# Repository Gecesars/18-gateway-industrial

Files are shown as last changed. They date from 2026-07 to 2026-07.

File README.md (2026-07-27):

# EDGE-18 — Gateway Industrial Modbus/CAN Universal

Plataforma-pai para aquisição industrial e telemetria dos demais projetos do
portfólio. O EDGE-18 lê Modbus RTU, quatro sinais 0–10 V/4–20 mA e quatro
entradas digitais/pulso, conserva dados offline e publica por MQTT/TLS.

> **Estado: revisão digital A congelada para documentação — não fabricar.**
> O esquemático passa no ERC, mas a PCB foi mantida no ponto solicitado pelo
> responsável: 43 ocorrências de DRC e 24 conexões abertas. Os arquivos servem
> para revisão de engenharia e continuidade do desenvolvimento; não constituem
> uma liberação fabril, protótipo validado ou produto certificado.

## Arquitetura P0

| Bloco | Seleção |
|---|---|
| MCU | STM32H563ZIT6, Cortex-M33/TrustZone |
| Ethernet | LAN8742Ai, RMII 10/100 |
| Wi-Fi | ESP32-C3-MINI-1 opcional |
| RS-485 | 2 × ISOW1412 isoladas |
| Analógicas | ADS8684, quatro canais de 16 bits |
| Digitais | 2 × ISO1212, quatro entradas de 24 V |
| CAN | ISO1042 reservado para fase 2 |
| Alimentação | 9–36 Vcc; LM76002 como referência |
| PCB | 180 × 120 mm, quatro camadas |

O MVP é somente de monitoramento. Não possui saídas de comando e não substitui
CLP ou relé de segurança.

## Entregue nesta revisão

- requisitos verificáveis e seis ADRs;
- esquemático KiCad A0 com sete blocos e ERC limpo;
- PCB KiCad de quatro camadas, 180 × 120 mm, com roteamento parcial congelado;
- trilhas de 0,25 a 1,20 mm, sem segmento abaixo de 0,25 mm;
- BOM de 181 posições, pinout de 144 pinos e cálculos elétricos;
- STEP atual da PCB e conjunto paramétrico FreeCAD;
- relatório DRC integral com as pendências conhecidas;
- arquitetura elétrica e de software;
- contratos de configuração e telemetria em JSON Schema;
- exemplos válidos;
- núcleo C17 testável com configuração, Modbus, scheduler, journal, telemetria,
  máquina de estados e manifesto de atualização;
- testes estritos no host e CI;
- quinze vistas técnicas e PDF consolidado.

## Evidência CAD — 15 vistas

Os recortes do esquemático foram exportados em alta resolução e ampliados por
bloco para preservar referências, valores e nomes de redes. As vistas da PCB
mostram deliberadamente o estado congelado, inclusive o roteamento ainda
incompleto.

| | | |
|---|---|---|
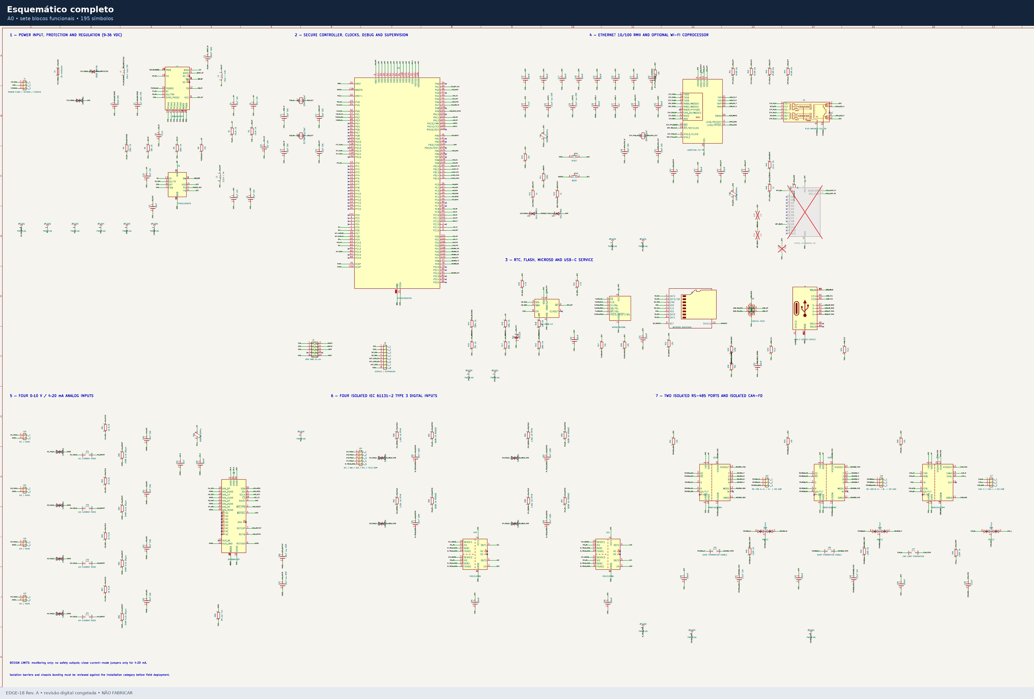
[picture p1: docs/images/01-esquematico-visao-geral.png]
Esquemático completo
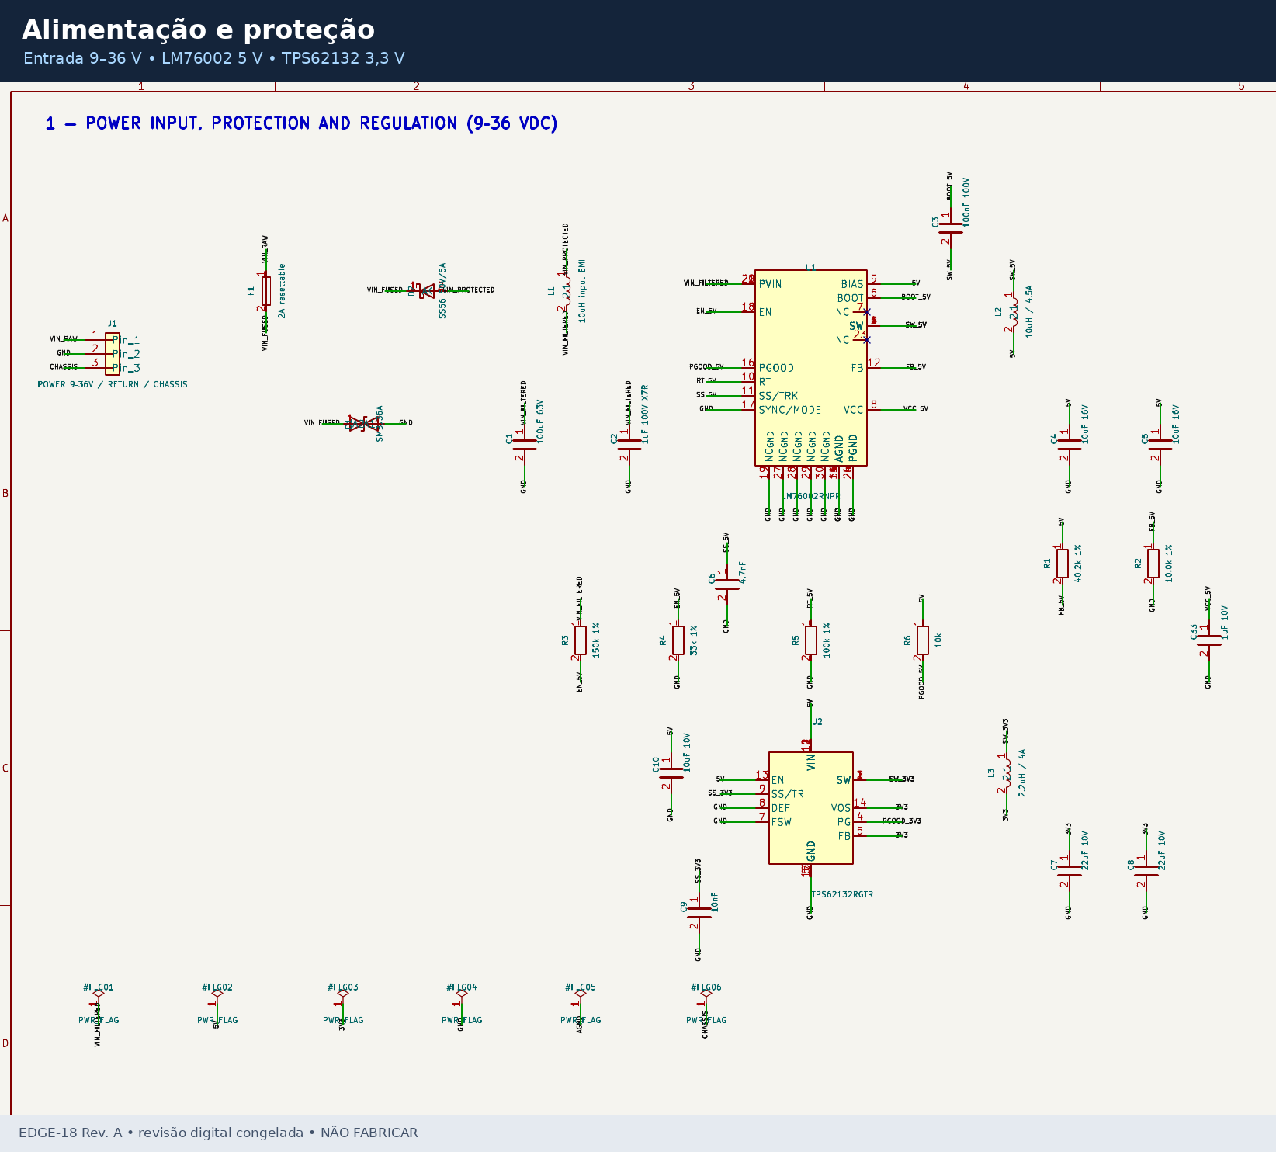
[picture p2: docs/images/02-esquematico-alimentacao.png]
Alimentação
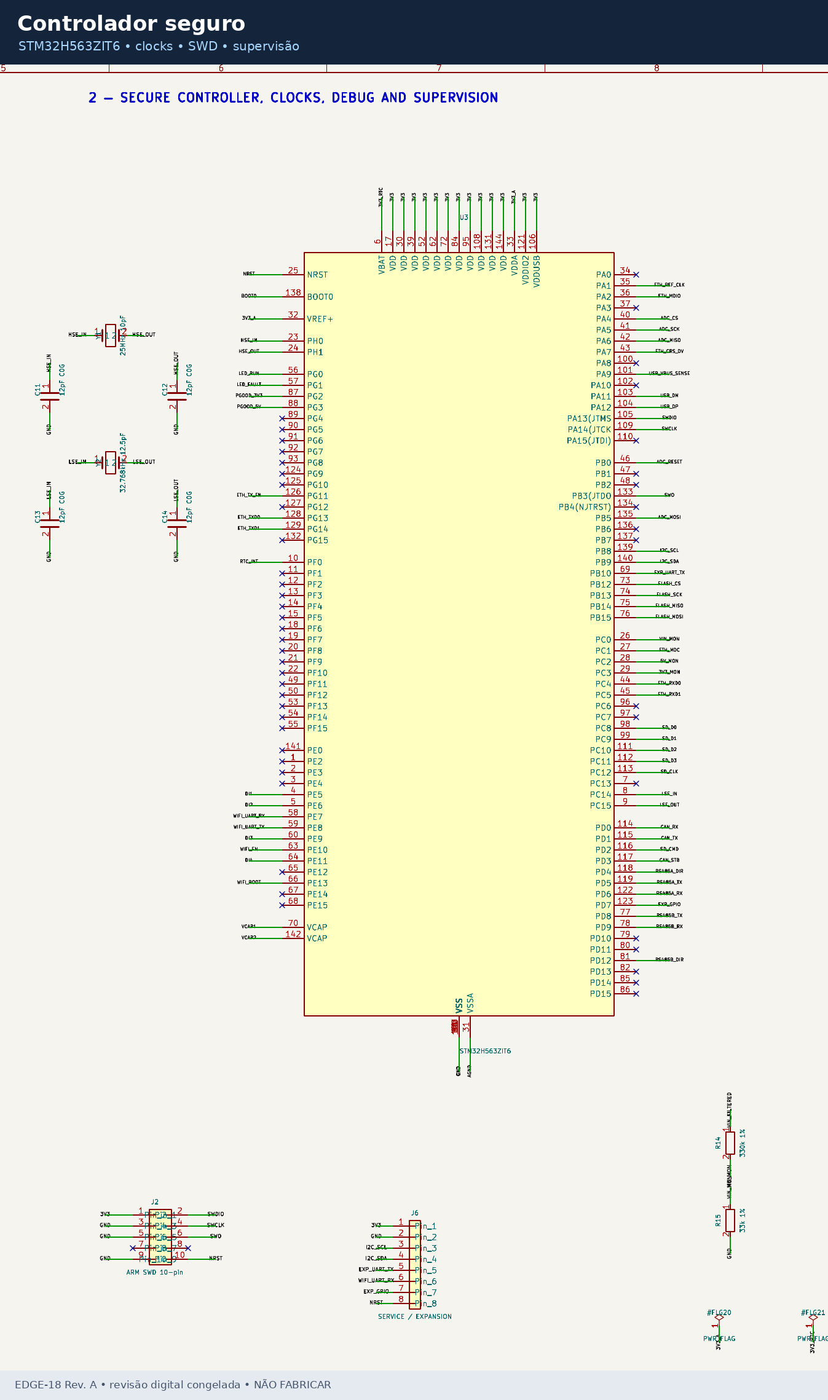
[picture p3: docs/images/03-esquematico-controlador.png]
Controlador
|  |  |  |
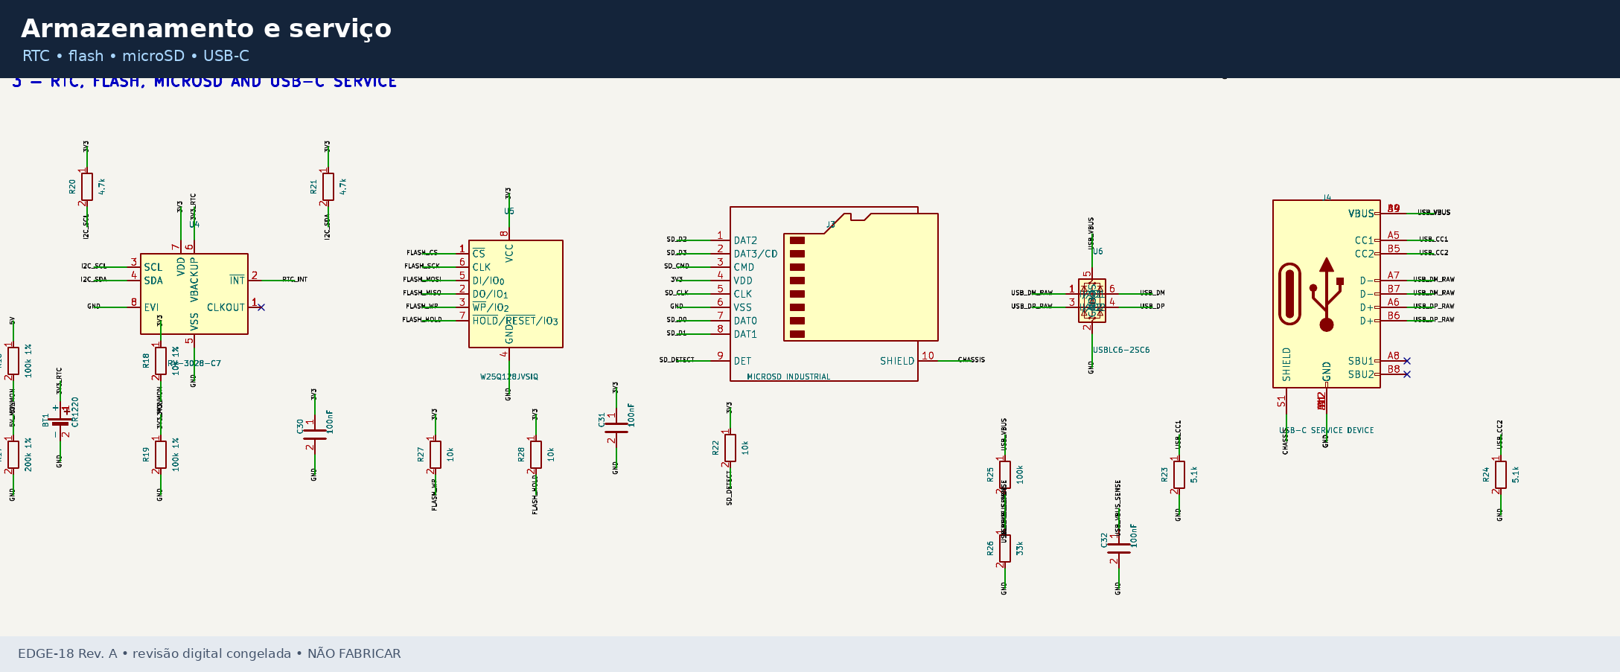
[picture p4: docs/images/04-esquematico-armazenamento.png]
Armazenamento
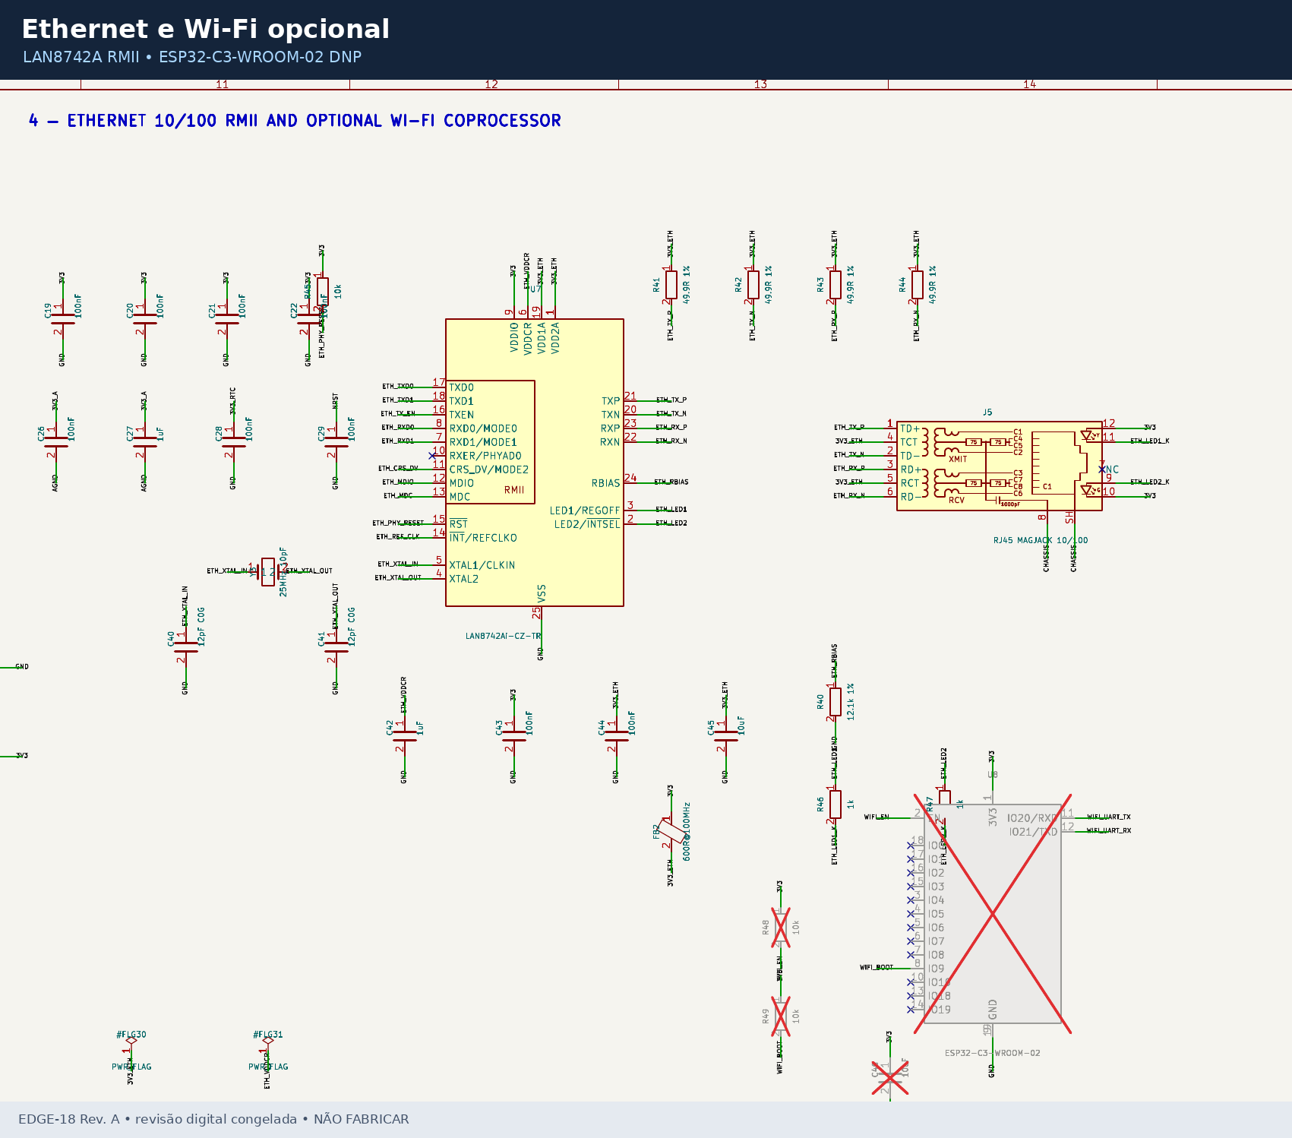
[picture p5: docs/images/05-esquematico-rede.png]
Rede
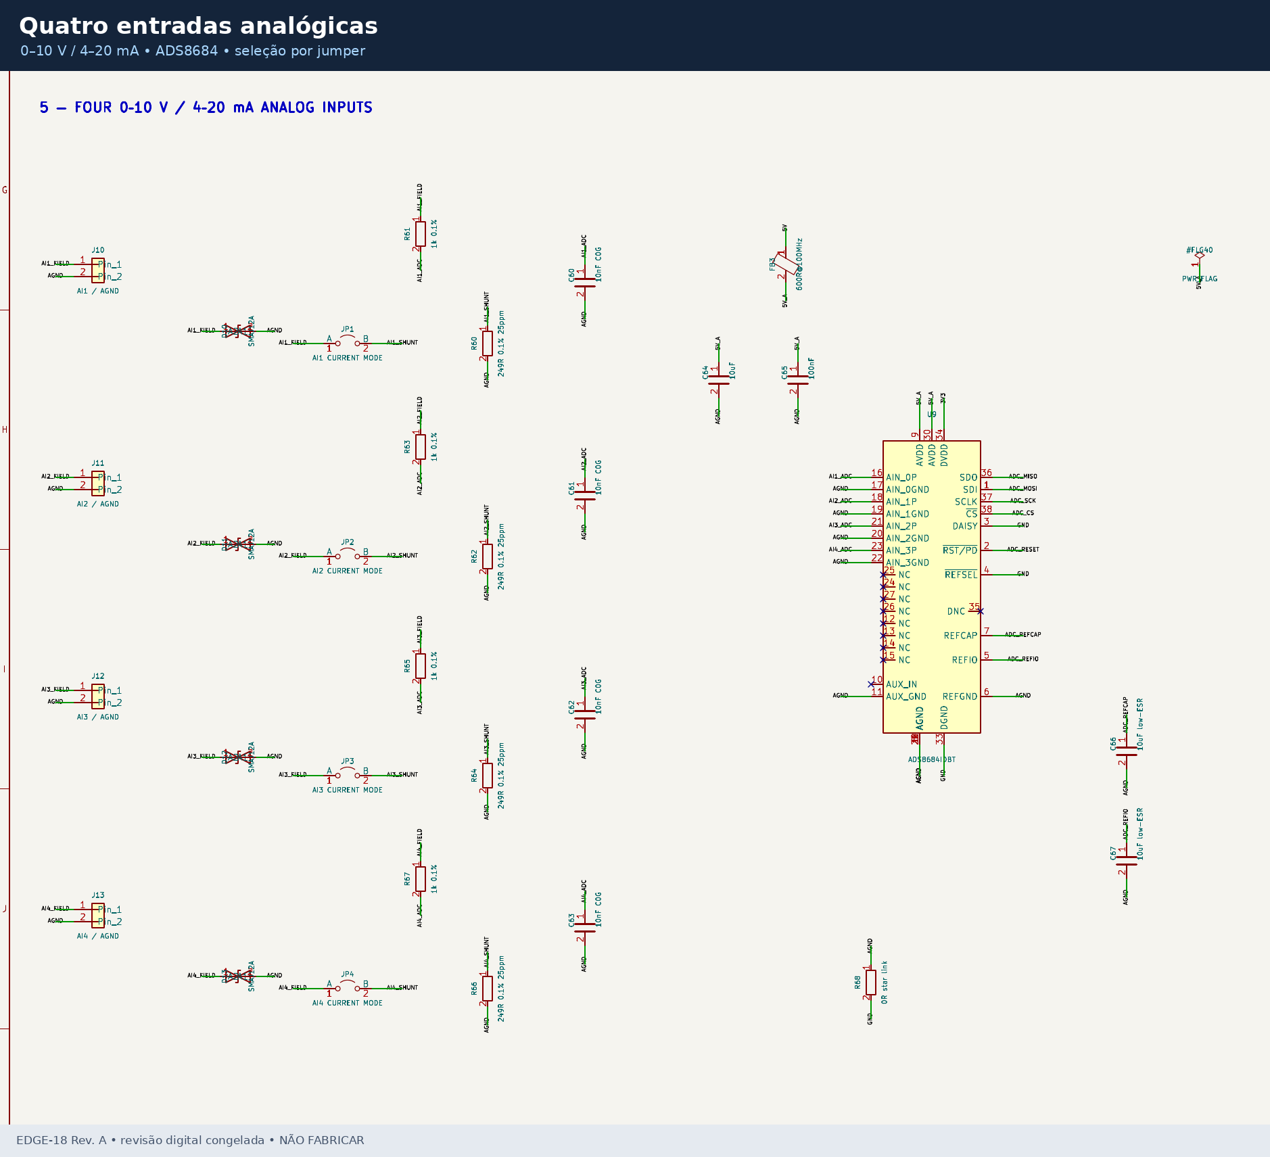
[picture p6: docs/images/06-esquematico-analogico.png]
Entradas analógicas
|  |  |  |
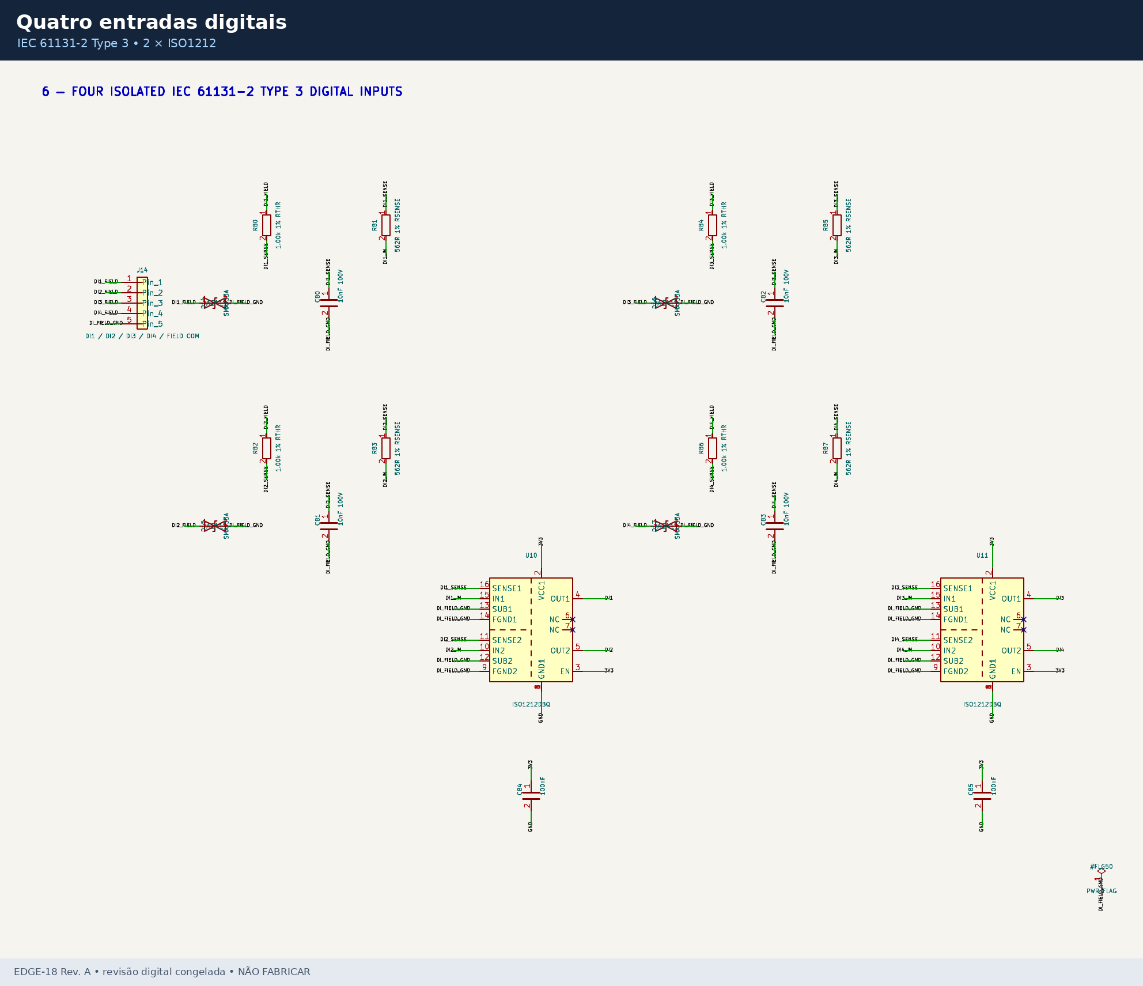
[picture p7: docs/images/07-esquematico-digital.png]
Entradas digitais
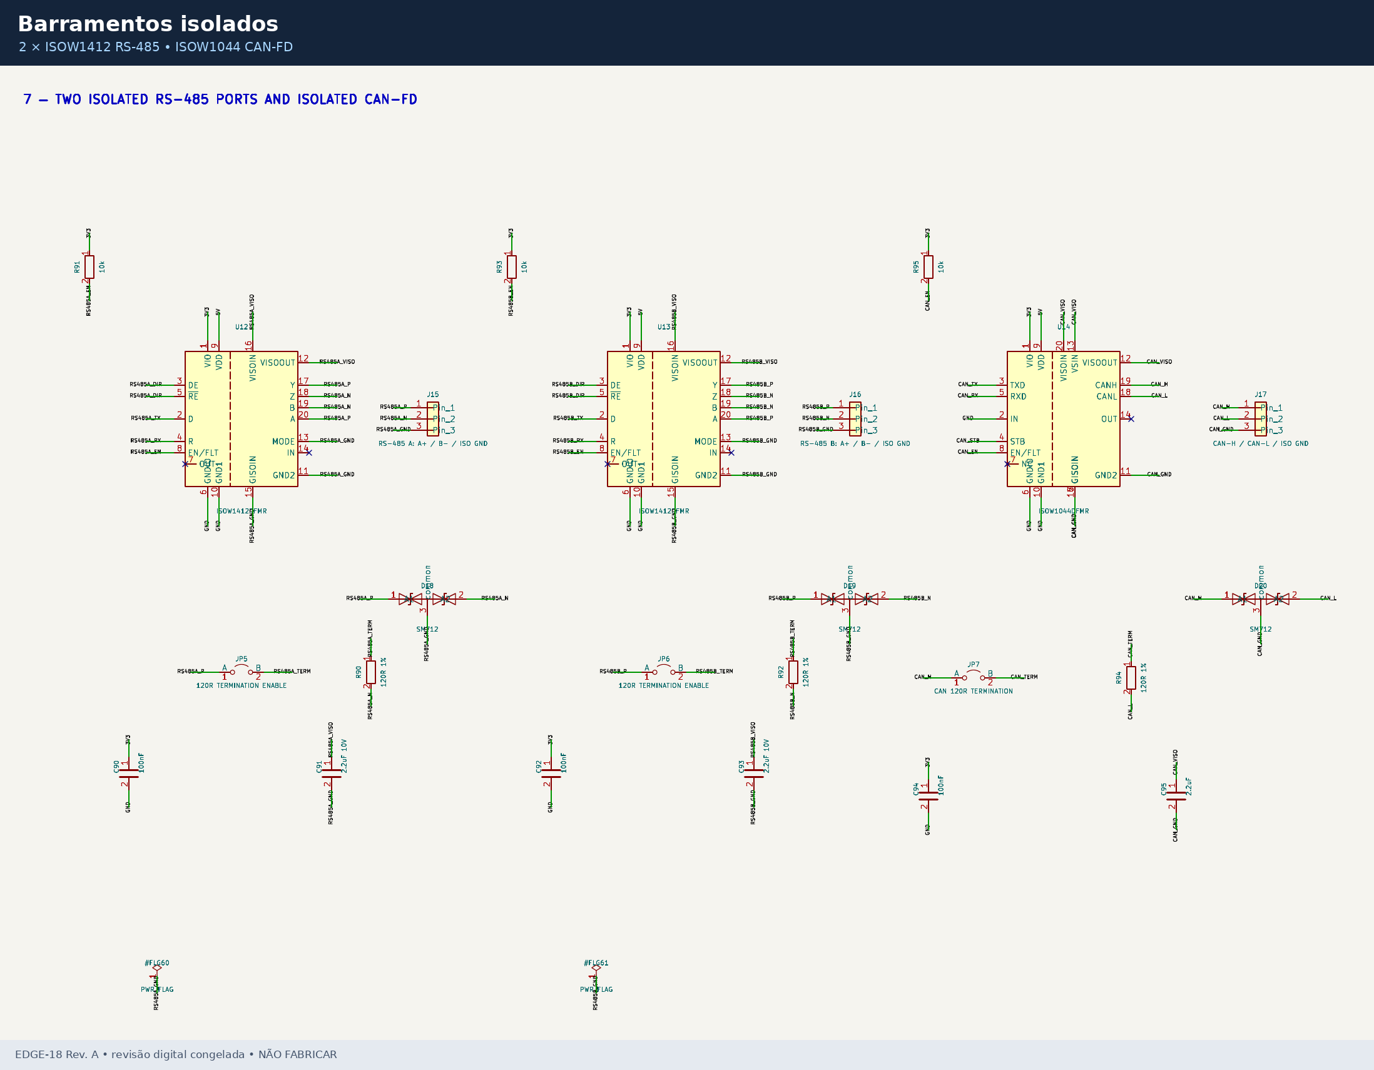
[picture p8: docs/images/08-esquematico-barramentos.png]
Barramentos isolados
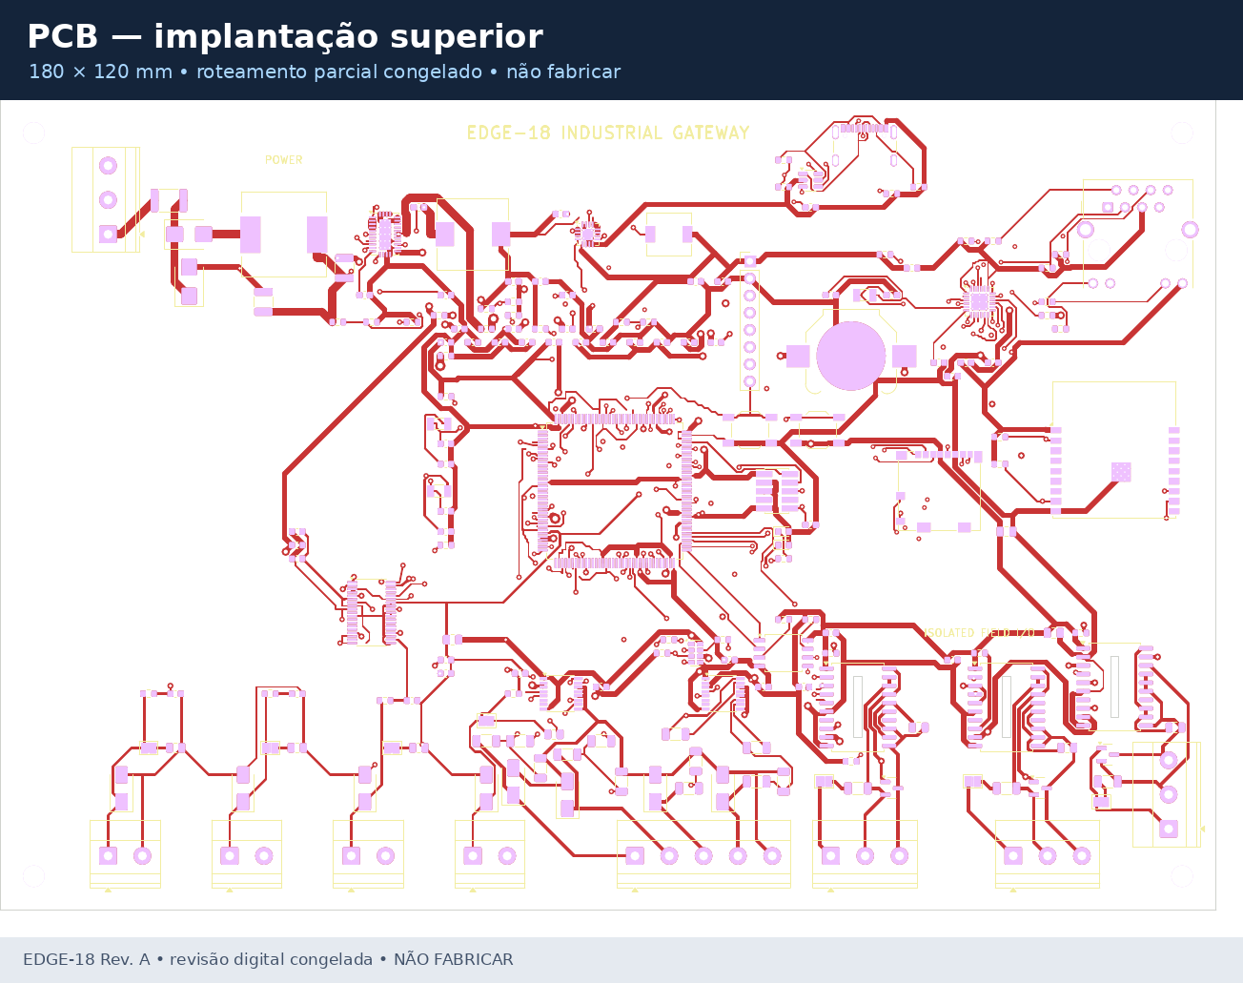
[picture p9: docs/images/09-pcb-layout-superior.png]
Implantação superior
|  |  |  |
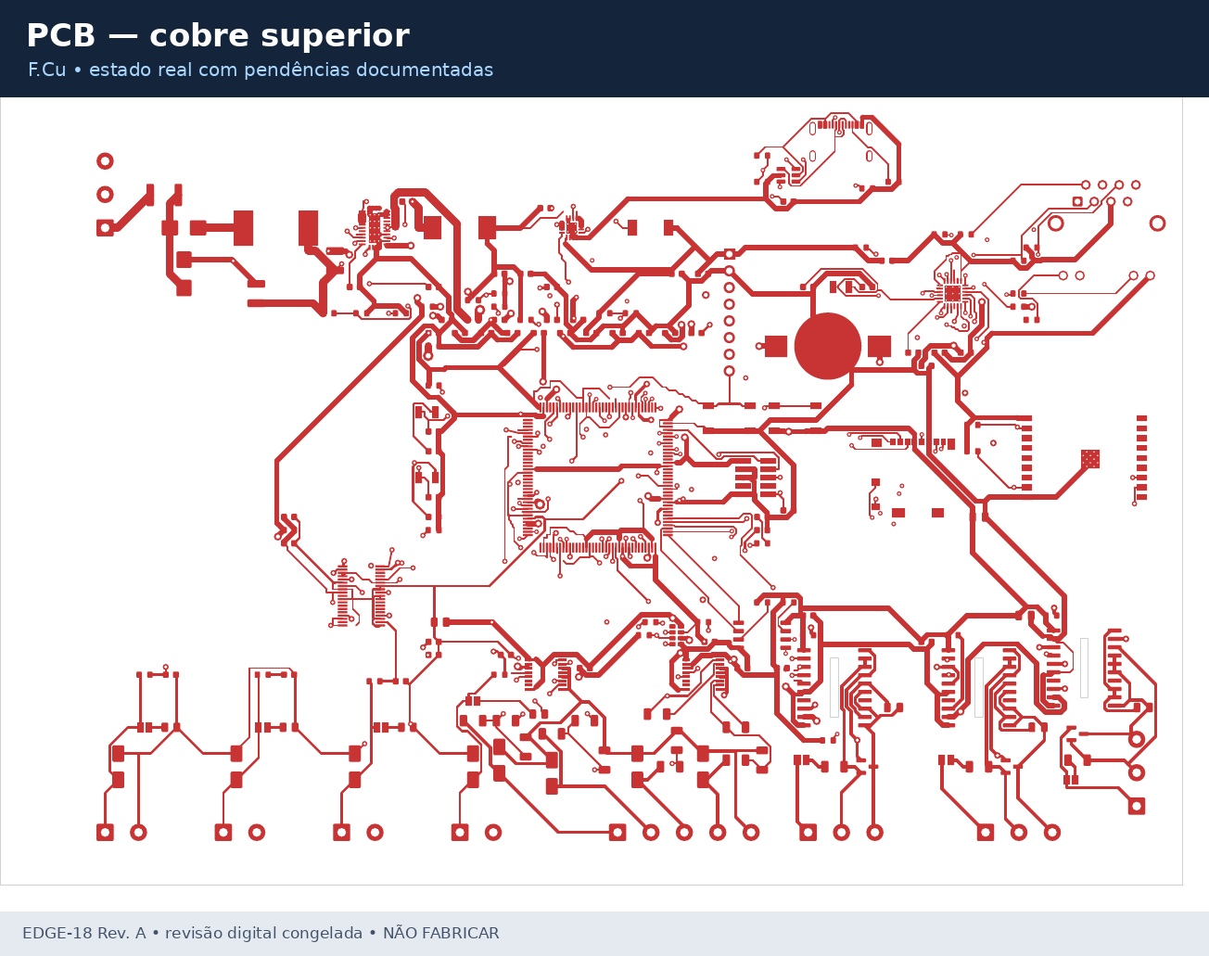
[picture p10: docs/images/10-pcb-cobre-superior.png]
Cobre superior
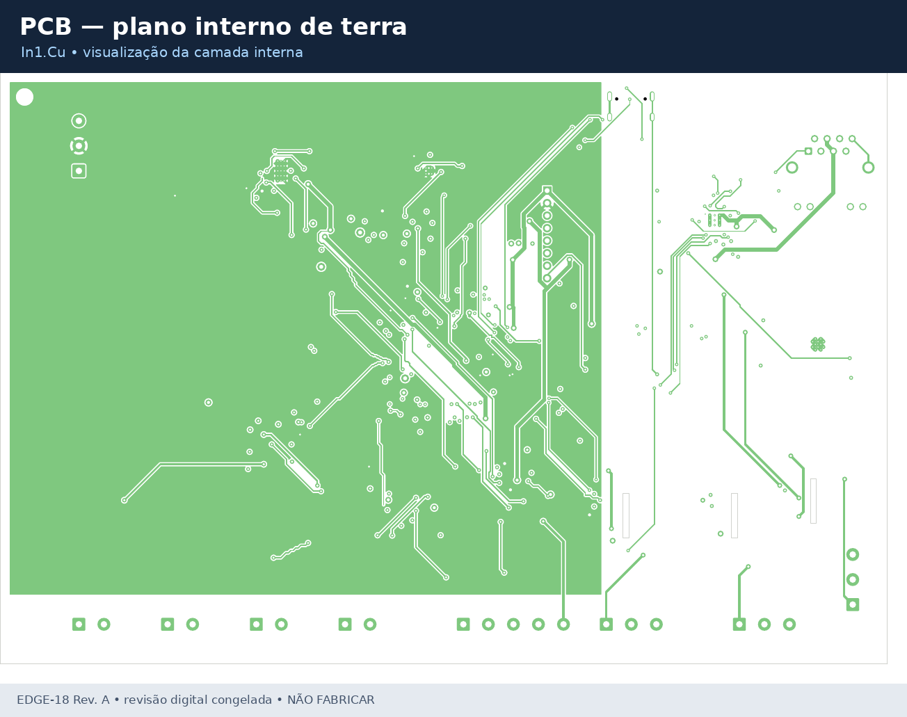
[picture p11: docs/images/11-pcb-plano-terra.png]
Plano interno de terra
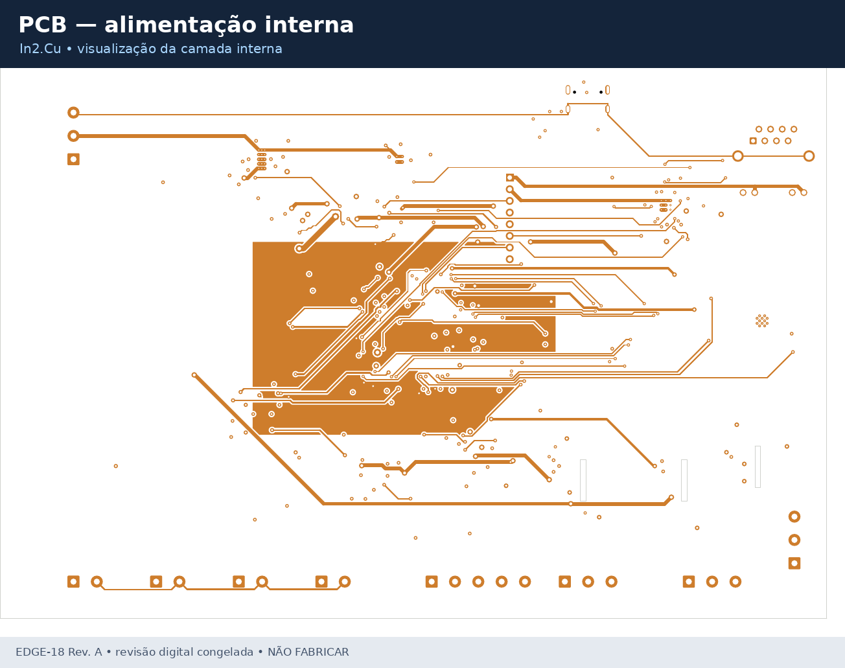
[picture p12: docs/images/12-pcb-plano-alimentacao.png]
Plano interno de alimentação
|  |  |  |
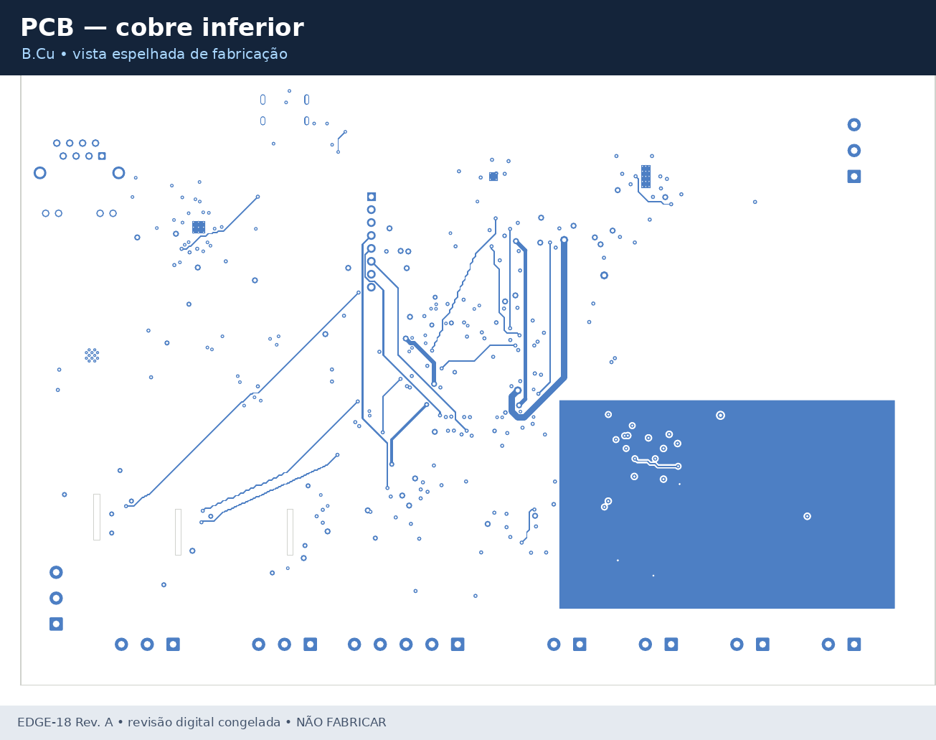
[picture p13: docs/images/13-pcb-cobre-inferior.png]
Cobre inferior
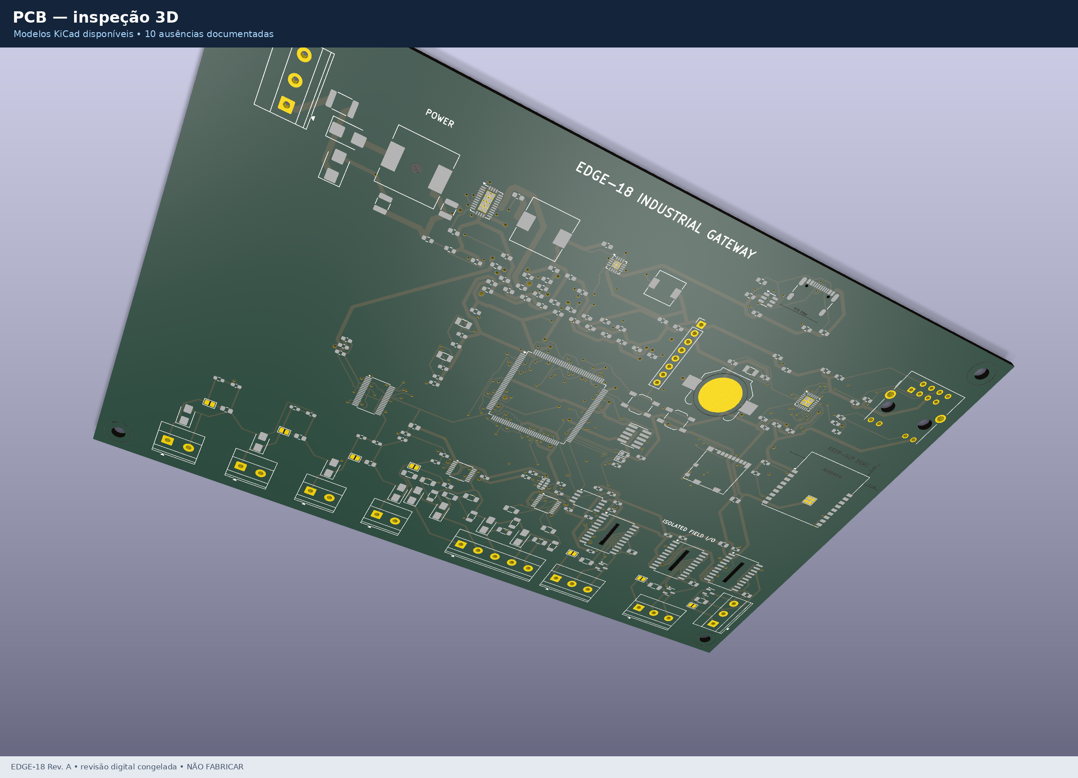
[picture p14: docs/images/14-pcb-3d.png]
PCB em 3D
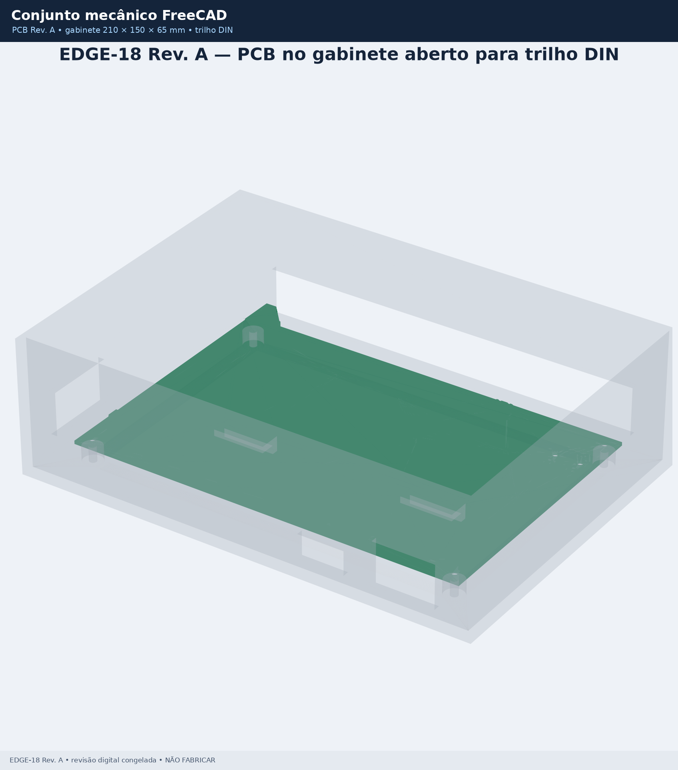
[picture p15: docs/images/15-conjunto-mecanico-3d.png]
Conjunto mecânico
|  |  |  |

Documento consolidado: [EDGE-18 — projeto completo Rev. A](docs/EDGE-18-projeto-completo-rev-a.pdf).

## Verificação local

```bash
./tools/run-checks.sh
```

## Navegação

- [índice técnico](docs/README.md);
- [requisitos](docs/01-requisitos.md);
- [arquitetura](docs/02-arquitetura.md);
- [hardware](docs/03-hardware.md);
- [software](docs/04-software.md);
- [estado congelado da PCB Rev. A](docs/17-estado-da-pcb-rev-a.md);
- [relatório ERC](docs/reports/edge18-main-rev-a-erc.rpt);
- [relatório DRC](docs/reports/edge18-main-rev-a-drc.rpt);
- [fontes primárias](docs/12-fontes-primarias.md);
- [status](project-management/STATUS.md);
- [roadmap](project-management/ROADMAP.md).

## Licença

A licença ainda não foi definida. Não redistribua artefatos como se uma licença
já tivesse sido concedida.

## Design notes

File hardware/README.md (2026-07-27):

# Hardware

## Finalidade

Fontes de eletrônica do projeto.

## Entregáveis Rev. A

- `edge18-main/edge18-main-rev-a.kicad_sch`: esquemático A0 com sete blocos;
- `edge18-main/edge18-main-rev-a.kicad_pcb`: PCB 180 × 120 mm, quatro camadas;
- `libraries/frozen/`: símbolos resolvidos e congelados para ERC reprodutível;
- `bom/edge18-main-rev-a-source.csv`: 181 posições e quatro DNP;
- `scripts/generate_kicad.py`: fonte determinística de esquemático, PCB inicial
  e BOM;
- `scripts/generate_pinout.py`: tabela dos 144 pinos extraída do CAD;
- `scripts/specctra_io.py`: intercâmbio DSN/SES;
- relatórios ERC/DRC em `docs/reports/`.

## Regras principais

- trilha mínima global: 0,25 mm;
- padrão: 0,30 mm; analógico: 0,35 mm; campo: 0,50 mm;
- alimentação: 0,80 mm; VIN: 1,20 mm;
- quatro camadas: F.Cu, In1.Cu, In2.Cu e B.Cu;
- três rasgos sob as barreiras isoladas;
- ESP32-C3-WROOM-02 marcado DNP;
- nenhuma saída de controle de processo.

## Estado congelado

A PCB Rev. A foi congelada em 27 de julho de 2026 com 43 ocorrências de DRC e
24 conexões abertas, por decisão do responsável. Não retome o roteamento nem
gere arquivos fabris a partir desta baseline sem nova autorização. O
esquemático tem ERC limpo e não há trilha abaixo de 0,25 mm.

Detalhes: [`../docs/17-estado-da-pcb-rev-a.md`](../docs/17-estado-da-pcb-rev-a.md).

## Regeneração e validação de desenvolvimento

```bash
./tools/generate-hardware.sh
./tools/kicad-cli.sh sch erc \
  --exit-code-violations hardware/edge18-main/edge18-main-rev-a.kicad_sch
./tools/kicad-cli.sh pcb drc \
  --exit-code-violations hardware/edge18-main/edge18-main-rev-a.kicad_pcb
```

`generate-hardware.sh` substitui o PCB pelo posicionamento inicial; execute o
roteamento depois dele somente em uma futura linha de desenvolvimento
autorizada. `--schematic-only` atualiza esquemático, BOM e bibliotecas sem tocar
na PCB congelada; `--bom-only` atualiza somente a BOM.

## Limite da liberação

O ERC está limpo, mas o DRC não está. A revisão atual não pode ser fabricada.
Protótipo, DFM, bring-up, térmica, surto, EMC e isolamento também continuam
pendentes.

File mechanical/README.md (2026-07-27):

# Mecânica EDGE-18

## Rev. A digital

- gabinete: 210 × 150 × 65 mm;
- PCB: 180 × 120 × 1,6 mm;
- quatro pontos de fixação M3;
- tampa removível;
- aberturas para Ethernet, USB, alimentação e terminais;
- dois adaptadores inferiores para trilho DIN;
- importação do STEP real da PCB quando o pacote de release está presente;
- volumes funcionais para fonte, analógicas, digitais, MCU, barramentos,
  Ethernet e keep-out da antena.

Fontes:

- `source/generate_edge18_enclosure.py`;
- `source/validate_edge18_enclosure.py`;
- `native/edge18-rev-a-assembly.FCStd`;
- `step/edge18-main-rev-a.step` (exportação da PCB KiCad congelada);
- `step/edge18-rev-a-*.step`.

Regeneração:

```bash
./tools/generate-mechanical.sh
```

O modelo confere envelope, fixações, recortes e conjunto PCB/gabinete. Parafusos,
torques, junta, grau IP, dissipação e desenho de oficina dependem do protótipo e
do processo de fabricação escolhido.

Dez referências de modelos 3D não estão disponíveis na biblioteca KiCad local
e são omitidas na exportação atual. A lista e o impacto estão documentados em
[`../docs/17-estado-da-pcb-rev-a.md`](../docs/17-estado-da-pcb-rev-a.md).

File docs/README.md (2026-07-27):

# Índice documental — Projeto 18

1. [Proposta de origem](00-proposta.md)
2. [Requisitos](01-requisitos.md)
3. [Arquitetura](02-arquitetura.md)
4. [Hardware](03-hardware.md)
5. [Software](04-software.md)
6. [Interfaces e dados](05-interfaces-e-dados.md)
7. [Segurança e conformidade](06-seguranca-e-conformidade.md)
8. [Verificação e validação](07-verificacao-e-validacao.md)
9. [Fabricação e implantação](08-fabricacao-e-implantacao.md)
10. [Operação e manutenção](09-operacao-e-manutencao.md)
11. [Controle documental](10-controle-documental.md)
12. [Reutilização pelos projetos filhos](11-reutilizacao.md)
13. [Fontes primárias e seleção](12-fontes-primarias.md)
14. [Pinout STM32H563 Rev. A](13-pinout-stm32h563-rev-a.md)
15. [Modelo de ameaças](14-modelo-de-ameacas.md)
16. [Cálculos elétricos](15-calculos-eletricos.md)
17. [BOM e montagem](16-bom-e-montagem.md)
18. [Estado congelado da PCB Rev. A](17-estado-da-pcb-rev-a.md)

Relatórios gerados:

- [ERC Rev. A](reports/edge18-main-rev-a-erc.rpt);
- [DRC Rev. A](reports/edge18-main-rev-a-drc.rpt).

O estado vivo do projeto fica em [`../project-management/`](../project-management/).

Decisões arquiteturais ficam em [`decisions/`](decisions/).

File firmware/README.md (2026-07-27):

# Firmware EDGE-18

## Estado

O núcleo C17 independente da HAL está implementado e testado no host:

- modelo fixo de ponto, máscara de qualidade e identificadores;
- fila limitada com políticas de overflow e métricas;
- validação semântica de tabelas de dispositivos e pontos;
- framing, CRC, validação e decodificação Modbus RTU;
- escalonador periódico com fase, backoff exponencial e saturação;
- journal binário com CRC, marcador de commit e recuperação de escrita
  interrompida;
- serialização limitada do envelope `edge.telemetry/1`;
- máquina de estados de boot, provisão, rede, degradação e atualização;
- validação de manifesto com alvo, tamanho, contador anti-rollback, digest e
  callback criptográfico.

A porta STM32H563 (HAL, FreeRTOS, LwIP, mbedTLS, FatFs e drivers de placa) é uma
camada separada e continua dependente de teste na PCB física. O código deste
diretório não simula que a integração eletroeletrônica já foi ensaiada.

## Build no computador

```bash
cmake -S .. -B ../build/host -DCMAKE_BUILD_TYPE=Debug
cmake --build ../build/host
ctest --test-dir ../build/host --output-on-failure
```

## Integração no STM32H563

As APIs de `include/edge` não dependem da HAL. A porta de alvo deve fornecer:

1. clock, MPU/TrustZone, RNG, RTC e IWDG;
2. FreeRTOS e supervisor que é o único alimentador do watchdog;
3. UART + DE das duas portas RS-485;
4. SPI do ADS8684, flash e microSD;
5. RMII/LwIP, mbedTLS e MQTT QoS 1;
6. armazenamento em bloco que grave o marcador de commit por último;
7. verificação real de assinatura no callback de `update_manifest`.

Não há alocação dinâmica no caminho de aquisição do núcleo.

O mapa de placa e a sequência de inicialização estão em
`platform/stm32h563/`.

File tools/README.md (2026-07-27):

# Ferramentas locais

Os scripts deste diretório mantêm todas as dependências pesadas na partição
`/mnt/eftx-data`. Os caminhos podem ser substituídos com `EDGE18_TOOL_ROOT`.

- `generate-hardware.sh`: recria esquemático, PCB inicial e BOM de fonte;
  `--schematic-only` preserva a PCB congelada e `--bom-only` preserva ambos os
  CAD nativos.
- `kicad-cli.sh`: executa o KiCad 9 no ambiente local isolado.
- `route-board.sh`: exporta DSN, roteia com Freerouting, reimporta SES e
  recalcula os planos; não executar na baseline congelada sem nova autorização.
- `fill-zones.sh`: recalcula zonas de cobre de forma headless.
- `generate-mechanical.sh`: recria os arquivos mecânicos no FreeCAD.
- `generate-images.sh`: exporta e valida exatamente 15 imagens documentais de
  esquemático, camadas do PCB e modelos 3D.
- `generate-project-pdf.sh`: consolida documentação, decisões, gestão e as 15
  imagens em um PDF A4 paginado.
- `export-release.sh`: exige ERC/DRC limpos e exporta Gerbers, furação, IPC-D-356,
  posição, BOM, PDFs, STEP, hashes e ZIP da Rev. A.
- `validate_review.py`: valida sem KiCad/FreeCAD os artefatos commitados e o
  estado congelado esperado de 43 DRC/24 conexões.
- `generate-review-manifest.sh`: gera hashes SHA-256 do CAD, firmware,
  documentação visual, relatórios e modelos mecânicos entregues.
- `validate_release.py`: valida um futuro pacote fabril somente quando existir
  e estiver com ERC/DRC limpos.
- `run-checks.sh`: schemas, links, build/testes C17, revisão congelada e modelo
  mecânico.

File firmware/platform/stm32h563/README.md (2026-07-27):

# Porta STM32H563 — EDGE-18 Rev. A

## Contrato

`board_pins.h` espelha as nets ligadas ao U3 no KiCad. O alvo deve ser criado
para `STM32H563ZIT6`, LQFP-144, com:

- HSE de 25 MHz e LSE de 32,768 kHz;
- SYSCLK/HCLK de até 250 MHz;
- clock USB de 48 MHz e RMII de 50 MHz conforme árvore validada;
- I-cache, MPU e TrustZone configurados antes da aplicação;
- IWDG alimentado somente pelo supervisor;
- RNG usado para boot ID, TLS e nonces;
- SWD preservado na fabricação.

## Ordem de inicialização

1. ler causa de reset e manter saídas de controle inexistentes;
2. clock, alimentação e cache;
3. MPU/TrustZone e proteção de chaves;
4. GPIO em estados seguros;
5. RTC, monotônico e watchdog;
6. SPI/SDMMC/UART/FDCAN/RMII/USB;
7. recuperar configuração e journal;
8. iniciar FreeRTOS;
9. self-test e promoção para `running` ou `degraded`.

## Regras de drivers

- UART RS-485 sempre tem timeout, controle DE e drenagem do último stop bit;
- DMA não aponta para memória liberada ou stack expirada;
- SDMMC grava payload/CRC antes do marcador de commit;
- falha do microSD mantém aquisição com qualidade `STORAGE_DEGRADED`;
- CAN permanece standby no MVP;
- Wi-Fi fica em reset quando os quatro itens DNP não estão montados;
- erro de clock, PGOOD ou self-test impede publicação de telemetria como boa.

## Geração do projeto

O projeto STM32CubeIDE/CMake de alvo deve ser gerado a partir do pinout
normativo e fixar a versão do STM32CubeH5. Arquivos gerados pelo Cube não são
forjados neste repositório sem a ferramenta e sem build ARM reproduzível.
O núcleo em `firmware/src` permanece independente da HAL e já é compilado e
testado no host.

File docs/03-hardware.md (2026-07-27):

# Hardware EDGE-18 Rev. A

## 1. Componentes arquiteturais

| Ref. funcional | Componente de referência | Função | Estado |
|---|---|---|---|
| MCU | STM32H563ZIT6, LQFP-144 | autoridade, Ethernet MAC, FDCAN, segurança | selecionado para P0 |
| PHY | LAN8742Ai | Ethernet 10/100 RMII | selecionado para P0 |
| Wi-Fi | ESP32-C3-WROOM-02 | enlace opcional/coprocessador | footprint oficial, DNP por padrão |
| ADC | ADS8684IDBT | 4 canais, 16 bits, faixas até ±10,24 V | selecionado para P0 |
| DI | 2 × ISO1212DBQ | quatro entradas industriais isoladas | selecionado para P0 |
| RS-485 | 2 × ISOW1412 | transceptor e potência isolada | selecionado para P0 |
| CAN | ISOW1044DFMR | CAN/CAN-FD com potência isolada | montado; firmware desabilitado no MVP |
| Buck principal | LM76002 | 9–36 V para 5 V, margem até 60 V no CI | selecionado para cálculo |
| 3,3 V | TPS62132RGTR, 3 A | lógica, PHY e Wi-Fi | selecionado |
| Armazenamento | microSD + W25Q128JVSIQ | fila e atualização | selecionado |
| Serviço | USB-C USB 2.0 FS + SWD 10 pinos | console, recuperação e produção | selecionado |

Nenhum componente está qualificado apenas por aparecer nesta tabela. Footprint,
estoque, lifecycle, térmica, EMC e substitutos precisam ser verificados antes
do gate de fabricação. A BOM de fonte possui 181 itens montáveis, campos de
fabricante/MPN preenchidos e quatro itens DNP.

## 2. Placa e mecânica

- dimensões-alvo: 180 × 120 mm;
- quatro camadas: sinal/componente, plano GND, alimentação/sinal, sinal;
- FR-4 de 1,6 mm; cobre inicial de 1 oz;
- conectores de campo plugáveis, passo mínimo 5,08 mm;
- terminais de campo em uma borda, Ethernet/USB na borda oposta;
- barreiras de isolação sem cobre em todas as camadas;
- quatro furos de montagem M3 sem cobre;
- gabinete-alvo: alumínio 210 × 150 × 65 mm, suporte para trilho DIN;
- antena do ESP32 na borda, com keep-out em cobre e afastamento do gabinete, ou
  variante externa futura se o gabinete metálico exigir.

O conjunto digital está em
`mechanical/native/edge18-rev-a-assembly.FCStd`, com exportações STEP da base,
tampa e conjunto. A revisão mecânica usa quatro fixações M3 e importa o
STEP real da PCB para conferência das aberturas.

## 3. Alimentação

### 3.1 Entrada

1. borne 9–36 Vcc;
2. fusível substituível ou PTC dimensionado;
3. proteção contra inversão por MOSFET/ideal diode;
4. TVS e filtro de modo comum/diferencial definidos por ensaio;
5. LM76002 para 5 V;
6. conversor 3,3 V;
7. supervisão de `VIN`, `5V`, `3V3` e sinal `POWER_GOOD`.

O limite de 60 V do LM76002 não autoriza aplicar 60 V à placa: TVS, MOSFET,
capacitores e demais componentes possuem limites próprios.

### 3.2 Orçamento preliminar

| Bloco | 5 V equivalente, pior caso de projeto |
|---|---:|
| STM32H563 + memórias | 0,30 A |
| Ethernet PHY/magnetics | 0,15 A |
| ESP32-C3 em transmissão | 0,50 A |
| ADC e front-end | 0,10 A |
| isoladores com potência integrada | 0,45 A |
| microSD em pico | 0,25 A |
| USB, LEDs e margem | 0,25 A |
| **Total de projeto** | **2,00 A** |

O LM76002 é nominalmente 2,5 A e o TPS62132, 3 A. Correntes reais ainda devem
ser medidas no primeiro protótipo.

## 4. Entradas analógicas

- o ADS8684 oferece faixas programáveis por canal;
- 0–10 V entra diretamente pelo caminho protegido;
- 4–20 mA usa shunt de 249 Ω, 0,1%, baixa deriva, selecionado fisicamente;
- 4 mA produz 0,996 V e 20 mA produz 4,98 V no shunt;
- cada canal terá proteção, filtro RC e ponto de teste;
- os canais compartilham `AGND_FIELD`;
- a calibração usa pelo menos zero, 25%, 50%, 75% e fundo de escala;
- o firmware armazena ganho, offset, temperatura e instrumento usado.

O shunt não será comutado por chave analógica no P0 para evitar resistência,
leakage e estados ambíguos. Jumper/codificação física deve ser visível ao
firmware por entrada de identificação ou configuração bloqueada.

## 5. Entradas digitais

Dois ISO1212 implementam quatro entradas de 24 V. O circuito de resistores será
calculado para a classe IEC 61131-2 pretendida a partir do datasheet e validado
no EVM/referência. Cada canal terá:

- borne `DIx` e retorno de campo;
- proteção contra inversão e surto;
- LED de campo sem comprometer o limiar;
- saída lógica para GPIO e timer do MCU;
- modo estado/debounce ou pulso rápido;
- ponto de teste somente no lado seguro.

## 6. RS-485

Cada porta possui barreira e alimentação isolada independentes. Em cada uma:

- A/B/GND de campo em borne próprio;
- TVS específica para barramento;
- choke opcional e footprint de ajuste EMC;
- terminação de 120 Ω selecionável;
- polarização selecionável, nunca duplicada por padrão;
- LEDs no lado lógico;
- controle de direção por hardware/periférico quando possível;
- clearances e keep-outs conforme isolamento escolhido.

## 7. Ethernet e Wi-Fi

O LAN8742Ai liga-se ao STM32 por RMII. O projeto inclui cristal/clock conforme
topologia escolhida, resistores de strap, magnetics, RJ45 blindado, ESD e ligação
controlada ao chassi.

O ESP32-C3-WROOM-02:

- é opcional;
- recebe 3,3 V com chaveamento/reset independente;
- comunica por UART de controle;
- não acessa diretamente RS-485, ADC, CAN ou chaves privadas;
- pode ser removido e substituído pela variante com antena externa.

## 8. CAN reservado

O ISOW1044 suporta CAN clássico e CAN-FD com potência isolada integrada. A
Rev. A possui transceptor, TVS, terminação
selecionável e conector, mas o firmware do MVP mantém o periférico desabilitado.
Transmissão futura exigirá requisito, ADR e testes próprios.

## 9. Regras de layout

- pares RMII curtos, impedância e retorno contínuo;
- nenhum sinal cru de campo atravessa a região do MCU;
- SPI do ADC afastado do buck e do módulo Wi-Fi;
- plano analógico controlado e união única documentada;
- keep-out completo sob barreiras;
- capacitores de desacoplamento no mesmo lado e junto ao pino;
- test points para todas as fontes, reset, clocks e barramentos internos;
- serigrafia identifica claramente domínio, tensão e posição de terminação;
- DRC não substitui revisão de creepage, clearance e caminho de retorno.

## 10. Estado digital

O esquemático nativo e o PCB de quatro camadas existem em
`hardware/edge18-main`; o ERC está limpo. O PCB passa por roteamento e DRC antes
do pacote de fabricação. A liberação é uma revisão digital: protótipo,
bring-up, temperatura, imunidade/surto, emissões e validação de isolamento
continuam obrigatórios antes de instalação em campo.

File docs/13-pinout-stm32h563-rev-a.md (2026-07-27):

# Pinout STM32H563ZIT6 — EDGE-18 Rev. A

Tabela gerada diretamente do símbolo congelado e do PCB nativo. `RESERVADO` significa pad sem net nesta revisão; não autoriza uso sem atualizar esquemático, PCB, firmware e análise de conflitos.

| Pino | Nome físico | Net Rev. A | Domínio |
|---:|---|---|---|
| 1 | `PE2` | `RESERVADO` | RESERVADO |
| 2 | `PE3` | `RESERVADO` | RESERVADO |
| 3 | `PE4` | `RESERVADO` | RESERVADO |
| 4 | `PE5` | `DI1` | DIGITAL |
| 5 | `PE6` | `DI2` | DIGITAL |
| 6 | `VBAT` | `3V3_RTC` | ALIMENTAÇÃO |
| 7 | `PC13` | `RESERVADO` | RESERVADO |
| 8 | `PC14` | `LSE_IN` | CLOCK |
| 9 | `PC15` | `LSE_OUT` | CLOCK |
| 10 | `PF0` | `RTC_INT` | RTC |
| 11 | `PF1` | `RESERVADO` | RESERVADO |
| 12 | `PF2` | `RESERVADO` | RESERVADO |
| 13 | `PF3` | `RESERVADO` | RESERVADO |
| 14 | `PF4` | `RESERVADO` | RESERVADO |
| 15 | `PF5` | `RESERVADO` | RESERVADO |
| 16 | `VSS` | `GND` | ALIMENTAÇÃO |
| 17 | `VDD` | `3V3` | ALIMENTAÇÃO |
| 18 | `PF6` | `RESERVADO` | RESERVADO |
| 19 | `PF7` | `RESERVADO` | RESERVADO |
| 20 | `PF8` | `RESERVADO` | RESERVADO |
| 21 | `PF9` | `RESERVADO` | RESERVADO |
| 22 | `PF10` | `RESERVADO` | RESERVADO |
| 23 | `PH0` | `HSE_IN` | CLOCK |
| 24 | `PH1` | `HSE_OUT` | CLOCK |
| 25 | `NRST` | `NRST` | DEBUG |
| 26 | `PC0` | `VIN_MON` | SUPERVISÃO |
| 27 | `PC1` | `ETH_MDC` | ETHERNET |
| 28 | `PC2` | `5V_MON` | SUPERVISÃO |
| 29 | `PC3` | `3V3_MON` | SUPERVISÃO |
| 30 | `VDD` | `3V3` | ALIMENTAÇÃO |
| 31 | `VSSA` | `AGND` | ALIMENTAÇÃO |
| 32 | `VREF+` | `3V3_A` | ALIMENTAÇÃO |
| 33 | `VDDA` | `3V3_A` | ALIMENTAÇÃO |
| 34 | `PA0` | `RESERVADO` | RESERVADO |
| 35 | `PA1` | `ETH_REF_CLK` | ETHERNET |
| 36 | `PA2` | `ETH_MDIO` | ETHERNET |
| 37 | `PA3` | `RESERVADO` | RESERVADO |
| 38 | `VSS` | `GND` | ALIMENTAÇÃO |
| 39 | `VDD` | `3V3` | ALIMENTAÇÃO |
| 40 | `PA4` | `ADC_CS` | ADC |
| 41 | `PA5` | `ADC_SCK` | ADC |
| 42 | `PA6` | `ADC_MISO` | ADC |
| 43 | `PA7` | `ETH_CRS_DV` | ETHERNET |
| 44 | `PC4` | `ETH_RXD0` | ETHERNET |
| 45 | `PC5` | `ETH_RXD1` | ETHERNET |
| 46 | `PB0` | `ADC_RESET` | ADC |
| 47 | `PB1` | `RESERVADO` | RESERVADO |
| 48 | `PB2` | `RESERVADO` | RESERVADO |
| 49 | `PF11` | `RESERVADO` | RESERVADO |
| 50 | `PF12` | `RESERVADO` | RESERVADO |
| 51 | `VSS` | `GND` | ALIMENTAÇÃO |
| 52 | `VDD` | `3V3` | ALIMENTAÇÃO |
| 53 | `PF13` | `RESERVADO` | RESERVADO |
| 54 | `PF14` | `RESERVADO` | RESERVADO |
| 55 | `PF15` | `RESERVADO` | RESERVADO |
| 56 | `PG0` | `LED_RUN` | STATUS |
| 57 | `PG1` | `LED_FAULT` | STATUS |
| 58 | `PE7` | `WIFI_UART_RX` | WI-FI |
| 59 | `PE8` | `WIFI_UART_TX` | WI-FI |
| 60 | `PE9` | `DI3` | DIGITAL |
| 61 | `VSS` | `GND` | ALIMENTAÇÃO |
| 62 | `VDD` | `3V3` | ALIMENTAÇÃO |
| 63 | `PE10` | `WIFI_EN` | WI-FI |
| 64 | `PE11` | `DI4` | DIGITAL |
| 65 | `PE12` | `RESERVADO` | RESERVADO |
| 66 | `PE13` | `WIFI_BOOT` | WI-FI |
| 67 | `PE14` | `RESERVADO` | RESERVADO |
| 68 | `PE15` | `RESERVADO` | RESERVADO |
| 69 | `PB10` | `EXP_UART_TX` | EXPANSÃO |
| 70 | `VCAP` | `VCAP1` | ALIMENTAÇÃO |
| 71 | `VSS` | `GND` | ALIMENTAÇÃO |
| 72 | `VDD` | `3V3` | ALIMENTAÇÃO |
| 73 | `PB12` | `FLASH_CS` | FLASH |
| 74 | `PB13` | `FLASH_SCK` | FLASH |
| 75 | `PB14` | `FLASH_MISO` | FLASH |
| 76 | `PB15` | `FLASH_MOSI` | FLASH |
| 77 | `PD8` | `RS485B_TX` | RS-485 B |
| 78 | `PD9` | `RS485B_RX` | RS-485 B |
| 79 | `PD10` | `RESERVADO` | RESERVADO |
| 80 | `PD11` | `RESERVADO` | RESERVADO |
| 81 | `PD12` | `RS485B_DIR` | RS-485 B |
| 82 | `PD13` | `RESERVADO` | RESERVADO |
| 83 | `VSS` | `GND` | ALIMENTAÇÃO |
| 84 | `VDD` | `3V3` | ALIMENTAÇÃO |
| 85 | `PD14` | `RESERVADO` | RESERVADO |
| 86 | `PD15` | `RESERVADO` | RESERVADO |
| 87 | `PG2` | `PGOOD_3V3` | SUPERVISÃO |
| 88 | `PG3` | `PGOOD_5V` | SUPERVISÃO |
| 89 | `PG4` | `RESERVADO` | RESERVADO |
| 90 | `PG5` | `RESERVADO` | RESERVADO |
| 91 | `PG6` | `RESERVADO` | RESERVADO |
| 92 | `PG7` | `RESERVADO` | RESERVADO |
| 93 | `PG8` | `RESERVADO` | RESERVADO |
| 94 | `VSS` | `GND` | ALIMENTAÇÃO |
| 95 | `VDD` | `3V3` | ALIMENTAÇÃO |
| 96 | `PC6` | `RESERVADO` | RESERVADO |
| 97 | `PC7` | `RESERVADO` | RESERVADO |
| 98 | `PC8` | `SD_D0` | MICROSD |
| 99 | `PC9` | `SD_D1` | MICROSD |
| 100 | `PA8` | `RESERVADO` | RESERVADO |
| 101 | `PA9` | `USB_VBUS_SENSE` | USB |
| 102 | `PA10` | `RESERVADO` | RESERVADO |
| 103 | `PA11` | `USB_DM` | USB |
| 104 | `PA12` | `USB_DP` | USB |
| 105 | `PA13(JTMS` | `SWDIO` | DEBUG |
| 106 | `VDDUSB` | `3V3` | ALIMENTAÇÃO |
| 107 | `VSS` | `GND` | ALIMENTAÇÃO |
| 108 | `VDD` | `3V3` | ALIMENTAÇÃO |
| 109 | `PA14(JTCK` | `SWCLK` | DEBUG |
| 110 | `PA15(JTDI)` | `RESERVADO` | RESERVADO |
| 111 | `PC10` | `SD_D2` | MICROSD |
| 112 | `PC11` | `SD_D3` | MICROSD |
| 113 | `PC12` | `SD_CLK` | MICROSD |
| 114 | `PD0` | `CAN_RX` | CAN |
| 115 | `PD1` | `CAN_TX` | CAN |
| 116 | `PD2` | `SD_CMD` | MICROSD |
| 117 | `PD3` | `CAN_STB` | CAN |
| 118 | `PD4` | `RS485A_DIR` | RS-485 A |
| 119 | `PD5` | `RS485A_TX` | RS-485 A |
| 120 | `VSS` | `GND` | ALIMENTAÇÃO |
| 121 | `VDDIO2` | `3V3` | ALIMENTAÇÃO |
| 122 | `PD6` | `RS485A_RX` | RS-485 A |
| 123 | `PD7` | `EXP_GPIO` | EXPANSÃO |
| 124 | `PG9` | `RESERVADO` | RESERVADO |
| 125 | `PG10` | `RESERVADO` | RESERVADO |
| 126 | `PG11` | `ETH_TX_EN` | ETHERNET |
| 127 | `PG12` | `RESERVADO` | RESERVADO |
| 128 | `PG13` | `ETH_TXD0` | ETHERNET |
| 129 | `PG14` | `ETH_TXD1` | ETHERNET |
| 130 | `VSS` | `GND` | ALIMENTAÇÃO |
| 131 | `VDD` | `3V3` | ALIMENTAÇÃO |
| 132 | `PG15` | `RESERVADO` | RESERVADO |
| 133 | `PB3(JTDO` | `SWO` | DEBUG |
| 134 | `PB4(NJTRST)` | `RESERVADO` | RESERVADO |
| 135 | `PB5` | `ADC_MOSI` | ADC |
| 136 | `PB6` | `RESERVADO` | RESERVADO |
| 137 | `PB7` | `RESERVADO` | RESERVADO |
| 138 | `BOOT0` | `BOOT0` | DEBUG |
| 139 | `PB8` | `I2C_SCL` | I²C |
| 140 | `PB9` | `I2C_SDA` | I²C |
| 141 | `PE0` | `RESERVADO` | RESERVADO |
| 142 | `VCAP` | `VCAP2` | ALIMENTAÇÃO |
| 143 | `VSS` | `GND` | ALIMENTAÇÃO |
| 144 | `VDD` | `3V3` | ALIMENTAÇÃO |

## Controle

- encapsulamento: LQFP-144, passo 0,50 mm;
- pads com net atribuída: 95;
- pads reservados: 49;
- RMII, SWD e alimentação têm prioridade sobre expansões;
- as funções alternativas devem ser reproduzidas no projeto STM32Cube/HAL e conferidas no build do alvo;
- a fonte normativa elétrica continua sendo o esquemático e o PCB da Rev. A.

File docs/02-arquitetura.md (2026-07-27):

# Arquitetura EDGE-18

## 1. Decisão principal

O STM32H563ZIT6 é a autoridade do equipamento: adquire, valida, registra e
decide o que pode sair da unidade. Ethernet é nativa ao MCU por RMII. O
ESP32-C3-WROOM-02 é um coprocessador opcional de Wi-Fi e nunca armazena a raiz de
identidade do produto. Ausência, reset ou comprometimento do módulo Wi-Fi não
interrompe a aquisição cabeada.

## 2. Diagrama de blocos

```text
  9–36 Vdc
      │
  proteção + LM76002 ── 5 V ── 3,3 V ─────────────────────────────┐
      │                                                           │
      │     ┌──────────────── STM32H563ZIT6 ────────────────┐      │
      │     │ TrustZone / FreeRTOS / watchdog / RTC         │      │
      │     │                                                │      │
      │     │ SPI1 ─ ADS8684 ─ AI1..AI4 0–10 V / 4–20 mA    │      │
      │     │ GPIO/TIM ─ 2× ISO1212 ─ DI1..DI4 / pulso      │      │
      │     │ UART ─ ISOW1412 ─ RS485-A                     │      │
      │     │ UART ─ ISOW1412 ─ RS485-B                     │      │
      │     │ FDCAN ─ ISOW1044 ─ CAN/CAN-FD (fase 2)       │      │
      │     │ RMII ─ LAN8742A ─ magnetics/RJ45              │      │
      │     │ UART ─ ESP32-C3-WROOM-02 (opcional/DNP)       │      │
      │     │ SDMMC ─ microSD; SPI ─ flash de staging       │      │
      │     │ USB FS ─ USB-C de serviço; SWD de produção    │      │
      │     └────────────────────────────────────────────────┘      │
      └─────────────────────────────────────────────────────────────┘
```

## 3. Domínios elétricos

| Domínio | Referência | Observação |
|---|---|---|
| lógica | `GND` | MCU, Ethernet, USB, armazenamento e Wi-Fi |
| analógico | `AGND` | quatro AI compartilham referência; união por `R68` 0 Ω |
| RS-485 A | `RS485A_GND` | barreira e potência isolada no ISOW1412 |
| RS-485 B | `RS485B_GND` | barreira e potência isolada no ISOW1412 |
| CAN | `CAN_GND` | barreira e potência isolada no ISOW1044 |
| entradas digitais | `DI_FIELD_GND` | lado de campo comum dos dois ISO1212 |
| chassi | `CHASSIS` | ligação controlada a blindagens e gabinete |

`AGND` e `GND` são unidos somente em `R68`, junto ao ADC. Essa união não deve
ser confundida com isolação de canal. Os três transceptores isolados possuem
rasgo mecânico sob a barreira e zona sem cobre própria.

## 4. Partições de firmware

```text
secure boot / identidade / verificação de imagem
                         │
HAL ─ drivers ─ aquisição ─ modelo de pontos ─ regras somente leitura
                         │                 │
                         ├─ fila RAM ─ armazenamento persistente
                         │                 │
                         └─ publicador ─ MQTT/TLS ─ broker
                                           │
configuração validada ─ staging ─ commit ──┘
```

### 4.1 Camada segura

- boot verificado;
- identidade e material criptográfico;
- política de debug;
- contador de rollback e versão mínima;
- verificação da configuração antes da promoção.

### 4.2 Núcleo determinístico

- relógio monotônico;
- planejador de leituras;
- drivers sem alocação dinâmica depois do boot;
- qualidade de ponto;
- watchdog e supervisão de tarefas;
- fila em RAM com pressão de retorno explícita.

### 4.3 Serviços

- armazenamento em microSD;
- Ethernet/LwIP;
- mbedTLS;
- MQTT;
- NTP/DNS/DHCP;
- configuração REST local;
- ponte para o coprocessador Wi-Fi.

## 5. Fluxo de configuração

1. receber documento em área de staging;
2. verificar autenticação, tamanho, hash e versão do schema;
3. validar sintaxe e semântica;
4. construir nova tabela de dispositivos/pontos fora da tabela ativa;
5. verificar recursos, conflitos e limites;
6. gravar cópia persistente com CRC/hash;
7. trocar ponteiro ativo em transação curta;
8. manter última versão válida para rollback;
9. registrar autor, origem, versão e resultado.

## 6. Fluxo de telemetria

1. driver entrega amostra bruta e diagnóstico;
2. conversor aplica tipo, endian, escala e calibração;
3. validador atribui qualidade;
4. ponto recebe timestamp monotônico e UTC quando confiável;
5. política de mudança/período decide registrar;
6. registro entra na fila persistente;
7. publicador atribui `message_id`;
8. confirmação QoS remove o item elegível;
9. métricas registram atraso, repetição e descarte.

## 7. Reutilização pelos projetos filhos

O EDGE-18 publicará três contratos versionados:

- `edge-hal`: relógio, armazenamento, rede, serial, ADC e GPIO;
- `edge-model`: ponto, qualidade, unidade, configuração e eventos;
- `edge-transport`: envelope MQTT, identidade, fila e diagnóstico.

Projetos filhos adicionam adaptadores e perfis. Eles não devem copiar drivers ou
alterar schemas silenciosamente. Dependências usam tags imutáveis e changelog.

## 8. Estados operacionais

| Estado | Aquisição | Buffer | Publicação | Configuração |
|---|---|---|---|---|
| `BOOT` | não | recuperação | não | não |
| `SAFE` | diagnóstico | sim | saúde | somente serviço local |
| `RUN_LOCAL` | sim | sim | não | local autenticada |
| `RUN_ONLINE` | sim | sim | sim | conforme política |
| `DEGRADED` | parcial | sim | saúde + válidos | bloqueada se recursos insuficientes |
| `UPDATE` | congelada/limitada | preservado | não | somente pacote assinado |
| `RECOVERY` | não | preservado | não | imagem/configuração anterior |

## 9. Restrições

- Wi-Fi não é caminho obrigatório.
- CAN não será ativado no MVP.
- Não existem saídas de controle no P0.
- O gateway não substitui CLP, relé de segurança ou proteção de processo.
- Isolação e EMC permanecem metas até ensaios do protótipo.

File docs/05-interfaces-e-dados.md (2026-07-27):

# Interfaces e dados EDGE-18

## 1. Conectores da Rev. A

| ID | Interface | Sinais | Domínio |
|---|---|---|---|
| J1 | alimentação | VIN+, VIN−, CHASSIS | 9–36 Vcc |
| J2 | SWD ARM 10 pinos | SWDIO, SWCLK, SWO, NRST, 3V3, GND | produção |
| J3 | microSD | SDMMC 4 bits, detect, 3V3, GND, shield | armazenamento |
| J4 | USB-C serviço | USB 2.0 FS device, CC1/CC2, VBUS, GND, shield | lógica/serviço |
| J5 | Ethernet | RJ45 blindado com magnetics e LEDs | magneticamente isolado |
| J6 | serviço/expansão | 3V3, GND, I2C, UART, GPIO, NRST | lógica |
| J10 | analógica 1 | AI1_FIELD, AGND | campo comum |
| J11 | analógica 2 | AI2_FIELD, AGND | campo comum |
| J12 | analógica 3 | AI3_FIELD, AGND | campo comum |
| J13 | analógica 4 | AI4_FIELD, AGND | campo comum |
| J14 | digitais 1–4 | DI1_FIELD…DI4_FIELD, DI_FIELD_GND | campo isolado |
| J15 | RS-485 A | A+, B−, RS485A_GND | isolado |
| J16 | RS-485 B | A+, B−, RS485B_GND | isolado |
| J17 | CAN-FD | CAN-H, CAN-L, CAN_GND | isolado, reservado |

Essa numeração corresponde ao esquemático Rev. A. Ela ainda não autoriza a
montagem de chicote: pinout, chaveamento e polaridade devem ser confirmados
contra a revisão que vier a ser liberada para fabricação.

## 2. Configuração

O arquivo de configuração possui:

- `schema_version`;
- identidade lógica e site;
- rede e tempo;
- dispositivos;
- pontos;
- política de armazenamento;
- broker e tópicos;
- diagnóstico.

A fonte normativa é `schemas/gateway-config.schema.json`. Campos desconhecidos
são rejeitados no MVP para impedir interpretações silenciosas.

## 3. Modelo de ponto

| Campo | Tipo | Regra |
|---|---|---|
| `point_id` | string | único, 1–48 caracteres seguros para tópico |
| `sequence` | uint64 | monotônico por dispositivo |
| `timestamp_ms` | int64 | UTC Unix em ms; zero se não confiável |
| `monotonic_ms` | uint64 | sempre presente desde o boot |
| `value_type` | enum | bool, i64, u64, f64 ou string curta |
| `value` | variante | não substitui qualidade |
| `unit` | string | UCUM quando aplicável |
| `quality` | uint32 | máscara documentada |
| `source` | string | dispositivo/canal |
| `config_revision` | uint32 | revisão que produziu o valor |

## 4. Tópicos MQTT v1

Prefixo:

```text
edge/v1/{tenant}/{site}/{device}/
```

| Sufixo | Retain | QoS | Conteúdo |
|---|---:|---:|---|
| `inventory` | sim | 1 | hardware, versões e capacidades |
| `state` | sim | 1 | online, boot ID, saúde resumida |
| `telemetry` | não | 1 | lote de pontos |
| `events` | não | 1 | mudança de estado, falha e auditoria |
| `diagnostics` | não | 0/1 | métricas sem segredos |

Comandos remotos não fazem parte do MQTT v1. Configuração remota futura terá
canal separado, assinatura e política explícita.

## 5. Envelope de telemetria

Exemplo informativo:

```json
{
  "schema": "edge.telemetry/1",
  "device_id": "edge18-000001",
  "boot_id": "9f462527",
  "message_id": "0000000000018a42",
  "sent_at_ms": 1785100000123,
  "points": [
    {
      "point_id": "tank.level",
      "sequence": 18720,
      "timestamp_ms": 1785099999980,
      "monotonic_ms": 623991,
      "value_type": "f64",
      "value": 73.2,
      "unit": "%",
      "quality": 0,
      "source": "ai1",
      "config_revision": 4
    }
  ]
}
```

## 6. Idempotência

`device_id + boot_id + message_id` identifica uma publicação. `point_id +
sequence` identifica uma amostra. O backend aceita repetição por QoS 1 e não
depende de entrega exatamente uma vez.

## 7. REST local

Recursos previstos:

- `GET /v1/health`;
- `GET /v1/inventory`;
- `GET /v1/config`;
- `PUT /v1/config/staging`;
- `POST /v1/config/validate`;
- `POST /v1/config/commit`;
- `POST /v1/config/rollback`;
- `GET /v1/diagnostics/export`.

REST exige autenticação, limite de tamanho, timeout e log de auditoria. A API não
expõe chave privada nem endpoint de comando físico.

## 8. Modbus

Um ponto Modbus define porta, escravo, função, endereço, quantidade, tipo,
endian, escala, unidade, período, timeout, tentativas e idade máxima. Endereços
internos são base zero. A UI pode exibir notação 4xxxx, mas deve converter de
forma explícita.

## 9. Compatibilidade

- breaking changes incrementam a versão do schema/tópico;
- consumidores devem ignorar qualidade desconhecida somente quando o bit for
  declarado extensível;
- firmware não promove configuração de versão superior;
- migração nunca altera calibração sem registro separado.

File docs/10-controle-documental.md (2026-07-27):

# Controle documental

## Identificação

- Projeto: 18 — Gateway Industrial Modbus/CAN Universal
- Baseline inicial: 2026-07-26
- Baseline Rev. A congelada: 2026-07-27
- Estado: projeto detalhado para revisão digital; não liberado para fabricação

## Documentos controlados

- requisitos e arquitetura;
- esquemáticos, PCB, BOM e mecânica;
- código, dependências, schemas e protocolos;
- planos, dados e relatórios de teste;
- manuais de fabricação, instalação, operação e manutenção;
- decisões, riscos, status, roadmap, backlog e changelog.

## Regra de revisão

Cada alteração material deve registrar autor, data, motivo, arquivos afetados,
impacto em requisitos/testes e necessidade de migração. Entregáveis derivados
devem informar a fonte e revisão usada.

## Estados permitidos

`ideia` → `concepção documentada` → `projeto detalhado` → `protótipo` →
`validado em bancada` → `piloto de campo` → `produto`.

Nenhuma promoção de estado ocorre apenas porque arquivos foram criados.

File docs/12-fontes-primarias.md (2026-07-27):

# Fontes primárias e seleção de componentes

**Consulta:** 2026-07-26. Use sempre a revisão mais nova antes de congelar BOM ou
footprint.

## Controlador

- [STM32H563ZI — página oficial ST](https://www.st.com/en/microcontrollers-microprocessors/stm32h563zi.html)
- [STM32H562/H563 — datasheet oficial](https://www.st.com/resource/en/datasheet/stm32h563zi.pdf)

Motivo: Cortex-M33 com TrustZone, 2 MB de flash, 640 KB de RAM, Ethernet MAC,
dois FDCAN, SDMMC, USB e periféricos suficientes no LQFP-144. A seleção não
dispensa pinout completo, errata e disponibilidade.

## Ethernet e Wi-Fi

- [LAN8742A — datasheet Microchip](https://ww1.microchip.com/downloads/en/DeviceDoc/8742a.pdf)
- [ESP32-C3-WROOM-02 — datasheet Espressif](https://www.espressif.com/sites/default/files/documentation/esp32-c3-wroom-02_datasheet_en.pdf)

O LAN8742A fornece o PHY RMII. O ESP32-C3 é coprocessador opcional; o STM32
continua autoridade e suporta funcionamento sem rádio.

## Aquisição analógica

- [ADS8684 — produto e documentação TI](https://www.ti.com/product/ADS8684)
- [ADS8684 — datasheet](https://www.ti.com/lit/ds/symlink/ads8684.pdf)

O ADS8684 reúne quatro canais, 16 bits, SPI, faixas programáveis unipolares e
bipolares, referência interna e proteção de entrada especificada pelo fabricante.
Proteção interna não substitui TVS, filtro, resistor e análise de surto da placa.

## Interfaces isoladas

- [ISO1212 — entradas digitais TI](https://www.ti.com/product/ISO1212)
- [ISOW1412 — RS-485 com potência isolada TI](https://www.ti.com/product/ISOW1412)
- [ISOW1412 — datasheet](https://www.ti.com/lit/ds/symlink/isow1412.pdf)
- [ISOW1044 — CAN-FD com potência isolada TI](https://www.ti.com/product/ISOW1044)

O ISO1212 atende entradas industriais de 24–60 V conforme a configuração de
resistores. ISOW1412 e ISOW1044 integram a potência das três interfaces de
barramento isoladas. Uma solução com transceptor e DC/DC separados permanece
alternativa se ruído, custo ou estoque exigirem.

## Alimentação

- [LM76002 — buck 3,5–60 V/2,5 A TI](https://www.ti.com/product/LM76002)

A faixa do CI oferece margem sobre 36 V nominal. O envelope final depende de
todos os componentes da entrada, do layout e dos ensaios.

## Documentos ainda obrigatórios

- errata do STM32H563;
- reference manual e hardware development guide do STM32H5;
- layout RMII e recomendações do PHY/magnetics;
- guias de layout dos isoladores e do ADC;
- relatórios de lifecycle/PCN e estoque no congelamento da BOM;
- normas aplicáveis na edição escolhida para comercialização.

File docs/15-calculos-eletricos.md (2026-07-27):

# Cálculos elétricos — EDGE-18 Rev. A

## 1. Premissas

| Parâmetro | Valor de projeto |
|---|---:|
| entrada nominal | 9–36 Vcc |
| saída principal | 5,0 V / 2,0 A contínuos |
| limite do LM76002 | 2,5 A |
| frequência usada no cálculo | 500 kHz |
| saída lógica | 3,3 V / até 3 A no TPS62132 |
| temperatura de cálculo | −20 a +70 °C ambiente |
| PCB | quatro camadas, 1 oz, 1,6 mm |

Valores de bancada substituem as premissas após o protótipo.

## 2. Buck de 5 V

O divisor `R1 = 40,2 kΩ` e `R2 = 10,0 kΩ`, com referência nominal de 1,0 V,
produz:

```text
VOUT = 1,0 × (1 + 40,2 / 10,0) = 5,02 V
```

Para `L2 = 10 µH`, 500 kHz e pior caso de ripple em 36 V:

```text
ΔIL = VOUT × (VIN − VOUT) / (VIN × L × f)
ΔIL = 5 × 31 / (36 × 10 µH × 500 kHz) = 0,861 A
```

Em 9 V, `ΔIL = 0,444 A`. Com 2,0 A de carga, o pico calculado em 36 V é
2,431 A, abaixo do limite nominal de 2,5 A, porém com margem pequena. A
indutância XAL1010-103 suporta a corrente, mas a temperatura do CI e do diodo
de entrada deve ser medida.

Com 20 µF nominais de saída (`C4 + C5`), antes de derating:

```text
ΔVcapacitivo ≈ ΔIL / (8 × f × C) = 10,8 mV
```

O ripple real soma ESR, perda de capacitância DC e layout.

## 3. Entrada e proteção

- `F1`: PTC 2 A;
- `D1`: SMBJ36A;
- `D2`: SS56 em série para inversão;
- `L1`: 10 µH;
- `C1`: 100 µF/63 V e `C2`: 1 µF/100 V.

O clamp máximo publicado da SMBJ36A fica próximo do limite absoluto de 60 V do
LM76002. Portanto a Rev. A exige ensaio de surto com a impedância real da fonte;
ela não recebe qualificação de transiente apenas por cálculo. Em 2 A, a perda
do SS56 pode se aproximar de 1 W e deve ser verificada termicamente.

## 4. Buck de 3,3 V

O TPS62132 é variante fixa de 3,3 V. `L3 = 2,2 µH`, `C7 + C8 = 44 µF`
nominais e desacoplamentos locais atendem a topologia de referência. O rail é
separado por ferrites para `3V3_A` e `3V3_ETH`. A corrente de 3 A é capacidade
do conversor, não orçamento autorizado a cada carga.

## 5. Entradas analógicas

Cada canal tem `1 kΩ + 10 nF`, logo:

```text
fc = 1 / (2πRC) = 15,9 kHz
```

Em modo 4–20 mA, o jumper fecha o shunt de `249 Ω`, 0,1%, 25 ppm/°C:

| Corrente | Tensão no ADC | Potência no shunt |
|---:|---:|---:|
| 4 mA | 0,996 V | 3,98 mW |
| 20 mA | 4,980 V | 99,6 mW |
| 24 mA diagnóstico | 5,976 V | 143,4 mW |

O resistor 0805 deve ter potência nominal compatível com a temperatura. O
SMAJ12A limita eventos de campo, mas capacitância e energia de surto precisam
ser medidas no protótipo.

## 6. Entradas digitais

Os dois ISO1212 seguem a configuração Type 3:

- `RSENSE = 562 Ω`, corrente nominal de entrada de aproximadamente 2,25 mA;
- `RTHR = 1,00 kΩ`, alvo de limiar em 11 V;
- `CIN = 10 nF` por canal;
- SMAJ33A no lado de campo.

A potência de campo é dominada pelo caminho interno do receptor; a validação
deve medir limiares crescente/decrescente em 9, 18, 24, 30 e 36 V, temperatura
e fuga do TVS.

## 7. Barramentos isolados

Cada RS-485 usa ISOW1412 com alimentação isolada integrada, TVS
SM712 e terminação de 120 Ω selecionável. O CAN usa ISOW1044, PESD2CAN e
terminação de 120 Ω selecionável. Os três transceptores possuem retorno de
campo independente e rasgo mecânico sob a barreira.

Uma terminação de 120 Ω em 5 V diferenciais dissipa até aproximadamente
208 mW; os resistores são 1206. As terminações permanecem abertas por padrão.

## 8. Classes de roteamento

| Classe | Trilhas | Clearance | Via / furo |
|---|---:|---:|---:|
| padrão | 0,30 mm | 0,18 mm | 0,80 / 0,40 mm |
| alimentação | 0,80 mm | 0,18 mm | 1,20 / 0,60 mm |
| VIN | 1,20 mm | 0,18 mm | 1,60 / 0,80 mm |
| analógico | 0,35 mm | 0,18 mm | 0,90 / 0,45 mm |
| campo | 0,50 mm | 0,18 mm | 1,00 / 0,50 mm |
| alta velocidade | 0,25 mm | 0,18 mm | 0,70 / 0,35 mm |

O mínimo global de trilha é 0,25 mm. O clearance reduzido junto a encapsulamentos
de passo fino não substitui os afastamentos de isolamento, que são obtidos pela
separação física dos domínios e rasgos.

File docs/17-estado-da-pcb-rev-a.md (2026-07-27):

# Estado congelado da PCB Rev. A

## 1. Decisão de controle

Em 27 de julho de 2026, o responsável pelo projeto determinou que a PCB fosse
mantida no estado corrente e que não fossem feitas novas tentativas de
roteamento. O arquivo
`hardware/edge18-main/edge18-main-rev-a.kicad_pcb` é, portanto, uma baseline de
revisão digital, não uma placa liberada para fabricação.

Nenhuma exceção de DRC foi aprovada. Nenhuma ocorrência abaixo deve ser
interpretada como aceita para produção.

## 2. Evidência automatizada

| Verificação | Resultado congelado |
|---|---:|
| ERC do esquemático | 0 erros, 0 avisos |
| violações DRC da PCB | 43 |
| conexões abertas | 24 |
| erros de footprint | 0 |
| curtos entre redes reportados | 0 |
| segmentos de trilha | 2.654 |
| vias | 289 |
| footprints | 185 |
| pads | 869 |
| zonas de cobre | 3 |

Os relatórios integrais são:

- [`reports/edge18-main-rev-a-erc.rpt`](reports/edge18-main-rev-a-erc.rpt);
- [`reports/edge18-main-rev-a-drc.rpt`](reports/edge18-main-rev-a-drc.rpt).

O manifesto
[`reports/edge18-rev-a.sha256`](reports/edge18-rev-a.sha256) permite verificar
a integridade dos CAD, código, imagens, PDF, relatórios e modelos mecânicos
entregues.

## 3. Distribuição das ocorrências de DRC

| Categoria | Quantidade | Interpretação |
|---|---:|---|
| `hole_to_hole` | 4 | furos/vias próximos demais |
| `copper_edge_clearance` | 7 | cobre próximo dos rasgos de isolamento |
| `clearance` | 1 | afastamento cobre–cobre abaixo de 0,18 mm |
| `track_dangling` | 17 | extremidades de trilhas sem continuidade |
| `via_dangling` | 14 | vias conectadas em somente uma camada |
| `unconnected_items` | 24 | ligações lógicas ainda abertas |

O total de 43 corresponde às cinco primeiras categorias. As 24 conexões abertas
são informadas separadamente pelo KiCad.

## 4. Larguras efetivamente presentes

| Largura | Segmentos | Uso |
|---:|---:|---|
| 0,25 mm | 1.084 | escapes e sinais de alta densidade |
| 0,30 mm | 429 | sinais gerais |
| 0,35 mm | 158 | sinais analógicos |
| 0,40 mm | 15 | transições herdadas do roteador |
| 0,50 mm | 275 | interfaces de campo |
| 0,601–0,740 mm | 16 | transições geométricas do roteador |
| 0,80 mm | 638 | alimentação |
| 1,20 mm | 39 | entrada VIN |

Não há segmento abaixo de 0,25 mm. Existe uma microvia de 0,30/0,10 mm no
escape do PHY Ethernet; as demais vias têm diâmetro mínimo de 0,70 mm.

## 5. Estado do 3D

O STEP da PCB congelada está em
`mechanical/step/edge18-main-rev-a.step`. A exportação inclui o corpo da placa,
furos e a maior parte dos componentes disponíveis na biblioteca KiCad local.
Dez referências de modelos 3D indicadas pelos footprints não existem nessa
versão da biblioteca e aparecem omitidas no STEP/render:

- `L1`, `L2`, `L3`;
- `F1`;
- `J3`, `J5`;
- `U1`, `U2`, `U4`, `U7`.

Essa ausência é uma pendência visual/mecânica e não altera a conectividade
elétrica. Antes de validar colisões e recortes do gabinete, os modelos corretos
dos fabricantes devem substituir as aproximações/ausências.

## 6. Condições para futura liberação fabril

Uma revisão posterior só pode receber o estado `liberada para fabricação`
depois de:

1. fechar as 24 conexões;
2. eliminar as 43 ocorrências de DRC sem criar exceções silenciosas;
3. executar inspeção cruzada de esquemático, layout, polaridade e pinout;
4. completar e alinhar os dez modelos 3D ausentes;
5. realizar DFM com o fabricante e revisar stack-up/impedâncias;
6. montar protótipos e concluir bring-up, elétrica, térmica, EMC e isolamento;
7. registrar a evidência e aprovar formalmente o gate G2.

Até lá, Gerbers e arquivos de montagem não devem ser usados para compra ou
produção.

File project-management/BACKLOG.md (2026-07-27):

# Backlog

## Concluído

- [x] B-18-001 — fechar objetivo e MVP somente leitura;
- [x] B-18-002 — transformar o MVP em requisitos;
- [x] B-18-003 — selecionar arquitetura e componentes críticos;
- [x] B-18-004 — criar contratos JSON;
- [x] B-18-005 — implementar núcleo C testável;
- [x] B-18-006 — configurar build, testes e CI.
- [x] B-18-010 — implementar tipos/conversões Modbus;
- [x] B-18-011 — implementar planejador de leituras;
- [x] B-18-012 — definir journal persistente e testes de interrupção;
- [x] B-18-013 — parser/validador C da configuração;
- [x] B-18-020 — fechar pinout STM32;
- [x] B-18-021 — calcular fonte/proteção;
- [x] B-18-022 — criar esquemático KiCad e obter ERC limpo;
- [x] B-18-024 — criar PCB de quatro camadas;
- [x] B-18-027 — gerar BOM Rev. A;
- [x] B-18-025 — criar FreeCAD P0 e verificar envelopes dimensionais;

## G0

- [ ] B-18-014 — revisar schemas com os Projetos 1 e 11;
- [ ] B-18-015 — escolher licença.

## G1/G2

- [ ] B-18-023 — concluir DFM de footprints e dez modelos 3D ausentes;
- [ ] B-18-026 — fechar 43 DRC/24 conexões e fazer revisão independente;
- [ ] B-18-028 — emitir pacote fabril somente após DRC limpo;
- [ ] B-18-029 — montar e ensaiar protótipos.

## Regras

- concluído referencia commit ou relatório;
- trabalho fora do MVP não interrompe os gates;
- defeitos e riscos permanecem visíveis;
- nenhuma data é inventada sem responsável e capacidade.

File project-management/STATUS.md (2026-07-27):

# Status do projeto

**Projeto:** 18 — EDGE-18 Gateway Industrial
**Data:** 2026-07-27
**Fase:** G1 digital concluído; G2 bloqueado no layout
**Saúde:** amarela — entrega digital ampla, PCB ainda não fabricável

## Concluído

- [x] ordem de desenvolvimento aprovada;
- [x] Projeto 18 definido como plataforma-pai;
- [x] requisitos P0 detalhados;
- [x] STM32H563 e componentes principais selecionados;
- [x] seis ADRs;
- [x] schemas de configuração/telemetria e exemplos;
- [x] núcleo C17 de pontos, qualidade, fila e CRC Modbus;
- [x] build, testes e CI;
- [x] modelo dimensional FreeCAD/STEP P0 validado;
- [x] matriz de reutilização para projetos filhos.
- [x] esquemático A0 Rev. A com ERC limpo;
- [x] BOM de 181 posições e pinout STM32 de 144 pinos;
- [x] PCB quatro camadas posicionada e parcialmente roteada;
- [x] código C17 dos serviços centrais e testes host;
- [x] quinze vistas técnicas e PDF consolidado;
- [x] STEP da PCB e conjunto FreeCAD Rev. A;
- [x] baseline da PCB congelada por decisão do responsável.

## Evidência atual

| Indicador | Resultado |
|---|---:|
| testes host | suíte C17, aprovada |
| esquemático | ERC: 0 erros, 0 avisos |
| PCB congelada | 43 DRC; 24 conexões abertas; 0 erro de footprint |
| trilha mínima presente | 0,25 mm |
| BOM | 181 posições; 4 DNP |
| pinout | 144 pinos |
| schemas/exemplos | aprovados |
| modelo FreeCAD/STEP | Rev. A, aprovado pelo validador dimensional |
| imagens técnicas | 15 |
| PDF consolidado | 1 |
| protótipos | 0 |
| ensaios físicos | 0 |

## Congelado por decisão

- [ ] 24 conexões abertas;
- [ ] 43 ocorrências de DRC;
- [ ] dez modelos 3D ausentes na biblioteca local.

## Próximo gate

G1 pode ser revisado documentalmente. G2 permanece bloqueado até uma futura
autorização para retomar o layout, fechar conectividade e obter DRC limpo.

## Bloqueios

- PCB não liberada para fabricação;
- cliente/equipamento Modbus piloto ainda não escolhido;
- licença do repositório ainda não definida;
- normas/ensaios comerciais ainda não congelados.

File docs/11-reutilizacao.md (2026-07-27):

# Reutilização do EDGE-18

## 1. Responsabilidade do projeto-pai

O Projeto 18 mantém os contratos genéricos de aquisição e telemetria. Um projeto
filho pode substituir a PCB ou adicionar sensores, mas não deve criar uma
segunda definição incompatível de ponto, qualidade, fila ou envelope MQTT.

## 2. Ativos compartilhados

| Ativo | Forma de distribuição | Compatibilidade |
|---|---|---|
| `edge-model` | biblioteca C versionada | SemVer; ABI não é promessa entre majors |
| schemas JSON | release e URL imutável | versão no próprio documento |
| envelope MQTT | especificação + testes de contrato | prefixo `edge/v1` |
| HAL | interfaces C; porta por MCU | API versionada |
| ferramentas de configuração | pacote/CLI | compatível com schemas declarados |
| perfil de fabricação/teste | documentação e fixtures | por revisão de hardware |

## 3. Matriz de consumidores

| Projeto | Reutiliza | Especialização |
|---|---|---|
| 1 — Telemetria Broadcast | modelo, MQTT, buffer, Modbus, Ethernet | SNMP, transmissores e backend de estação |
| 2 — Gerador/combustível | HAL, I/O, eventos, buffer | máquina ATS e intertravamentos externos |
| 3 — Sensor RF IoT | modelo, MQTT, identidade, armazenamento | aquisição e calibração RF |
| 11 — NOC SaaS | tópicos, inventário e diagnóstico | multi-tenancy e operação comercial |
| 12 — Tower Companies | RTU, perfis e segurança | inventário corporativo e SLA |
| 13 — Qualidade de energia | transporte e armazenamento | ADC simultâneo, DSP e metrologia |
| 15 — Banco de baterias | RS-485, pontos e tendências | nós de impedância |
| 16 — Kit solar | analógicas, Modbus e buffer | SOC e prioridade de cargas |
| 17 — Frota | envelope e operação offline | OBD/GNSS/4G e privacidade |
| 19 — Torres | telemetria e tempo | IMU, espectro e baseline estrutural |

## 4. Regras contra bifurcação

1. Alteração comum nasce neste repositório.
2. O projeto filho abre requisito ou issue com caso de uso.
3. Mudança recebe teste de contrato.
4. Uma release imutável é publicada.
5. O filho atualiza a dependência e registra a versão.
6. Fork permanente só ocorre por ADR explícito.

## 5. Limites do reaproveitamento

- proteções automotivas não são herdadas de uma entrada industrial;
- isolação de RS-485 não qualifica interface de alta tensão;
- calibração RF/metrológica permanece no projeto consumidor;
- um schema comum não torna dois equipamentos intercambiáveis;
- certificação e ensaio pertencem a cada produto físico.

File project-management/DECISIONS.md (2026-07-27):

# Registro de decisões

| ADR | Decisão | Estado |
|---|---|---|
| [0001](../docs/decisions/0001-mcu-stm32h563.md) | STM32H563ZIT6 como controlador | aceito P0 |
| [0002](../docs/decisions/0002-monitoramento-sem-saidas.md) | MVP somente de monitoramento | aceito |
| [0003](../docs/decisions/0003-isolacao-de-campo.md) | isolamento das interfaces de campo | aceito P0 |
| [0004](../docs/decisions/0004-wifi-coprocessador.md) | Wi-Fi como coprocessador opcional | aceito P0 |
| [0005](../docs/decisions/0005-contratos-versionados.md) | contratos mantidos no projeto-pai | aceito |
| [0006](../docs/decisions/0006-dimensoes-p0.md) | placa sem miniaturização agressiva | aceito P0 |

Novas decisões estruturais exigem ADR com alternativas e consequências.

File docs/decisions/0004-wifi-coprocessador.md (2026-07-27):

# ADR 0004 — Wi-Fi como coprocessador opcional

- Estado: aceito para P0
- Data: 2026-07-26

## Decisão

Ethernet no STM32 é a rede principal. ESP32-C3-WROOM-02 fornece Wi-Fi opcional e
pode ser removido/desenergizado. Ele não controla I/O nem conserva a identidade
raiz.

## Consequências

É necessário protocolo interno e atualização coordenada de dois firmwares, mas
falha do rádio não derruba aquisição ou Ethernet.

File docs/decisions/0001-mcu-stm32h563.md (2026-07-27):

# ADR 0001 — STM32H563ZIT6 como controlador principal

- Estado: aceito para P0
- Data: 2026-07-26

## Contexto

A plataforma-pai precisa de Ethernet, memória para TLS/configuração, CAN futuro,
armazenamento, temporização e recursos modernos de segurança sem BGA.

## Decisão

Usar STM32H563ZIT6 em LQFP-144. O firmware de domínio permanecerá desacoplado da
HAL para permitir testes no host e portas futuras.

## Alternativas

- ESP32 como MCU único: menor custo e Wi-Fi integrado, porém mistura rádio e
  autoridade de campo.
- STM32H743: mais processamento, mas Cortex-M7 sem a mesma arquitetura de
  segurança do H5.
- STM32G4 + coprocessador: bom tempo real, mas memória/rede exigiriam divisão
  mais complexa.

## Consequências

Há mais complexidade de boot seguro e um MCU de maior custo. Em troca, Ethernet,
FDCAN, memória e TrustZone ficam na autoridade principal.

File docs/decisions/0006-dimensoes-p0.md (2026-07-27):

# ADR 0006 — placa P0 sem miniaturização agressiva

- Estado: aceito para P0
- Data: 2026-07-26

## Decisão

Usar PCB de 180 × 120 mm, quatro camadas, conectores plugáveis de 5,08 mm e
gabinete aproximado de 210 × 150 × 65 mm com suporte DIN.

## Consequências

O produto é maior, porém facilita isolação, EMC, pontos de teste, retrabalho e
revisão. Redução só será considerada depois da validação.

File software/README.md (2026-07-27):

# Software

## Finalidade

Aplicações, backend, frontend e ferramentas de engenharia.

## Entregáveis esperados

- código-fonte
- schemas/APIs
- testes
- implantação e recuperação

## Estado

Pasta reservada; não há artefato implementado na baseline de 2026-07-26. Quando
arquivos forem adicionados, este documento deverá indicar ferramenta, versão,
como regenerar/validar e qual requisito é atendido.

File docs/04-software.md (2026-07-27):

# Software e firmware EDGE-18

## 1. Plataforma

- linguagem do núcleo: C17;
- RTOS-alvo: FreeRTOS;
- rede: LwIP;
- TLS: mbedTLS;
- MQTT: cliente com QoS 1 e sessão controlada;
- armazenamento: camada própria sobre FatFs/driver de bloco;
- build: CMake para núcleo host; toolchain Arm para alvo;
- schemas: JSON Schema Draft 2020-12;
- testes: executáveis no host sem placa e testes HIL no protótipo.

O código de domínio não incluirá headers da HAL STM32. A porta alvo implementa
interfaces pequenas de tempo, armazenamento, serial, rede e entropia.

## 2. Módulos

| Módulo | Responsabilidade |
|---|---|
| `edge_point` | valor, tipo, unidade, timestamp e qualidade |
| `edge_queue` | fila limitada em RAM, política de pressão e métricas |
| `edge_config` | validação semântica de dispositivos, referências e pontos |
| `edge_scheduler` | agenda leituras com fase e backoff sem bloquear portas |
| `modbus_master` | framing, CRC, respostas, exceções e endian |
| `analog_input` | aquisição, filtros, calibração e diagnóstico |
| `digital_input` | debounce, bordas, frequência e totalizadores |
| `persistent_log` | journal com CRC/commit, recuperação e compactação |
| `mqtt_transport` | envelope limitado, QoS, reconexão e idempotência |
| `health` | watchdog, reset cause, recursos e self-test |
| `secure_update` | alvo, hash, assinatura, contador e rollback |

O núcleo host implementado corresponde a `edge_point`, `edge_queue`,
`edge_config`, `edge_scheduler`, framing/decodificação de `modbus_master`,
formato de `persistent_log`, envelope de telemetria, máquina de estados e
validação de manifesto. Drivers STM32, RTOS, rede e sistema de arquivos ficam
na porta de hardware e só podem ser considerados concluídos após integração
HIL.

## 3. Tarefas previstas

| Tarefa | Prioridade | Período/evento | Watchdog |
|---|---:|---|---|
| supervisor | máxima | 100 ms | alimenta IWDG após consenso |
| entradas digitais | alta | interrupção + 1 ms | contador de progresso |
| aquisição analógica | alta | 10–1.000 ms | deadline |
| Modbus A/B | alta | por agenda | deadline por transação |
| persistência | média | fila/evento | backlog máximo |
| publicador MQTT | média | fila/rede | heartbeat |
| rede/tempo | média | eventos | estado |
| REST/configuração | baixa | conexão local | timeout |
| diagnóstico | baixa | 1 s | não crítico |

Somente o supervisor alimenta o watchdog, e apenas quando as tarefas críticas
avançaram dentro da janela.

## 4. Memória

- nenhuma alocação dinâmica no caminho de aquisição após o boot;
- tabelas de até 32 dispositivos e 128 pontos alocadas na promoção de
  configuração;
- buffers de protocolo têm limites compilados;
- mensagens grandes são serializadas por partes;
- certificados e chaves possuem área dedicada;
- métricas incluem high-water mark de pilha, heap e filas.

## 5. Qualidade do ponto

A qualidade é uma máscara de bits. `GOOD` é zero; falhas podem coexistir.

| Bit | Nome | Significado |
|---:|---|---|
| 0 | `COMM_TIMEOUT` | dispositivo não respondeu |
| 1 | `COMM_CRC` | quadro corrompido |
| 2 | `PROTOCOL_EXCEPTION` | exceção do protocolo |
| 3 | `OUT_OF_RANGE` | fora da faixa configurada |
| 4 | `SENSOR_FAULT` | diagnóstico do canal |
| 5 | `STALE` | idade maior que o limite |
| 6 | `TIME_UNSYNCED` | UTC não confiável |
| 7 | `CONVERSION_ERROR` | tipo/escala inválidos |
| 8 | `CONFIG_ERROR` | entidade desabilitada pela configuração |
| 9 | `STORAGE_DEGRADED` | persistência não garantida |

Um valor pode ser transportado para diagnóstico com qualidade ruim, mas
consumidores não devem tratá-lo como medida válida.

## 6. Fila

O núcleo implementa fila limitada em RAM e um codec de journal testável no
host. A porta de persistência no microSD deve preservar:

- cabeçalho, versão, comprimento, sequência e CRC;
- marcador de commit de 32 bits gravado por último;
- recuperação até o último registro completo;
- segmentos fechados imutáveis;
- confirmação MQTT por faixa de sequência;
- descarte do segmento mais antigo somente com métrica e evento.

## 7. Atualização

1. baixar por canal autenticado;
2. validar manifesto, hardware, tamanho e hash;
3. verificar assinatura na zona segura;
4. gravar slot inativo/staging;
5. reiniciar em modo de tentativa;
6. executar self-test e marcar boot saudável;
7. reverter automaticamente se o prazo expirar.

O validador implementado rejeita alvo incompatível, imagem vazia ou grande
demais, contador de segurança não crescente, digest SHA-256 nulo e assinatura
inválida. A criptografia é injetada por callback para que a implementação de
alvo use a zona segura, sem uma falsa verificação no código portátil.

## 8. Critérios de código

- warnings tratados como erro;
- API documentada e tipos de largura explícita;
- nenhuma função bloqueante sem timeout;
- erros não convertidos em booleano genérico;
- logs estruturados, sem segredos;
- testes de limite, wrap-around, fila cheia e entradas inválidas;
- fuzzing futuro para parser de configuração e Modbus;
- CI executa build, testes, schemas e verificações de documentação.

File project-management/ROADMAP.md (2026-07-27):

# Roadmap e gates

| Gate | Conteúdo | Estado | Saída |
|---|---|---|---|
| G0 | requisitos, ADRs, schemas e núcleo host | concluído digitalmente | contratos v0.1 e testes |
| G1 | esquema, cálculos e ERC | concluído digitalmente | KiCad Rev. A, ERC limpo |
| G2 | PCB, mecânica, DRC e fabricação | bloqueado no layout congelado | exige 0 DRC e 0 conexões |
| G3 | alimentação, clock, debug e storage | pendente | relatório de bring-up |
| G4 | RS-485, Modbus, AI e DI | pendente | matriz de I/O |
| G5 | Ethernet, TLS, MQTT e fila persistente | pendente | ensaio integrado |
| G6 | confiabilidade e pré-compliance | pendente | 30 dias + relatório |
| G7 | piloto somente leitura | bloqueado por G0–G6 | aceite de campo |
| G8 | CAN/OPC-UA/expansões | fora do MVP | nova baseline |

## Regra

Um gate só conclui com evidência. Fontes geradas não equivalem a placa montada;
simulação não equivale a ensaio; piloto não equivale a produto certificado.

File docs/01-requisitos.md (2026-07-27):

# Requisitos do Gateway Industrial — P0

**Baseline:** 2026-07-26
**Estado:** aprovado para projeto detalhado; desempenho ainda não ensaiado
**Produto:** `EDGE-18`

## 1. Objetivo

O EDGE-18 é uma plataforma de aquisição industrial somente de monitoramento. Ele
converte Modbus RTU, sinais analógicos e entradas digitais em pontos com unidade,
timestamp e qualidade; conserva dados durante a perda de rede e os publica por
MQTT/TLS. Ethernet é o enlace principal. Wi-Fi é opcional. CAN-FD estará no
hardware P0 para reutilização futura, mas não faz parte do aceite do MVP.

## 2. Envelope do MVP

| Item | Requisito P0 |
|---|---|
| Alimentação | 9–36 Vcc nominal, 15 W máximos previstos |
| Placa | 180 × 120 mm, quatro camadas, sem miniaturização agressiva |
| Temperatura de uso do protótipo | 0–50 °C, ambiente interno, sem condensação |
| MCU | STM32H563ZIT6, Cortex-M33/TrustZone |
| Rede | Ethernet 10/100; Wi-Fi 2,4 GHz opcional |
| Campo serial | 2 × RS-485 isoladas, Modbus RTU mestre |
| Analógicas | 4 × 0–10 V ou 4–20 mA, referência de campo comum |
| Digitais | 4 × 24 V isoladas, contato/pulso |
| CAN | 1 × CAN-FD isolado, hardware reservado, firmware pós-MVP |
| Configuração | JSON Schema v1, interface local autenticada |
| Telemetria | MQTT 3.1.1 ou 5.0 sobre TLS, QoS 1 |
| Armazenamento | microSD industrial; fila limitada e auditável |
| Controle físico | nenhum no MVP |

## 3. Requisitos funcionais

### 3.1 Inicialização, identidade e tempo

| ID | Requisito | Aceite |
|---|---|---|
| SYS-001 | Inicializar em estado somente leitura, sem acionar carga externa | inspeção e teste de boot/reset |
| SYS-002 | Possuir identificador imutável de hardware e identificador lógico configurável | leitura por USB/REST e persistência |
| SYS-003 | Registrar versão de hardware, bootloader, firmware, schema e configuração | mensagem de inventário |
| SYS-004 | Inicializar em até 10 s quando não houver recuperação de armazenamento | medição em 30 ciclos |
| TIME-001 | Sincronizar por NTP quando houver rede | erro ≤ 1 s após sincronismo |
| TIME-002 | Manter RTC durante falta de alimentação por bateria de backup | ensaio de 72 h |
| TIME-003 | Marcar dado sem tempo confiável com qualidade específica | teste unitário e integração |

### 3.2 Modbus RTU

| ID | Requisito | Aceite |
|---|---|---|
| MB-001 | Operar como mestre em duas portas RS-485 independentes | dois escravos simultâneos |
| MB-002 | Suportar 1.200–115.200 bit/s, 8N1, 8E1 e 8O1 | matriz de configuração |
| MB-003 | Suportar funções 01, 02, 03, 04, 05, 06, 15 e 16 | simulador Modbus |
| MB-004 | Agrupar leituras contíguas sem atravessar dispositivo, função ou limite configurado | teste do planejador |
| MB-005 | Limitar o MVP a 32 escravos e 128 pontos no total | validação do schema |
| MB-006 | Possuir timeout, número de tentativas e intervalo configuráveis por dispositivo | injeção de timeout |
| MB-007 | Distinguir timeout, CRC, exceção Modbus, conversão e dado obsoleto | qualidade publicada |
| MB-008 | Terminação de 120 Ω e polarização devem ser selecionáveis por porta | inspeção e medição |

### 3.3 Entradas analógicas

| ID | Requisito | Aceite |
|---|---|---|
| AI-001 | Oferecer quatro canais single-ended com referência de campo comum | inspeção elétrica |
| AI-002 | Selecionar 0–10 V por software no ADC e 4–20 mA por shunt físico de 249 Ω, 0,1% | teste por canal |
| AI-003 | Usar aquisição de 16 bits; não prometer 16 bits efetivos | ruído/ENOB medidos |
| AI-004 | Alcançar erro total alvo ≤ ±0,2% do fundo de escala após calibração, 23 ±5 °C | calibrador de bancada |
| AI-005 | Permitir média, mediana, corte de espúrio e taxa de 1–100 amostras/s | testes do pipeline |
| AI-006 | Detectar corrente abaixo de 3,6 mA e acima de 21 mA como estados configuráveis | fonte de corrente |
| AI-007 | Impedir que um canal fora de faixa invalide os demais | injeção por canal |
| AI-008 | Registrar coeficientes de ganho/offset por canal e revisão de calibração | leitura/exportação |

### 3.4 Entradas digitais e pulsos

| ID | Requisito | Aceite |
|---|---|---|
| DI-001 | Oferecer quatro entradas de 24 V compatíveis com contato seco por fonte externa | bancada 0/24 V |
| DI-002 | Isolar galvanicamente as entradas da lógica | revisão e ensaio de isolação do protótipo |
| DI-003 | Permitir debounce configurável de 0–1.000 ms | teste temporal |
| DI-004 | Contar pulsos até 10 kHz com largura mínima de 50 µs no modo rápido | gerador de pulsos |
| DI-005 | Preservar totalizador em armazenamento não volátil sem escrever a cada pulso | teste de corte |
| DI-006 | Publicar estado, borda, contador e qualidade separadamente | contrato de telemetria |

### 3.5 Ethernet, Wi-Fi e serviços

| ID | Requisito | Aceite |
|---|---|---|
| NET-001 | Usar Ethernet 10/100 como enlace primário | DHCP e IP estático |
| NET-002 | Usar Wi-Fi somente como enlace opcional, sem impedir operação cabeada | módulo ausente/desabilitado |
| NET-003 | Não aceitar conexão de entrada oriunda de rede não confiável por padrão | varredura de portas |
| NET-004 | Expor REST/configuração somente na interface local autorizada | teste de ACL |
| NET-005 | Implementar DNS, DHCP, NTP e resolução de falhas separada por serviço | injeção de falha |
| NET-006 | Manter aquisição e buffer durante ausência total de rede | ensaio offline |

### 3.6 MQTT e dados

| ID | Requisito | Aceite |
|---|---|---|
| MQ-001 | Publicar por MQTT sobre TLS 1.2 ou superior | broker de homologação |
| MQ-002 | Usar autenticação mútua por certificado no modo de produção | teste de certificado válido/revogado |
| MQ-003 | Publicar telemetria com QoS 1 e identificador idempotente | reconexão e duplicata |
| MQ-004 | Separar tópicos de inventário, estado, telemetria, evento e diagnóstico | inspeção do broker |
| MQ-005 | Nunca registrar chave privada, senha ou token nos logs | teste automatizado |
| DATA-001 | Cada ponto deve carregar ID, valor, unidade, qualidade e tempo de aquisição | validação de schema |
| DATA-002 | Valor inválido não pode ser convertido silenciosamente em zero | teste unitário |
| DATA-003 | Escala deve usar expressão linear explícita ou enumeração versionada | validação de configuração |

### 3.7 Buffer e recuperação

| ID | Requisito | Aceite |
|---|---|---|
| BUF-001 | Armazenar pelo menos 1.000.000 de registros no perfil padrão | teste de capacidade |
| BUF-002 | Usar fila persistente limitada, com descarte do mais antigo somente após registrar contador | ensaio de saturação |
| BUF-003 | Recuperar arquivo/fila após corte em qualquer ponto de escrita | 100 ciclos de corte |
| BUF-004 | Reenviar em ordem de aquisição sem impedir dados atuais | teste de reconexão |
| BUF-005 | Aceitar duplicação de transporte e garantir ID idempotente | teste de QoS/reboot |
| BUF-006 | Sinalizar cartão ausente, somente leitura, cheio ou corrompido | matriz de falhas |

### 3.8 Configuração e atualização

| ID | Requisito | Aceite |
|---|---|---|
| CFG-001 | Validar toda configuração contra `gateway-config.schema.json` | suíte de configurações |
| CFG-002 | Aplicar configuração nova de forma transacional | corte durante aplicação |
| CFG-003 | Manter última configuração válida e cópia de fábrica | recuperação |
| CFG-004 | Rejeitar somente a entidade inválida quando isso não comprometer o conjunto | teste parcial |
| UPD-001 | Verificar assinatura e compatibilidade antes de atualizar | imagem alterada/incompatível |
| UPD-002 | Retornar à imagem anterior após falha de boot confirmada | teste de rollback |
| UPD-003 | Preservar identidade, calibração, totalizadores e configuração | regressão |

## 4. Requisitos não funcionais

| ID | Requisito | Meta do protótipo |
|---|---|---|
| PERF-001 | Latência aquisição→publicação com rede disponível | ≤ 2 s no perfil padrão |
| PERF-002 | Ocupação sustentada de CPU | < 70% |
| PERF-003 | Memória dinâmica | proibida após inicialização no núcleo de aquisição |
| REL-001 | Operação contínua | 30 dias sem travamento |
| REL-002 | Watchdog | hardware independente e causa de reset registrada |
| REL-003 | Brownout | nenhuma configuração parcial; reinício seguro |
| SEC-001 | Raiz de confiança | recursos de segurança/TrustZone do STM32H563 |
| SEC-002 | Debug de produção | política documentada de bloqueio e recuperação |
| DOC-001 | Reprodutibilidade | build, teste e artefatos vinculados a commit |
| MAINT-001 | Diagnóstico | exportável sem segredos e sem depender da nuvem |

## 5. Fora do MVP

- OPC-UA;
- aquisição CAN e transmissão CAN ativa;
- saídas digitais ou analógicas;
- lógica de controle capaz de comandar processo;
- modem 4G integrado;
- alimentação por rede elétrica;
- classificação SIL/PL, certificação EMC ou conformidade comercial;
- funcionamento externo, atmosfera explosiva ou temperatura industrial completa.

## 6. Gates

1. **G0 — contratos:** requisitos, ADRs, schemas e núcleo testável no host.
2. **G1 — elétrica:** esquema, cálculos, ERC e revisão independente.
3. **G2 — mecânica/PCB:** layout, DRC, isolação, envelopes e pacote P0.
4. **G3 — bring-up:** fontes, clocks, debug, armazenamento e fail-safe.
5. **G4 — I/O:** RS-485, analógicas e digitais em bancada.
6. **G5 — rede:** Ethernet, TLS, MQTT, buffer e recuperação.
7. **G6 — piloto:** 30 dias somente de monitoramento.

Nenhum gate posterior transforma metas anteriores em resultados medidos sem
evidência anexada.

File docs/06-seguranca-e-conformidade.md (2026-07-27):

# Segurança, conformidade e limites

## 1. Classificação atual

O EDGE-18 P0 é protótipo de bancada e monitoramento. Não é CLP de segurança, não
é fonte isoladora, não possui classificação SIL/PL, não está certificado e não
deve comandar processo.

## 2. Perigos

| Perigo | Controle de projeto | Gate |
|---|---|---|
| inversão/sobretensão de alimentação | fusível, proteção reversa, TVS e buck com margem | esquema + bancada limitada |
| diferença de potencial em RS-485/CAN | isoladores e potência isolada | layout + ensaio |
| surto/ESD nos terminais | proteção por interface e caminho ao chassi | pré-compliance |
| ligação errada 4–20 mA/0–10 V | seleção física, serigrafia e configuração coerente | inspeção + teste |
| curto em borne | limitação/proteção por canal | injeção de falha |
| aquecimento de DC/DC/TVS/shunt | cálculo, termografia e derating | térmica |
| perda de dados | fila limitada, journal e diagnóstico | cortes repetidos |
| configuração maliciosa | autenticação, schema, limites e transação | segurança |
| firmware adulterado | assinatura, boot seguro e rollback | atualização |
| acesso indevido ao campo | nenhum comando no MVP; rede segmentada | revisão de portas |

## 3. Regras obrigatórias de bancada

1. inspeção visual e continuidade sem energia;
2. energizar por fonte isolada com limite de corrente;
3. testar cada rail antes de montar MCU/módulos caros quando possível;
4. usar simuladores e cargas de baixa energia;
5. conectar um único domínio de campo por vez no bring-up;
6. registrar instrumento, serial, revisão e configuração;
7. interromper diante de aquecimento, odor, oscilação, reset ou valor incoerente.

## 4. Rede

- Ethernet de operação fica em segmento controlado;
- configuração local não é exposta à internet;
- Wi-Fi nasce desabilitado;
- MQTT inicia apenas após validação de certificado e relógio;
- chaves privadas não saem pela API nem entram em backup comum;
- serviços e portas abertas são inventariados em cada release.

## 5. Normas a avaliar

As edições aplicáveis serão congeladas antes da comercialização. A lista de
trabalho inclui segurança de equipamentos de controle/medição, EMC industrial,
interfaces digitais IEC 61131-2, Ethernet/rádio, materiais e descarte. Esta lista
não afirma conformidade nem substitui laboratório acreditado.

## 6. Creepage e clearance

Os valores não serão copiados de uma regra genérica. Devem considerar tensão de
trabalho, transientes, categoria de sobretensão, pollution degree, material,
altitude, tipo de isolamento e encapsulamento. O PCB terá keep-outs explícitos e
uma revisão manual além do DRC.

## 7. Limites de uso

- 0–50 °C interno e sem condensação no P0;
- somente SELV/PELV e sinais dentro do envelope documentado;
- analógicas compartilham referência;
- nenhuma ligação direta à rede elétrica;
- nenhum ambiente explosivo;
- nenhum comando de atuador;
- nenhum piloto sem relatório dos gates G1–G5.

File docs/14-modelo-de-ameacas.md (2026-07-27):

# Modelo de ameaças P0

## 1. Ativos

- identidade do dispositivo;
- chave privada e certificados;
- firmware e política mínima de versão;
- configuração e calibração;
- dados operacionais;
- disponibilidade da aquisição;
- acesso aos barramentos de campo.

## 2. Fronteiras

| Fronteira | Confiança inicial |
|---|---|
| Ethernet/Wi-Fi | não confiável |
| broker MQTT | autenticado, mas dados ainda validados |
| USB de serviço | físico privilegiado e auditado |
| cartão microSD | não confiável; dados precisam de integridade |
| RS-485/CAN | campo hostil e ruidoso |
| REST local | autenticado e limitado |
| boot/update | somente conteúdo assinado |

## 3. Ameaças e controles

| Ameaça | Controle P0 |
|---|---|
| firmware modificado | assinatura, versão mínima e rollback controlado |
| dispositivo clonado | identidade individual protegida |
| configuração malformada | schema, limite, staging e commit transacional |
| replay/duplicata MQTT | TLS, sequência e identificador idempotente |
| exaustão por rede | limites de conexão, tamanho, fila e timeout |
| cartão removido/corrompido | journal, CRC, estado degradado e recuperação |
| segredo em log | API de logging sem buffers de chave/token |
| Wi-Fi comprometido | coprocessador sem autoridade nem acesso direto ao campo |
| acesso SWD | política por estágio, registro e bloqueio de produção |
| Modbus hostil | comprimento, função, endereço e taxa limitados |

## 4. Modos de fabricação

- **desenvolvimento:** SWD aberto, chaves de teste, sem credencial de produção;
- **produção:** provisionamento individual, teste, política de debug aplicada;
- **RMA:** procedimento autenticado e destruição/rotação de credenciais;
- **descarte:** limpeza de identidade, configuração e dados.

## 5. Itens pendentes

- definir algoritmo/formato de assinatura;
- definir armazenamento de chave e configuração TrustZone;
- modelar processo de provisionamento offline;
- definir autoridade certificadora e rotação;
- executar análise estática, fuzzing e teste de penetração antes do piloto.

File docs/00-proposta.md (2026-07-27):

### Projeto 18 — Gateway Industrial Modbus/CAN Universal

**Descrição:** "Caixa" que traduz sensores e equipamentos legados (Modbus RTU/TCP, CAN, 4–20 mA, pulso) para dashboard web/MQTT sem exigir programação — SCADA acessível para pequenas indústrias.

**Funcionamento detalhado:** o usuário escolhe uma interface, endereço e
registrador, aplica tipo, escala, unidade e política de publicação e testa a
leitura antes de ativá-la. O runtime agenda aquisições sem bloquear os demais
barramentos, marca qualidade e timestamp, armazena durante indisponibilidade e
executa regras locais a partir de uma configuração versionada.

**MVP verificável:** Modbus RTU mestre, quatro entradas analógicas, quatro
digitais, Ethernet e MQTT, com configuração e diagnóstico web. CAN, Modbus TCP,
OPC-UA e editor visual de regras serão adicionados como módulos independentes.

**Critérios de aceite principais:**
- configuração inválida não pode derrubar aquisições já ativas;
- isolamento, polarização e terminação do RS-485 documentados e ensaiados;
- qualidade diferencia timeout, exceção Modbus, valor fora de faixa e dado
  desatualizado;
- fila offline possui limite e política de descarte explícitos;
- atualização assinada permite rollback sem perder a configuração.

**Dependências e riscos:** pretensão de universalidade, conflitos elétricos de
terra, equipamentos com mapas incorretos, exposição de protocolos industriais à
internet e necessidade de suporte a perfis.

**Especificação técnica:**
- Interfaces: 2× RS-485, 1× CAN, 4× analógicas, 4× digitais/pulso, Ethernet + Wi-Fi
- Configuração 100% via web local: mapear registrador → nome da variável → dashboard, sem código
- Northbound: MQTT, HTTP REST, OPC-UA (fase 2)
- Regras locais (if/then) executando mesmo sem internet; buffer de dados em queda de link

**Etapas de desenvolvimento:**
1. Definir modelo de configuração declarativa (JSON) e editor web amigável
2. Firmware com drivers Modbus mestre, CAN e analógicas sobre RTOS
3. Biblioteca de perfis prontos de equipamentos comuns (inversores, medidores, CLPs)
4. Motor de regras local com editor visual simples
5. Ensaios de EMC industrial e temperatura; caixa DIN
6. Programa de integradores (revenda com margem)

**Documentação a produzir:** manual de configuração com receitas passo a passo, biblioteca de perfis documentada, guia de integração MQTT/REST, catálogo para integradores.

**Mercado:** integradores e pequenas indústrias que não pagam SCADA tradicional; o Projeto 11/12 usa a mesma base.

---

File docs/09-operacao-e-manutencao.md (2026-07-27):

# Operação e manutenção

## Operação prevista

Usuários principais:

- integradores
- pequenas indústrias
- manutenção e automação

O manual operacional deverá cobrir inicialização, indicação de saúde, operação
normal, alarmes, limites, parada segura, atualização e recuperação.

## Manutenção

- inventário de hardware, firmware, configuração e calibração;
- inspeção periódica definida pelo ambiente;
- exportação de diagnóstico sem credenciais;
- troca de módulo com restauração controlada;
- registro de reparo e motivo da substituição;
- política de fim de vida e componentes equivalentes;
- backup e teste de restauração.

## Suporte

Todo chamado deve registrar unidade/site, versão, horário, sintomas, logs,
alterações recentes e ação tomada. Problemas recorrentes tornam-se itens de
backlog ou riscos; correções publicadas entram no changelog.

## Estado atual

Procedimentos operacionais finais dependem do protótipo e dos testes de campo.

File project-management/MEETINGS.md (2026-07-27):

# Atas e diário de engenharia

## Modelo de entrada

### AAAA-MM-DD — título

- Participantes:
- Objetivo:
- Evidências analisadas:
- Decisões:
- Ações, responsáveis e prazo:
- Riscos alterados:
- Links para commits/relatórios:

## 2026-07-26 — criação da baseline

- Participantes: documentação inicial automatizada;
- Objetivo: criar estrutura persistente do Projeto 18;
- Decisões: ver `DECISIONS.md`;
- Ações: revisar escopo, nomear responsáveis e iniciar o primeiro gate;
- Evidências: documentos presentes nesta pasta.

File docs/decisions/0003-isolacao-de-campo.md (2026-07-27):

# ADR 0003 — isolamento das interfaces de campo

- Estado: aceito para P0
- Data: 2026-07-26

## Decisão

As duas RS-485 usam ISOW1412 e o CAN usa ISOW1044, todos com potência isolada
integrada e domínio próprio. As quatro entradas digitais
serão isoladas da lógica. As analógicas compartilharão referência de campo e não
serão isoladas individualmente no P0.

## Consequências

O manual deve declarar a referência comum das analógicas. Aplicações que exigem
isolação canal a canal precisarão de módulo específico.

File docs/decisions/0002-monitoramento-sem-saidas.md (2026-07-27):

# ADR 0002 — MVP somente de monitoramento

- Estado: aceito
- Data: 2026-07-26

## Decisão

O P0 não terá saídas de controle de processo. Funções Modbus 05/06/15/16 existem
na biblioteca para testes/perfis futuros, mas são desabilitadas por política no
MVP e não podem ser disparadas pela nuvem.

## Consequências

Reduz-se o risco do primeiro piloto. Projetos que comandam cargas devem adicionar
hardware, intertravamentos, autorização e testes próprios.

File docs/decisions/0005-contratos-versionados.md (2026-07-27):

# ADR 0005 — contratos versionados no projeto-pai

- Estado: aceito
- Data: 2026-07-26

## Decisão

Modelo de ponto, qualidade, configuração e envelope MQTT são mantidos pelo
Projeto 18 e publicados em releases imutáveis. Projetos filhos consomem versões
declaradas.

## Consequências

Mudanças comuns exigem compatibilidade e testes de contrato. Evita-se copiar e
divergir código entre os vinte repositórios.

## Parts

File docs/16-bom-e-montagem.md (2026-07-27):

# BOM e montagem — EDGE-18 Rev. A

## 1. Fontes normativas

- BOM por posição: `hardware/bom/edge18-main-rev-a-source.csv`;
- BOM agrupada: `release/edge18-rev-a/assembly/edge18-main-rev-a-bom-grouped.csv`;
- posição: `release/edge18-rev-a/assembly/edge18-main-rev-a-position.csv`;
- desenho: `release/edge18-rev-a/documents/edge18-main-rev-a-assembly.pdf`;
- netlist de teste: `release/edge18-rev-a/assembly/edge18-main-rev-a.ipc`.

A BOM possui 181 posições e 113 linhas agrupadas. Nenhuma posição tem
fabricante ou MPN vazio. Substituição exige comparar encapsulamento, tensão,
potência, tolerância, temperatura, lifecycle e parâmetros elétricos.

## 2. DNP padrão

| Referências | Motivo |
|---|---|
| `U8` | ESP32-C3-WROOM-02 opcional |
| `C46` | bulk local do módulo Wi-Fi |
| `R48`, `R49` | pull-ups EN/BOOT do módulo Wi-Fi |

Para montar Wi-Fi, popular os quatro itens juntos, revisar o keep-out da antena
no gabinete e carregar firmware compatível. Não montar apenas parte do conjunto.

## 3. Opções configuráveis

| Referência | Padrão | Fechado quando |
|---|---|---|
| `JP1` | aberto | AI1 em 4–20 mA |
| `JP2` | aberto | AI2 em 4–20 mA |
| `JP3` | aberto | AI3 em 4–20 mA |
| `JP4` | aberto | AI4 em 4–20 mA |
| `JP5` | aberto | RS-485 A é extremidade do barramento |
| `JP6` | aberto | RS-485 B é extremidade do barramento |
| `JP7` | aberto | CAN é extremidade do barramento |

O modo da configuração deve coincidir com o jumper físico. Nunca fechar duas
terminações adicionais em uma rede já terminada.

## 4. Pontos críticos de montagem

1. inspecionar polaridade de `D1`, `D2`, TVS e LEDs;
2. verificar voiding e pasta nos exposed pads de `U1`, `U2`, `U7` e `U8`;
3. confirmar que os rasgos sob `U12`, `U13` e `U14` foram usinados;
4. não preencher os rasgos com cola, coating condutivo ou fixador;
5. manter `R68` como única união intencional `AGND`–`GND`;
6. lavar resíduos entre os domínios isolados;
7. conferir os bornes de 5,08 mm e sua orientação antes do reflow/onda;
8. montar a bateria CR1220 somente após limpeza e inspeção;
9. aplicar etiqueta Rev. A e número de série antes do teste funcional.

## 5. Sequência de inspeção

- AOI de polaridade, ponte e ausência;
- raio X dos exposed pads quando disponível;
- continuidade/curto dos rails com fonte desligada;
- teste elétrico pelo IPC-D-356;
- alimentação inicial em 9 V com limite de 100 mA e módulos isolados sem carga;
- validação de 5 V, 3,3 V, reset, clocks e consumo;
- só então conectar SWD, interfaces de campo e Ethernet.

O primeiro artigo não deve ser conectado simultaneamente a alimentação de campo,
USB aterrada e instrumentos não isolados sem revisar laços de terra.

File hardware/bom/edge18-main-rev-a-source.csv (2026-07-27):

Reference | Value | Footprint | Manufacturer | MPN | Block | DNP | Description
BT1 | CR1220 | Battery:BatteryHolder_Keystone_3000_1x12mm | Keystone | 3000 | STORAGE_SERVICE | no
C1 | 100uF 63V | Capacitor_SMD:C_1210_3225Metric | TDK | X7R industrial equivalent | POWER | no
C10 | 10uF 10V | Capacitor_SMD:C_0603_1608Metric | TDK | C1608 X7R series | POWER | no
C11 | 12pF C0G | Capacitor_SMD:C_0603_1608Metric | TDK | C1608 series | CONTROLLER | no
C12 | 12pF C0G | Capacitor_SMD:C_0603_1608Metric | TDK | C1608 series | CONTROLLER | no
C13 | 12pF C0G | Capacitor_SMD:C_0603_1608Metric | TDK | C1608 series | CONTROLLER | no
C14 | 12pF C0G | Capacitor_SMD:C_0603_1608Metric | TDK | C1608 series | CONTROLLER | no
C15 | 100nF | Capacitor_SMD:C_0603_1608Metric | TDK | C1608 series | CONTROLLER | no
C16 | 100nF | Capacitor_SMD:C_0603_1608Metric | TDK | C1608 series | CONTROLLER | no
C17 | 100nF | Capacitor_SMD:C_0603_1608Metric | TDK | C1608 series | CONTROLLER | no
C18 | 100nF | Capacitor_SMD:C_0603_1608Metric | TDK | C1608 series | CONTROLLER | no
C19 | 100nF | Capacitor_SMD:C_0603_1608Metric | TDK | C1608 series | CONTROLLER | no
C2 | 1uF 100V X7R | Capacitor_SMD:C_1210_3225Metric | TDK | X7R industrial equivalent | POWER | no
C20 | 100nF | Capacitor_SMD:C_0603_1608Metric | TDK | C1608 series | CONTROLLER | no
C21 | 100nF | Capacitor_SMD:C_0603_1608Metric | TDK | C1608 series | CONTROLLER | no
C22 | 100nF | Capacitor_SMD:C_0603_1608Metric | TDK | C1608 series | CONTROLLER | no
C23 | 4.7uF | Capacitor_SMD:C_0603_1608Metric | TDK | C1608 series | CONTROLLER | no
C24 | 2.2uF low-ESR | Capacitor_SMD:C_0603_1608Metric | TDK | C1608 series | CONTROLLER | no
C25 | 2.2uF low-ESR | Capacitor_SMD:C_0603_1608Metric | TDK | C1608 series | CONTROLLER | no
C26 | 100nF | Capacitor_SMD:C_0603_1608Metric | TDK | C1608 series | CONTROLLER | no
C27 | 1uF | Capacitor_SMD:C_0603_1608Metric | TDK | C1608 series | CONTROLLER | no
C28 | 100nF | Capacitor_SMD:C_0603_1608Metric | TDK | C1608 series | CONTROLLER | no
C29 | 100nF | Capacitor_SMD:C_0603_1608Metric | TDK | C1608 series | CONTROLLER | no
C3 | 100nF 100V | Capacitor_SMD:C_0603_1608Metric | TDK | C1608 X7R series | POWER | no
C30 | 100nF | Capacitor_SMD:C_0603_1608Metric | TDK | C1608X7R1H104K080AA | STORAGE_SERVICE | no | MLCC; verify voltage derating
C31 | 100nF | Capacitor_SMD:C_0603_1608Metric | TDK | C1608X7R1H104K080AA | STORAGE_SERVICE | no | MLCC; verify voltage derating
C32 | 100nF | Capacitor_SMD:C_0603_1608Metric | TDK | C1608X7R1H104K080AA | STORAGE_SERVICE | no | MLCC; verify voltage derating
C33 | 1uF 10V | Capacitor_SMD:C_0603_1608Metric | TDK | C1608 X7R series | POWER | no
C4 | 10uF 16V | Capacitor_SMD:C_0603_1608Metric | TDK | C1608 X7R series | POWER | no
C40 | 12pF C0G | Capacitor_SMD:C_0603_1608Metric | TDK | C1608C0G1H120J080AA | NETWORK | no | MLCC; verify voltage derating
C41 | 12pF C0G | Capacitor_SMD:C_0603_1608Metric | TDK | C1608C0G1H120J080AA | NETWORK | no | MLCC; verify voltage derating
C42 | 1uF | Capacitor_SMD:C_0603_1608Metric | TDK | C1608X7R1E105K080AC | NETWORK | no | MLCC; verify voltage derating
C43 | 100nF | Capacitor_SMD:C_0603_1608Metric | TDK | C1608X7R1H104K080AA | NETWORK | no | MLCC; verify voltage derating
C44 | 100nF | Capacitor_SMD:C_0603_1608Metric | TDK | C1608X7R1H104K080AA | NETWORK | no | MLCC; verify voltage derating
C45 | 10uF | Capacitor_SMD:C_0603_1608Metric | TDK | C1608X5R1A106M080AC | NETWORK | no | MLCC; verify voltage derating
C46 | 10uF | Capacitor_SMD:C_0805_2012Metric | TDK | C1608X5R1A106M080AC | NETWORK | yes | MLCC; verify voltage derating
C5 | 10uF 16V | Capacitor_SMD:C_0603_1608Metric | TDK | C1608 X7R series | POWER | no
C6 | 4.7nF | Capacitor_SMD:C_0603_1608Metric | TDK | C1608 X7R series | POWER | no
C60 | 10nF C0G | Capacitor_SMD:C_0603_1608Metric | TDK | C1608C0G1H103J080AA | ANALOG | no
C61 | 10nF C0G | Capacitor_SMD:C_0603_1608Metric | TDK | C1608C0G1H103J080AA | ANALOG | no
C62 | 10nF C0G | Capacitor_SMD:C_0603_1608Metric | TDK | C1608C0G1H103J080AA | ANALOG | no
C63 | 10nF C0G | Capacitor_SMD:C_0603_1608Metric | TDK | C1608C0G1H103J080AA | ANALOG | no
C64 | 10uF | Capacitor_SMD:C_0603_1608Metric | TDK | C1608X5R1A106M080AC | ANALOG | no | MLCC; verify voltage derating
C65 | 100nF | Capacitor_SMD:C_0603_1608Metric | TDK | C1608X7R1H104K080AA | ANALOG | no | MLCC; verify voltage derating
C66 | 10uF low-ESR | Capacitor_SMD:C_0603_1608Metric | TDK | C1608X5R1A106M080AC | ANALOG | no | MLCC; verify voltage derating
C67 | 10uF low-ESR | Capacitor_SMD:C_0603_1608Metric | TDK | C1608X5R1A106M080AC | ANALOG | no | MLCC; verify voltage derating
C7 | 22uF 10V | Capacitor_SMD:C_0603_1608Metric | TDK | C1608 X7R series | POWER | no
C8 | 22uF 10V | Capacitor_SMD:C_0603_1608Metric | TDK | C1608 X7R series | POWER | no
C80 | 10nF 100V | Capacitor_SMD:C_1206_3216Metric | TDK | C3216X7R2A103K160AA | DIGITAL_INPUT | no
C81 | 10nF 100V | Capacitor_SMD:C_1206_3216Metric | TDK | C3216X7R2A103K160AA | DIGITAL_INPUT | no
C82 | 10nF 100V | Capacitor_SMD:C_1206_3216Metric | TDK | C3216X7R2A103K160AA | DIGITAL_INPUT | no
C83 | 10nF 100V | Capacitor_SMD:C_1206_3216Metric | TDK | C3216X7R2A103K160AA | DIGITAL_INPUT | no
C84 | 100nF | Capacitor_SMD:C_0603_1608Metric | TDK | C1608X7R1H104K080AA | DIGITAL_INPUT | no | MLCC; verify voltage derating
C85 | 100nF | Capacitor_SMD:C_0603_1608Metric | TDK | C1608X7R1H104K080AA | DIGITAL_INPUT | no | MLCC; verify voltage derating
C9 | 10nF | Capacitor_SMD:C_0603_1608Metric | TDK | C1608 X7R series | POWER | no
C90 | 100nF | Capacitor_SMD:C_0603_1608Metric | TDK | C1608X7R1H104K080AA | ISOLATED_BUSES | no | MLCC; verify voltage derating
C91 | 2.2uF 10V | Capacitor_SMD:C_0805_2012Metric | TDK | C2012X7R1A225K125AC | ISOLATED_BUSES | no | MLCC; verify voltage derating
C92 | 100nF | Capacitor_SMD:C_0603_1608Metric | TDK | C1608X7R1H104K080AA | ISOLATED_BUSES | no | MLCC; verify voltage derating
C93 | 2.2uF 10V | Capacitor_SMD:C_0805_2012Metric | TDK | C2012X7R1A225K125AC | ISOLATED_BUSES | no | MLCC; verify voltage derating
C94 | 100nF | Capacitor_SMD:C_0805_2012Metric | TDK | C1608X7R1H104K080AA | ISOLATED_BUSES | no | MLCC; verify voltage derating
C95 | 2.2uF | Capacitor_SMD:C_0805_2012Metric | TDK | C2012X7R1A225K125AC | ISOLATED_BUSES | no | MLCC; verify voltage derating
D1 | SMBJ36A | Diode_SMD:D_SMB | Littelfuse | SMBJ36A | POWER | no
D10 | SMAJ12A | Diode_SMD:D_SMA | Littelfuse | SMAJ12A | ANALOG | no
D11 | SMAJ12A | Diode_SMD:D_SMA | Littelfuse | SMAJ12A | ANALOG | no
D12 | SMAJ12A | Diode_SMD:D_SMA | Littelfuse | SMAJ12A | ANALOG | no
D13 | SMAJ12A | Diode_SMD:D_SMA | Littelfuse | SMAJ12A | ANALOG | no
D14 | SMAJ33A | Diode_SMD:D_SMA | Littelfuse | SMAJ33A | DIGITAL_INPUT | no
D15 | SMAJ33A | Diode_SMD:D_SMA | Littelfuse | SMAJ33A | DIGITAL_INPUT | no
D16 | SMAJ33A | Diode_SMD:D_SMA | Littelfuse | SMAJ33A | DIGITAL_INPUT | no
D17 | SMAJ33A | Diode_SMD:D_SMA | Littelfuse | SMAJ33A | DIGITAL_INPUT | no
D18 | SM712 | Package_TO_SOT_SMD:SOT-23 | Littelfuse | SM712-02HTG | ISOLATED_BUSES | no
D19 | SM712 | Package_TO_SOT_SMD:SOT-23 | Littelfuse | SM712-02HTG | ISOLATED_BUSES | no
D2 | SS56 60V/5A | Diode_SMD:D_SMB | Diodes Inc. | SS56-13-F | POWER | no | Series reverse-polarity protection
D20 | SM712 | Package_TO_SOT_SMD:SOT-23 | Littelfuse | SM712-02HTG | ISOLATED_BUSES | no
D3 | RUN GREEN | LED_SMD:LED_0603_1608Metric | Wurth | 0603 green LED | CONTROLLER | no
D4 | FAULT RED | LED_SMD:LED_0603_1608Metric | Wurth | 0603 red LED | CONTROLLER | no
F1 | 2A resettable | Fuse:Fuse_1812_4532Metric | Littelfuse | 1812L200/33 | POWER | no
FB1 | 600R@100MHz | Inductor_SMD:L_0603_1608Metric | Murata | BLM18AG601SN1D | CONTROLLER | no
FB2 | 600R@100MHz | Inductor_SMD:L_0603_1608Metric | Murata | BLM18AG601SN1D | NETWORK | no
FB3 | 600R@100MHz | Inductor_SMD:L_0603_1608Metric | Murata | BLM18AG601SN1D | ANALOG | no
J1 | POWER 9–36V / RETURN / CHASSIS | TerminalBlock_Phoenix:TerminalBlock_Phoenix_MKDS-1,5-3-5.08_1x03_P5.08mm_Horizontal | Phoenix Contact | 1715035 equivalent | POWER | no | Field power terminal, 5.08 mm pitch
J10 | AI1 / AGND | TerminalBlock_Phoenix:TerminalBlock_Phoenix_MKDS-1,5-2-5.08_1x02_P5.08mm_Horizontal | Phoenix Contact | MKDS 1,5/2-5,08 | ANALOG | no
J11 | AI2 / AGND | TerminalBlock_Phoenix:TerminalBlock_Phoenix_MKDS-1,5-2-5.08_1x02_P5.08mm_Horizontal | Phoenix Contact | MKDS 1,5/2-5,08 | ANALOG | no
J12 | AI3 / AGND | TerminalBlock_Phoenix:TerminalBlock_Phoenix_MKDS-1,5-2-5.08_1x02_P5.08mm_Horizontal | Phoenix Contact | MKDS 1,5/2-5,08 | ANALOG | no
J13 | AI4 / AGND | TerminalBlock_Phoenix:TerminalBlock_Phoenix_MKDS-1,5-2-5.08_1x02_P5.08mm_Horizontal | Phoenix Contact | MKDS 1,5/2-5,08 | ANALOG | no
J14 | DI1 / DI2 / DI3 / DI4 / FIELD COM | TerminalBlock_Phoenix:TerminalBlock_Phoenix_MKDS-1,5-5-5.08_1x05_P5.08mm_Horizontal | Phoenix Contact | MKDS 1,5/5-5,08 | DIGITAL_INPUT | no
J15 | RS-485 A: A+ / B- / ISO GND | TerminalBlock_Phoenix:TerminalBlock_Phoenix_MKDS-1,5-3-5.08_1x03_P5.08mm_Horizontal | Phoenix Contact | MKDS 1,5/3-5,08 | ISOLATED_BUSES | no
J16 | RS-485 B: A+ / B- / ISO GND | TerminalBlock_Phoenix:TerminalBlock_Phoenix_MKDS-1,5-3-5.08_1x03_P5.08mm_Horizontal | Phoenix Contact | MKDS 1,5/3-5,08 | ISOLATED_BUSES | no
J17 | CAN-H / CAN-L / ISO GND | TerminalBlock_Phoenix:TerminalBlock_Phoenix_MKDS-1,5-3-5.08_1x03_P5.08mm_Horizontal | Phoenix Contact | MKDS 1,5/3-5,08 | ISOLATED_BUSES | no
J2 | ARM SWD 10-pin | Connector_PinHeader_1.27mm:PinHeader_2x05_P1.27mm_Vertical_SMD | Samtec | FTSH-105-01-L-DV-K | CONTROLLER | no
J3 | MICROSD INDUSTRIAL | Connector_Card:microSD_HC_Molex_104031-0811 | Molex | 104031-0811 | STORAGE_SERVICE | no
J4 | USB-C SERVICE DEVICE | Connector_USB:USB_C_Receptacle_GCT_USB4105-xx-A_16P_TopMnt_Horizontal | GCT | USB4105-GF-A | STORAGE_SERVICE | no
J5 | RJ45 MAGJACK 10/100 | Connector_RJ:RJ45_Hanrun_HR911105A_Horizontal | HanRun | HR911105A | NETWORK | no
J6 | SERVICE / EXPANSION | Connector_PinHeader_2.54mm:PinHeader_1x08_P2.54mm_Vertical | Würth Elektronik | 61300811121 | CONTROLLER | no | 1x8 vertical 2.54 mm service header
JP1 | AI1 CURRENT MODE | Jumper:SolderJumper-2_P1.3mm_Open_Pad1.0x1.5mm | PCB feature | N/A | ANALOG | no | Close only for 4–20 mA mode
JP2 | AI2 CURRENT MODE | Jumper:SolderJumper-2_P1.3mm_Open_Pad1.0x1.5mm | PCB feature | N/A | ANALOG | no | Close only for 4–20 mA mode
JP3 | AI3 CURRENT MODE | Jumper:SolderJumper-2_P1.3mm_Open_Pad1.0x1.5mm | PCB feature | N/A | ANALOG | no | Close only for 4–20 mA mode
JP4 | AI4 CURRENT MODE | Jumper:SolderJumper-2_P1.3mm_Open_Pad1.0x1.5mm | PCB feature | N/A | ANALOG | no | Close only for 4–20 mA mode
JP5 | 120R TERMINATION ENABLE | Jumper:SolderJumper-2_P1.3mm_Open_Pad1.0x1.5mm | PCB feature | N/A | ISOLATED_BUSES | no | Solder-selectable jumper
JP6 | 120R TERMINATION ENABLE | Jumper:SolderJumper-2_P1.3mm_Open_Pad1.0x1.5mm | PCB feature | N/A | ISOLATED_BUSES | no | Solder-selectable jumper
JP7 | CAN 120R TERMINATION | Jumper:SolderJumper-2_P1.3mm_Open_Pad1.0x1.5mm | PCB feature | N/A | ISOLATED_BUSES | no | Solder-selectable jumper
L1 | 10uH input EMI | Inductor_SMD:L_12x12mm_H6mm | Bourns | SRP1265A-100M | POWER | no
L2 | 10uH / 4.5A | Inductor_SMD:L_10.4x10.4_H4.8 | Coilcraft | XAL1010-103 | POWER | no
L3 | 2.2uH / 4A | Inductor_SMD:L_6.3x6.3_H3 | Coilcraft | XFL6030-222 | POWER | no
R1 | 40.2k 1% | Resistor_SMD:R_0603_1608Metric | Yageo | RC0603FR series | POWER | no
R10 | 10k | Resistor_SMD:R_0603_1608Metric | Yageo | RC0603FR-0710KL | CONTROLLER | no
R11 | 100k | Resistor_SMD:R_0603_1608Metric | Yageo | RC0603FR-07100KL | CONTROLLER | no
R12 | 1k | Resistor_SMD:R_0603_1608Metric | Yageo | RC0603FR-071KL | CONTROLLER | no | Thick-film resistor
R13 | 1k | Resistor_SMD:R_0603_1608Metric | Yageo | RC0603FR-071KL | CONTROLLER | no | Thick-film resistor
R14 | 330k 1% | Resistor_SMD:R_0603_1608Metric | Yageo | RC0603FR series | CONTROLLER | no
R15 | 33k 1% | Resistor_SMD:R_0603_1608Metric | Yageo | RC0603FR series | CONTROLLER | no
R16 | 100k 1% | Resistor_SMD:R_0603_1608Metric | Yageo | RC0603FR series | CONTROLLER | no
R17 | 200k 1% | Resistor_SMD:R_0603_1608Metric | Yageo | RC0603FR series | CONTROLLER | no
R18 | 10k 1% | Resistor_SMD:R_0603_1608Metric | Yageo | RC0603FR series | CONTROLLER | no
R19 | 100k 1% | Resistor_SMD:R_0603_1608Metric | Yageo | RC0603FR series | CONTROLLER | no
R2 | 10.0k 1% | Resistor_SMD:R_0603_1608Metric | Yageo | RC0603FR series | POWER | no
R20 | 4.7k | Resistor_SMD:R_0603_1608Metric | Yageo | RC0603FR series | STORAGE_SERVICE | no
R21 | 4.7k | Resistor_SMD:R_0603_1608Metric | Yageo | RC0603FR series | STORAGE_SERVICE | no
R22 | 10k | Resistor_SMD:R_0603_1608Metric | Yageo | RC0603FR-0710KL | STORAGE_SERVICE | no | Thick-film resistor
R23 | 5.1k | Resistor_SMD:R_0603_1608Metric | Yageo | RC0603FR-075K1L | STORAGE_SERVICE | no | Thick-film resistor
R24 | 5.1k | Resistor_SMD:R_0603_1608Metric | Yageo | RC0603FR-075K1L | STORAGE_SERVICE | no | Thick-film resistor
R25 | 100k | Resistor_SMD:R_0603_1608Metric | Yageo | RC0603FR-07100KL | STORAGE_SERVICE | no | Thick-film resistor
R26 | 33k | Resistor_SMD:R_0603_1608Metric | Yageo | RC0603FR-0733KL | STORAGE_SERVICE | no | Thick-film resistor
R27 | 10k | Resistor_SMD:R_0603_1608Metric | Yageo | RC0603FR-0710KL | STORAGE_SERVICE | no | Thick-film resistor
R28 | 10k | Resistor_SMD:R_0603_1608Metric | Yageo | RC0603FR-0710KL | STORAGE_SERVICE | no | Thick-film resistor
R3 | 150k 1% | Resistor_SMD:R_0603_1608Metric | Yageo | RC0603FR series | POWER | no
R4 | 33k 1% | Resistor_SMD:R_0603_1608Metric | Yageo | RC0603FR series | POWER | no
R40 | 12.1k 1% | Resistor_SMD:R_0603_1608Metric | Yageo | RC0603FR-0712K1L | NETWORK | no | Thick-film resistor
R41 | 49.9R 1% | Resistor_SMD:R_0603_1608Metric | Yageo | RC0603FR-0749R9L | NETWORK | no | Thick-film resistor
R42 | 49.9R 1% | Resistor_SMD:R_0603_1608Metric | Yageo | RC0603FR-0749R9L | NETWORK | no | Thick-film resistor
R43 | 49.9R 1% | Resistor_SMD:R_0603_1608Metric | Yageo | RC0603FR-0749R9L | NETWORK | no | Thick-film resistor
R44 | 49.9R 1% | Resistor_SMD:R_0603_1608Metric | Yageo | RC0603FR-0749R9L | NETWORK | no | Thick-film resistor
R45 | 10k | Resistor_SMD:R_0603_1608Metric | Yageo | RC0603FR-0710KL | NETWORK | no | Thick-film resistor
R46 | 1k | Resistor_SMD:R_0603_1608Metric | Yageo | RC0603FR-071KL | NETWORK | no | Thick-film resistor
R47 | 1k | Resistor_SMD:R_0603_1608Metric | Yageo | RC0603FR-071KL | NETWORK | no | Thick-film resistor
R48 | 10k | Resistor_SMD:R_0603_1608Metric | Yageo | RC0603FR-0710KL | NETWORK | yes | Thick-film resistor
R49 | 10k | Resistor_SMD:R_0603_1608Metric | Yageo | RC0603FR-0710KL | NETWORK | yes | Thick-film resistor
R5 | 100k 1% | Resistor_SMD:R_0603_1608Metric | Yageo | RC0603FR series | POWER | no
R6 | 10k | Resistor_SMD:R_0603_1608Metric | Yageo | RC0603FR series | POWER | no
R60 | 249R 0.1% 25ppm | Resistor_SMD:R_0805_2012Metric | Vishay | TNPW0805249RBEEN | ANALOG | no
R61 | 1k 0.1% | Resistor_SMD:R_0603_1608Metric | Vishay | TNPW06031K00BEEA | ANALOG | no
R62 | 249R 0.1% 25ppm | Resistor_SMD:R_0805_2012Metric | Vishay | TNPW0805249RBEEN | ANALOG | no
R63 | 1k 0.1% | Resistor_SMD:R_0603_1608Metric | Vishay | TNPW06031K00BEEA | ANALOG | no
R64 | 249R 0.1% 25ppm | Resistor_SMD:R_0805_2012Metric | Vishay | TNPW0805249RBEEN | ANALOG | no
R65 | 1k 0.1% | Resistor_SMD:R_0603_1608Metric | Vishay | TNPW06031K00BEEA | ANALOG | no
R66 | 249R 0.1% 25ppm | Resistor_SMD:R_0805_2012Metric | Vishay | TNPW0805249RBEEN | ANALOG | no
R67 | 1k 0.1% | Resistor_SMD:R_0603_1608Metric | Vishay | TNPW06031K00BEEA | ANALOG | no
R68 | 0R star link | Resistor_SMD:R_0805_2012Metric | Yageo | RC0805JR-070RL | ANALOG | no | Single controlled analog/digital ground link
R80 | 1.00k 1% RTHR | Resistor_SMD:R_1206_3216Metric | Yageo | RC1206FR-071KL | DIGITAL_INPUT | no
R81 | 562R 1% RSENSE | Resistor_SMD:R_1206_3216Metric | Yageo | RC1206FR-07562RL | DIGITAL_INPUT | no
R82 | 1.00k 1% RTHR | Resistor_SMD:R_1206_3216Metric | Yageo | RC1206FR-071KL | DIGITAL_INPUT | no
R83 | 562R 1% RSENSE | Resistor_SMD:R_1206_3216Metric | Yageo | RC1206FR-07562RL | DIGITAL_INPUT | no
R84 | 1.00k 1% RTHR | Resistor_SMD:R_1206_3216Metric | Yageo | RC1206FR-071KL | DIGITAL_INPUT | no
R85 | 562R 1% RSENSE | Resistor_SMD:R_1206_3216Metric | Yageo | RC1206FR-07562RL | DIGITAL_INPUT | no
R86 | 1.00k 1% RTHR | Resistor_SMD:R_1206_3216Metric | Yageo | RC1206FR-071KL | DIGITAL_INPUT | no
R87 | 562R 1% RSENSE | Resistor_SMD:R_1206_3216Metric | Yageo | RC1206FR-07562RL | DIGITAL_INPUT | no
R90 | 120R 1% | Resistor_SMD:R_1206_3216Metric | Yageo | RC1206FR-07120RL | ISOLATED_BUSES | no | Thick-film resistor
R91 | 10k | Resistor_SMD:R_0603_1608Metric | Yageo | RC0603FR-0710KL | ISOLATED_BUSES | no | Thick-film resistor
R92 | 120R 1% | Resistor_SMD:R_1206_3216Metric | Yageo | RC1206FR-07120RL | ISOLATED_BUSES | no | Thick-film resistor
R93 | 10k | Resistor_SMD:R_0603_1608Metric | Yageo | RC0603FR-0710KL | ISOLATED_BUSES | no | Thick-film resistor
R94 | 120R 1% | Resistor_SMD:R_1206_3216Metric | Yageo | RC1206FR-07120RL | ISOLATED_BUSES | no | Thick-film resistor
R95 | 10k | Resistor_SMD:R_0603_1608Metric | Yageo | RC0603FR-0710KL | ISOLATED_BUSES | no | Thick-film resistor
SW1 | RESET | Button_Switch_SMD:SW_SPST_TL3342 | E-Switch | TL3342F160QG | CONTROLLER | no
SW2 | BOOT | Button_Switch_SMD:SW_SPST_TL3342 | E-Switch | TL3342F160QG | CONTROLLER | no
U1 | LM76002RNPR | Package_DFN_QFN:Texas_RNP0030B_WQFN-30-1EP_4x6mm_P0.5mm_EP1.8x4.5mm_ThermalVias | Texas Instruments | LM76002RNPR | POWER | no | 60 V, 2.5 A synchronous buck regulator
U10 | ISO1212DBQ | Package_SO:SSOP-16_3.9x4.9mm_P0.635mm | Texas Instruments | ISO1212DBQ | DIGITAL_INPUT | no
U11 | ISO1212DBQ | Package_SO:SSOP-16_3.9x4.9mm_P0.635mm | Texas Instruments | ISO1212DBQ | DIGITAL_INPUT | no
U12 | ISOW1412DFMR | Package_SO:SOIC-20W_7.5x12.8mm_P1.27mm | Texas Instruments | ISOW1412DFMR | ISOLATED_BUSES | no
U13 | ISOW1412DFMR | Package_SO:SOIC-20W_7.5x12.8mm_P1.27mm | Texas Instruments | ISOW1412DFMR | ISOLATED_BUSES | no
U14 | ISOW1044DFMR | Package_SO:SOIC-20W_7.5x12.8mm_P1.27mm | Texas Instruments | ISOW1044DFMR | ISOLATED_BUSES | no | Isolated CAN-FD transceiver with integrated power
U2 | TPS62132RGTR | Package_DFN_QFN:VQFN-16-1EP_3x3mm_P0.5mm_EP1.68x1.68mm_ThermalVias | Texas Instruments | TPS62132RGTR | POWER | no | 3 A fixed 3.3 V synchronous buck regulator
U3 | STM32H563ZIT6 | Package_QFP:LQFP-144_20x20mm_P0.5mm | STMicroelectronics | STM32H563ZIT6 | CONTROLLER | no | Cortex-M33 MCU, 2 MB flash, 640 KB RAM, LQFP-144
U4 | RV-3028-C7 | Package_SON:MicroCrystal_C7_SON-8_1.5x3.2mm_P0.9mm | Micro Crystal | RV-3028-C7 | STORAGE_SERVICE | no
U5 | W25Q128JVSIQ | Package_SO:SOIC-8_5.3x5.3mm_P1.27mm | Winbond | W25Q128JVSIQ | STORAGE_SERVICE | no
U6 | USBLC6-2SC6 | Package_TO_SOT_SMD:SOT-23-6 | STMicroelectronics | USBLC6-2SC6 | STORAGE_SERVICE | no
U7 | LAN8742Ai-CZ-TR | Package_DFN_QFN:VQFN-24-1EP_4x4mm_P0.5mm_EP2.5x2.5mm_ThermalVias | Microchip | LAN8742Ai-CZ-TR | NETWORK | no
U8 | ESP32-C3-WROOM-02 | RF_Module:ESP32-C3-WROOM-02 | Espressif | ESP32-C3-WROOM-02-N4 | NETWORK | yes | Optional Wi-Fi coprocessor; STM32 remains authority
U9 | ADS8684IDBT | Package_SO:TSSOP-38_4.4x9.7mm_P0.5mm | Texas Instruments | ADS8684IDBT | ANALOG | no | 4-channel 16-bit 500 kSPS bipolar-input SAR ADC
Y1 | 25MHz 10pF | Crystal:Crystal_SMD_3215-2Pin_3.2x1.5mm | Abracon | industrial crystal equivalent | CONTROLLER | no
Y2 | 32.768kHz 12.5pF | Crystal:Crystal_SMD_3215-2Pin_3.2x1.5mm | Abracon | industrial crystal equivalent | CONTROLLER | no
Y3 | 25MHz 10pF | Crystal:Crystal_SMD_3215-2Pin_3.2x1.5mm | Abracon | ABM8-25.000MHZ series | NETWORK | no

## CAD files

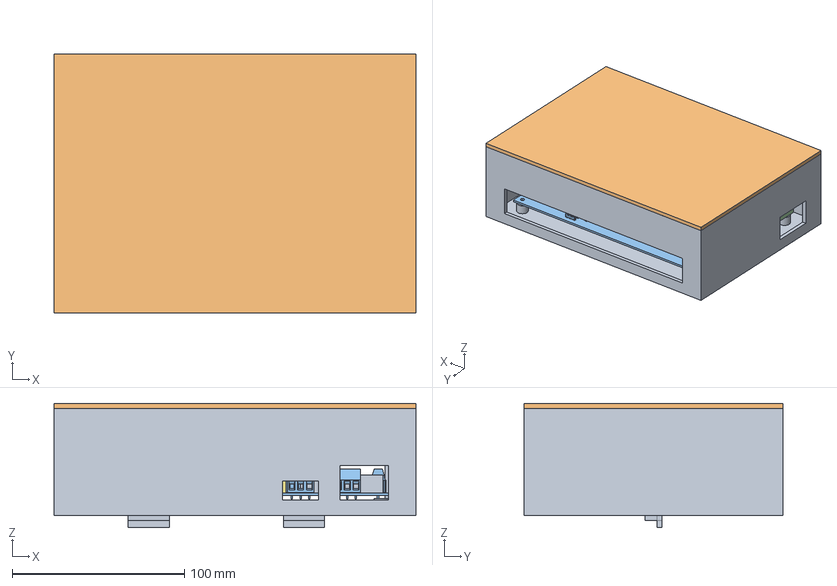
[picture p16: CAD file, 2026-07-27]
mechanical/native/edge18-rev-a-assembly.FCStd
210.0 x 150.0 x 72.0 mm
EDGE-18 Rev. A aluminum base
EDGE-18 Rev. A removable lid
EDGE-18 Rev. A PCB assembly
Power/protection envelope
Analog input envelope
Digital input envelope
STM32 and storage envelope
RS-485 and CAN isolation envelope
Ethernet PHY and magnetics envelope
Wi-Fi antenna keep-out envelope

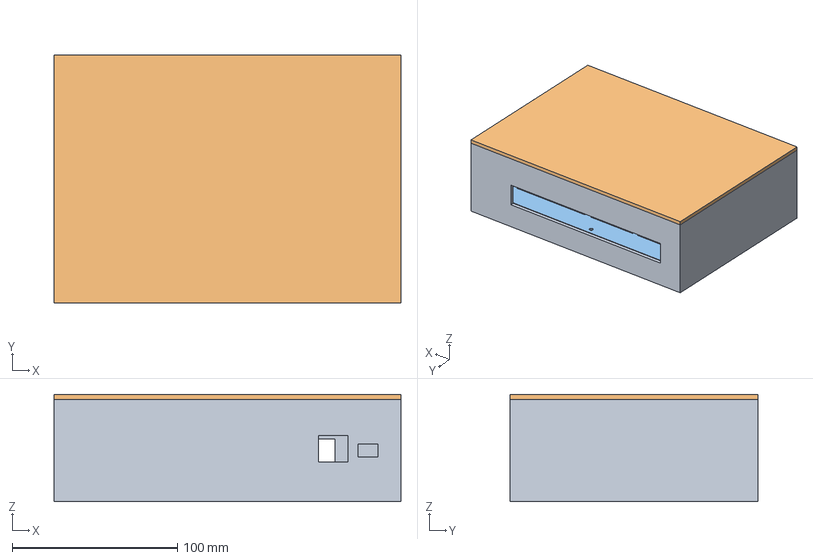
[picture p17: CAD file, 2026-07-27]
mechanical/native/edge18-p0-assembly.FCStd
210.0 x 150.0 x 65.0 mm
EDGE-18 P0 aluminum base
EDGE-18 P0 removable lid
EDGE-18 P0 PCB 180 x 120 mm
Power/protection envelope
Analog input envelope
Digital input envelope
STM32 and storage envelope
RS-485 and CAN isolation envelope
Ethernet PHY and magnetics envelope
Wi-Fi antenna keep-out envelope

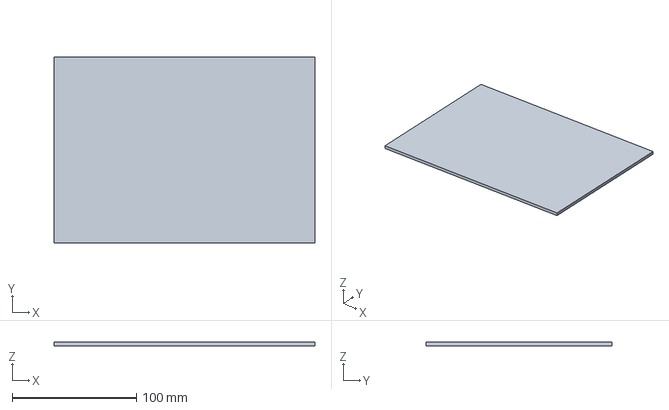
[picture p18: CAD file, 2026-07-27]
mechanical/step/edge18-rev-a-enclosure-lid.step
210.0 x 150.0 x 3.00 mm

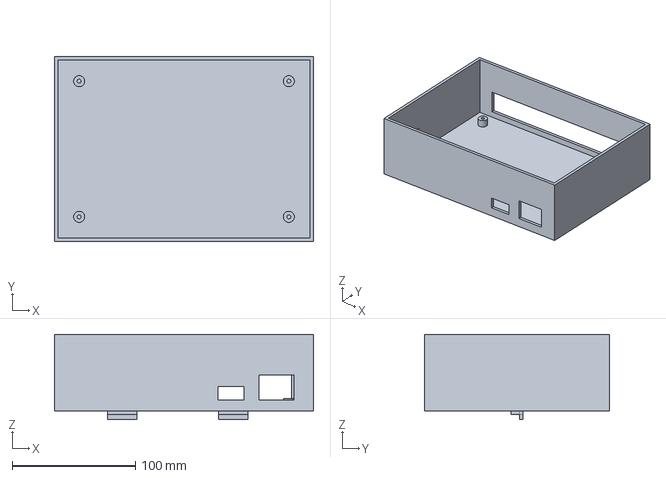
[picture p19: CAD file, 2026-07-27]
mechanical/step/edge18-rev-a-enclosure-base.step
210.0 x 150.0 x 69.0 mm

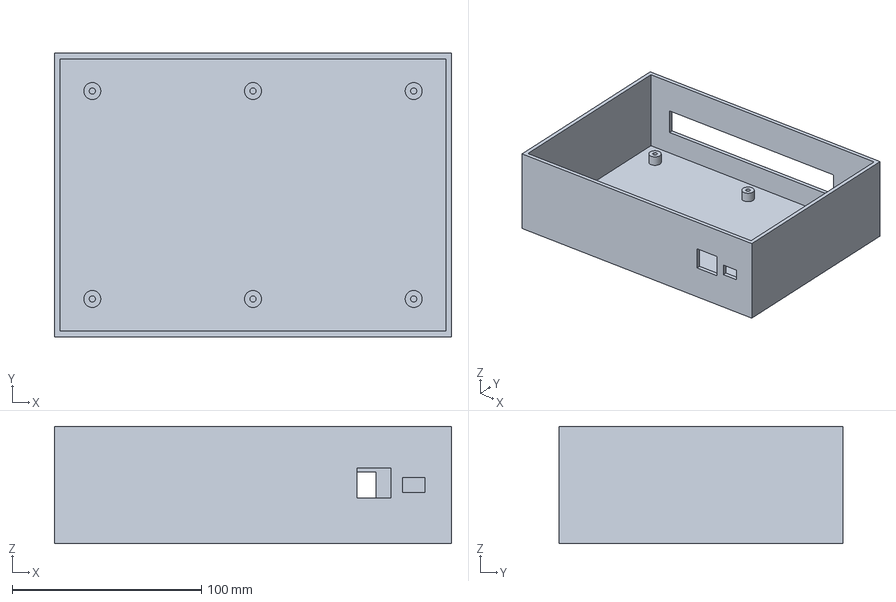
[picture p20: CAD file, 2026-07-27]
mechanical/step/edge18-p0-enclosure-base.step
210.0 x 150.0 x 62.0 mm

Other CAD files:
mechanical/step/edge18-p0-assembly.step
mechanical/step/edge18-p0-enclosure-lid.step

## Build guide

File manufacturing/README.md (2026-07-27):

# Manufacturing

## Finalidade

Pacote de fabricação, montagem e implantação.

## Entregáveis futuros

- Gerbers/BOM/posição
- instruções de montagem
- gabarito de fim de linha
- as-built

## Estado Rev. A congelada

Nenhum pacote de fabricação foi emitido. A PCB tem 43 ocorrências de DRC e 24
conexões abertas; portanto, Gerbers, arquivos de posição e ordens de montagem
estão bloqueados. A evidência está em
[`../docs/17-estado-da-pcb-rev-a.md`](../docs/17-estado-da-pcb-rev-a.md).

`tools/export-release.sh` mantém o gate técnico: ele só gera o pacote quando
ERC e DRC estiverem limpos.

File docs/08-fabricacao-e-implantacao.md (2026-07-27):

# Fabricação e implantação

## Estratégia inicial

- simuladores Modbus
- perfis de equipamentos
- painel industrial piloto
- programa de integradores

## Conteúdo previsto para um futuro pacote de fabricação

- Gerbers X2 das quatro camadas, máscaras, serigrafias e contorno;
- furação PTH/NPTH separada, mapa de furos e IPC-D-356;
- posição CSV sem itens DNP, BOM de fonte e BOM agrupada;
- esquemático e desenho de montagem em PDF;
- fonte mecânica FreeCAD e STEP da PCB/conjunto;
- especificação de PCB, material, cobre, acabamento e teste elétrico;
- instruções de montagem, torque, chicote, isolação e inspeção;
- firmware de produção, provisionamento e gabarito de fim de linha;
- etiqueta com projeto, revisão, número de série e avisos.

## Implantação

1. levantamento e registro do local;
2. conferência de compatibilidade e riscos;
3. instalação conforme desenho;
4. testes de aceitação do site;
5. backup da configuração e fotos;
6. entrega do as-built e treinamento;
7. janela de observação e plano de rollback.

O comando abaixo só conclui se ERC e DRC estiverem limpos e gera hashes e ZIP:

```bash
./tools/export-release.sh
```

Saídas futuras: `release/edge18-rev-a/` e `release/edge18-rev-a.zip`.

Na baseline congelada de 27 de julho de 2026, o comando falha corretamente
porque há 43 ocorrências de DRC e 24 conexões abertas. Nenhum Gerber foi
liberado. O relatório está em
[`reports/edge18-main-rev-a-drc.rpt`](reports/edge18-main-rev-a-drc.rpt).

Mesmo após um DRC limpo, o pacote não elimina análise DFM do fabricante,
inspeção de primeira peça, bring-up controlado, ensaio térmico, surto/EFT/ESD,
emissões/imunidade, isolamento e certificação aplicável.

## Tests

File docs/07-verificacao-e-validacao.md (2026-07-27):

# Verificação e validação

## 1. Estado da evidência

`passou` significa que relatório e dados estão no repositório ou artefato
identificado. Código que compila não valida hardware. Simulação não substitui
ensaio.

## 2. Matriz P0

| ID | Teste | Critério | Estado |
|---|---|---|---|
| VT-CORE-01 | build C17 com warnings como erro | compila no host | passou |
| VT-CORE-02 | fila FIFO e wrap-around | ordem preservada | passou |
| VT-CORE-03 | overflow `reject-new` | item novo rejeitado sem perder antigo | passou |
| VT-CORE-04 | overflow `drop-oldest` | contador e itens corretos | passou |
| VT-CORE-05 | máscara de qualidade | bits independentes | passou |
| VT-CORE-06 | CRC Modbus | vetor conhecido `0xCDC5` | passou |
| VT-CFG-01 | schemas JSON | Draft 2020-12 válido | passou no host |
| VT-CFG-02 | exemplos | válidos e invariantes coerentes | passou no host |
| VT-EDA-01 | ERC KiCad Rev. A | 0 erros e 0 avisos | passou |
| VT-EDA-02 | DRC KiCad Rev. A | 0 violações e 0 conexões abertas | falhou: 43/24 |
| VT-EDA-03 | largura mínima presente | nenhum segmento abaixo de 0,25 mm | passou |
| VT-MEC-01 | modelo dimensional FreeCAD | gabinete 210 × 150 × 65 mm, PCB 180 × 120 mm e objetos esperados | passou |
| VT-PWR-01 | entrada 9–36 V | rails dentro da tolerância | pendente de hardware |
| VT-PWR-02 | inversão e brownout | sem dano/configuração parcial | pendente |
| VT-RS-01 | duas RS-485 | simultâneas, isoladas, matriz de baud/paridade | pendente |
| VT-MB-01 | funções Modbus de leitura | simulador e exceções | pendente |
| VT-AI-01 | 0–10 V | erro ≤ meta por canal | pendente |
| VT-AI-02 | 4–20 mA | erro e diagnósticos por canal | pendente |
| VT-DI-01 | limiares 24 V | quatro canais | pendente |
| VT-DI-02 | pulso | 10 kHz/50 µs | pendente |
| VT-ETH-01 | Ethernet | DHCP, estático, perda/retorno | pendente |
| VT-TLS-01 | autenticação | válido, expirado, revogado e relógio inválido | pendente |
| VT-MQ-01 | QoS 1/reconexão | duplicatas idempotentes | pendente |
| VT-BUF-01 | capacidade | 1.000.000 registros | pendente |
| VT-BUF-02 | corte de energia | 100 cortes sem corrupção além do registro parcial | pendente |
| VT-UPD-01 | imagem alterada | rejeitada | pendente |
| VT-UPD-02 | falha de boot | rollback preserva dados/configuração | pendente |
| VT-REL-01 | operação contínua | 30 dias sem travamento | pendente |
| VT-SEC-01 | portas e segredos | superfície conforme modelo; nenhum segredo em log | pendente |

## 3. Bancadas

### 3.1 Digital/firmware

- computador Linux;
- simulador Modbus;
- broker MQTT com CA de laboratório;
- injeção de perda, atraso, duplicação e corrupção;
- arquivos/cartões com falhas simuladas.

### 3.2 Elétrica

- fonte isolada programável com limite;
- multímetro calibrado;
- osciloscópio;
- gerador de função/pulsos;
- fonte 0–10 V e calibrador 4–20 mA;
- adaptadores RS-485/CAN isolados;
- câmera térmica ou termopares;
- carga eletrônica.

### 3.3 Pré-compliance

- ESD/EFT/surge somente depois da revisão de segurança;
- LISN/célula TEM quando disponível;
- captura de emissões do buck, Ethernet e Wi-Fi;
- ensaios repetidos nas configurações de terminação.

## 4. Evidência

Cada relatório contém:

- requisito/teste;
- commit e revisão de hardware;
- número de série;
- instrumentos e validade de calibração;
- diagrama de ligação;
- entradas, configuração e ambiente;
- dados brutos;
- resultado, anomalias e responsável;
- impacto sobre riscos e próximos gates.

O resultado de `VT-EDA-02` está preservado integralmente em
[`reports/edge18-main-rev-a-drc.rpt`](reports/edge18-main-rev-a-drc.rpt). A
falha é deliberadamente visível e bloqueia a fabricação.

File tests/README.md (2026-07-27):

# Tests

## Finalidade

Planos, fixtures, dados brutos e relatórios.

## Entregáveis esperados

- matriz de verificação
- procedimentos
- dados brutos
- relatórios por revisão/série

## Estado

Pasta reservada; não há artefato implementado na baseline de 2026-07-26. Quando
arquivos forem adicionados, este documento deverá indicar ferramenta, versão,
como regenerar/validar e qual requisito é atendido.

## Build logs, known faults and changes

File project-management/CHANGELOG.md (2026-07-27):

# Changelog

## 2026-07-27 — baseline de revisão digital congelada

- interrompidas novas tentativas de roteamento por decisão do responsável;
- congelada a PCB com 43 ocorrências de DRC e 24 conexões abertas;
- confirmado que não há trilha abaixo de 0,25 mm;
- adicionados relatórios ERC/DRC integrais e documento de estado da PCB;
- exportado STEP da PCB corrente;
- explicitado em toda a documentação que a revisão não está liberada para
  fabricação.

## 2026-07-26 — engenharia digital Rev. A

- criado esquemático KiCad com 195 símbolos e ERC limpo;
- criada PCB de quatro camadas com 181 itens, classes de 0,25 a 1,20 mm;
- selecionados ESP32-C3-WROOM-02 e ISOW1044 com footprints oficiais;
- congeladas bibliotecas de símbolos e criada BOM sem campos de fabricante/MPN
  vazios;
- implementados configuração, Modbus, scheduler, journal, telemetria, máquina
  de estados e manifesto de atualização em C17;
- criado pinout completo, extraído automaticamente do CAD;
- mantida a distinção entre revisão digital e validação do protótipo físico.

## 2026-07-26 — início do desenvolvimento G0

- aprovado o Projeto 18 como plataforma-pai;
- detalhados requisitos, arquitetura, hardware, software, segurança e testes;
- selecionados STM32H563, LAN8742A, ESP32-C3, ADS8684, ISO1212, ISOW1412,
  ISO1042 e LM76002 como referências P0;
- criados seis ADRs e matriz de reutilização;
- criados schemas e exemplos de configuração/telemetria;
- implementado núcleo C17 com ponto, qualidade, fila e CRC Modbus;
- adicionados testes host e CI;
- gerado e validado o conjunto dimensional P0 em FreeCAD e STEP;
- mantido o estado honesto: nenhum hardware físico existe.

## 2026-07-26

- criada a pasta do Projeto 18;
- importada a proposta do portfólio;
- criada baseline documental completa;
- criado controle de andamento, roadmap, backlog, decisões e riscos;
- estado definido honestamente como `concepção documentada`.

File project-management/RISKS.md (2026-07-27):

# Registro de riscos

| ID | Risco | Severidade | Tratamento | Estado |
|---|---|---|---|---|
| R-18-01 | plataforma genérica crescer sem limite | alto | MVP e contratos pequenos | aberto |
| R-18-02 | chave/firmware comprometidos | crítico | TrustZone, assinatura e provisionamento | aberto |
| R-18-03 | EMC/surto industrial | alto | isolação, proteção e pré-compliance | aberto |
| R-18-04 | analógicas não isoladas individualmente | alto | declarar referência comum e criar variante futura | aceito P0 |
| R-18-05 | consumo de Wi-Fi/microSD causar brownout | alto | orçamento, margem e ensaio de picos | aberto |
| R-18-06 | ruído do buck/Wi-Fi degradar ADC | alto | particionamento, filtros e ensaio | aberto |
| R-18-07 | ISOW1412 gerar emissões | médio | layout oficial, DNP/alternativa ISO1410+DC/DC | aberto |
| R-18-08 | disponibilidade de componentes | médio | lifecycle, estoque e substitutos antes da BOM | aberto |
| R-18-09 | corrupção do microSD | alto | journal, CRC, cortes e mídia qualificada | aberto |
| R-18-10 | filho bifurcar contratos | alto | releases e testes de contrato | mitigação iniciada |
| R-18-11 | usuário interpretar P0 como produto | crítico | status explícito e gates | mitigado documentalmente |
| R-18-12 | fabricar a PCB com conexões/DRC pendentes | crítico | bloquear Gerbers, relatório commitado e aviso em todos os artefatos | aberto; layout congelado |
| R-18-13 | colisão mecânica não vista por modelo 3D ausente | médio | obter STEP de dez referências e repetir inspeção | aberto |

Riscos são revisados em cada gate. Mitigação planejada não significa risco
fechado.

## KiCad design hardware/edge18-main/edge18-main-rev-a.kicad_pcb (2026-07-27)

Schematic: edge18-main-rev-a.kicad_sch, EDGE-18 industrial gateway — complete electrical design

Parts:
BT1: CR1220; BatteryHolder_Keystone_3000_1x12mm; MPN 3000
C1: 100uF 63V; C_1210_3225Metric; MPN X7R industrial equivalent
C2: 1uF 100V X7R; C_1210_3225Metric; MPN X7R industrial equivalent
C3: 100nF 100V; C_0603_1608Metric; MPN C1608 X7R series
C4, C5: 10uF 16V; C_0603_1608Metric; MPN C1608 X7R series
C6: 4.7nF; C_0603_1608Metric; MPN C1608 X7R series
C7, C8: 22uF 10V; C_0603_1608Metric; MPN C1608 X7R series
C9: 10nF; C_0603_1608Metric; MPN C1608 X7R series
C10: 10uF 10V; C_0603_1608Metric; MPN C1608 X7R series
C11, C12, C13, C14: 12pF C0G; C_0603_1608Metric; MPN C1608 series
C15, C16, C17, C18, C19, C20, C21, C22, C26, C28, C29: 100nF; C_0603_1608Metric; MPN C1608 series
C23: 4.7uF; C_0603_1608Metric; MPN C1608 series
C24, C25: 2.2uF low-ESR; C_0603_1608Metric; MPN C1608 series
C27: 1uF; C_0603_1608Metric; MPN C1608 series
C30, C31, C32, C43, C44, C65, C84, C85, C90, C92: 100nF; C_0603_1608Metric
C33: 1uF 10V; C_0603_1608Metric; MPN C1608 X7R series
C40, C41: 12pF C0G; C_0603_1608Metric
C42: 1uF; C_0603_1608Metric
C45, C64: 10uF; C_0603_1608Metric
C46: 10uF; C_0805_2012Metric; not fitted
C60, C61, C62, C63: 10nF C0G; C_0603_1608Metric; MPN C1608C0G1H103J080AA
C66, C67: 10uF low-ESR; C_0603_1608Metric
C80, C81, C82, C83: 10nF 100V; C_1206_3216Metric; MPN C3216X7R2A103K160AA
C91, C93: 2.2uF 10V; C_0805_2012Metric
C94: 100nF; C_0805_2012Metric
C95: 2.2uF; C_0805_2012Metric
D1: SMBJ36A; D_SMB; MPN SMBJ36A
D2: SS56 60V/5A; D_SMB; MPN SS56-13-F
D3: RUN GREEN; LED_0603_1608Metric; MPN 0603 green LED
D4: FAULT RED; LED_0603_1608Metric; MPN 0603 red LED
D10, D11, D12, D13: SMAJ12A; D_SMA; MPN SMAJ12A
D14, D15, D16, D17: SMAJ33A; D_SMA; MPN SMAJ33A
D18, D19, D20: SM712; SOT-23; MPN SM712-02HTG
F1: 2A resettable; Fuse_1812_4532Metric; MPN 1812L200/33
FB1, FB2, FB3: 600R@100MHz; L_0603_1608Metric; MPN BLM18AG601SN1D
J1: POWER 9–36V / RETURN / CHASSIS; TerminalBlock_Phoenix_MKDS-1,5-3-5.08_1x03_P5.08mm_Horizont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; MPN 1715035 equivalent
J2: ARM SWD 10-pin; PinHeader_2x05_P1.27mm_Vertical_SMD; MPN FTSH-105-01-L-DV-K
J3: MICROSD INDUSTRIAL; microSD_HC_Molex_104031-0811; MPN 104031-0811
J4: USB-C SERVICE DEVICE; USB_C_Receptacle_GCT_USB4105-xx-A_16P_TopMnt_Horizontal; MPN USB4105-GF-A
J5: RJ45 MAGJACK 10/100; RJ45_Hanrun_HR911105A_Horizontal; MPN HR911105A
J6: SERVICE / EXPANSION; PinHeader_1x08_P2.54mm_Vertical
J10: AI1 / AGND; TerminalBlock_Phoenix_MKDS-1,5-2-5.08_1x02_P5.08mm_Horizont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; MPN MKDS 1,5/2-5,08
J11: AI2 / AGND; TerminalBlock_Phoenix_MKDS-1,5-2-5.08_1x02_P5.08mm_Horizont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; MPN MKDS 1,5/2-5,08
J12: AI3 / AGND; TerminalBlock_Phoenix_MKDS-1,5-2-5.08_1x02_P5.08mm_Horizont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; MPN MKDS 1,5/2-5,08
J13: AI4 / AGND; TerminalBlock_Phoenix_MKDS-1,5-2-5.08_1x02_P5.08mm_Horizont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; MPN MKDS 1,5/2-5,08
J14: DI1 / DI2 / DI3 / DI4 / FIELD COM; TerminalBlock_Phoenix_MKDS-1,5-5-5.08_1x05_P5.08mm_Horizont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; MPN MKDS 1,5/5-5,08
J15: RS-485 A: A+ / B- / ISO GND; TerminalBlock_Phoenix_MKDS-1,5-3-5.08_1x03_P5.08mm_Horizont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; MPN MKDS 1,5/3-5,08
J16: RS-485 B: A+ / B- / ISO GND; TerminalBlock_Phoenix_MKDS-1,5-3-5.08_1x03_P5.08mm_Horizont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; MPN MKDS 1,5/3-5,08
J17: CAN-H / CAN-L / ISO GND; TerminalBlock_Phoenix_MKDS-1,5-3-5.08_1x03_P5.08mm_Horizont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; MPN MKDS 1,5/3-5,08
JP1: AI1 CURRENT MODE; SolderJumper-2_P1.3mm_Open_Pad1.0x1.5mm
JP2: AI2 CURRENT MODE; SolderJumper-2_P1.3mm_Open_Pad1.0x1.5mm
JP3: AI3 CURRENT MODE; SolderJumper-2_P1.3mm_Open_Pad1.0x1.5mm
JP4: AI4 CURRENT MODE; SolderJumper-2_P1.3mm_Open_Pad1.0x1.5mm
JP5, JP6: 120R TERMINATION ENABLE; SolderJumper-2_P1.3mm_Open_Pad1.0x1.5mm
JP7: CAN 120R TERMINATION; SolderJumper-2_P1.3mm_Open_Pad1.0x1.5mm
L1: 10uH input EMI; L_12x12mm_H6mm; MPN SRP1265A-100M
L2: 10uH / 4.5A; L_10.4x10.4_H4.8; MPN XAL1010-103
L3: 2.2uH / 4A; L_6.3x6.3_H3; MPN XFL6030-222
R1: 40.2k 1%; R_0603_1608Metric; MPN RC0603FR series
R2: 10.0k 1%; R_0603_1608Metric; MPN RC0603FR series
R3: 150k 1%; R_0603_1608Metric; MPN RC0603FR series
R4, R15: 33k 1%; R_0603_1608Metric; MPN RC0603FR series
R5, R16, R19: 100k 1%; R_0603_1608Metric; MPN RC0603FR series
R6: 10k; R_0603_1608Metric; MPN RC0603FR series
R10: 10k; R_0603_1608Metric; MPN RC0603FR-0710KL
R11: 100k; R_0603_1608Metric; MPN RC0603FR-07100KL
R12, R13, R46, R47: 1k; R_0603_1608Metric
R14: 330k 1%; R_0603_1608Metric; MPN RC0603FR series
R17: 200k 1%; R_0603_1608Metric; MPN RC0603FR series
R18: 10k 1%; R_0603_1608Metric; MPN RC0603FR series
R20, R21: 4.7k; R_0603_1608Metric; MPN RC0603FR series
R22, R27, R28, R45, R91, R93, R95: 10k; R_0603_1608Metric
R23, R24: 5.1k; R_0603_1608Metric
R25: 100k; R_0603_1608Metric
R26: 33k; R_0603_1608Metric
R40: 12.1k 1%; R_0603_1608Metric
R41, R42, R43, R44: 49.9R 1%; R_0603_1608Metric
R48, R49: 10k; R_0603_1608Metric; not fitted
R60, R62, R64, R66: 249R 0.1% 25ppm; R_0805_2012Metric; MPN TNPW0805249RBEEN
R61, R63, R65, R67: 1k 0.1%; R_0603_1608Metric; MPN TNPW06031K00BEEA
R68: 0R star link; R_0805_2012Metric
R80, R82, R84, R86: 1.00k 1% RTHR; R_1206_3216Metric; MPN RC1206FR-071KL
R81, R83, R85, R87: 562R 1% RSENSE; R_1206_3216Metric; MPN RC1206FR-07562RL
R90, R92, R94: 120R 1%; R_1206_3216Metric
SW1: RESET; SW_SPST_TL3342; MPN TL3342F160QG
SW2: BOOT; SW_SPST_TL3342; MPN TL3342F160QG
U1: LM76002RNPR; Texas_RNP0030B_WQFN-30-1EP_4x6mm_P0.5mm_EP1.8x4.5mm_Thermal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; MPN LM76002RNPR
U2: TPS62132RGTR; VQFN-16-1EP_3x3mm_P0.5mm_EP1.68x1.68mm_ThermalVias; MPN TPS62132RGTR
U3: STM32H563ZIT6; LQFP-144_20x20mm_P0.5mm; MPN STM32H563ZIT6
U4: RV-3028-C7; MicroCrystal_C7_SON-8_1.5x3.2mm_P0.9mm; MPN RV-3028-C7
U5: W25Q128JVSIQ; SOIC-8_5.3x5.3mm_P1.27mm; MPN W25Q128JVSIQ
U6: USBLC6-2SC6; SOT-23-6; MPN USBLC6-2SC6
U7: LAN8742Ai-CZ-TR; VQFN-24-1EP_4x4mm_P0.5mm_EP2.5x2.5mm_ThermalVias; MPN LAN8742Ai-CZ-TR
U8: ESP32-C3-WROOM-02; MPN ESP32-C3-WROOM-02-N4; not fitted
U9: ADS8684IDBT; TSSOP-38_4.4x9.7mm_P0.5mm; MPN ADS8684IDBT
U10, U11: ISO1212DBQ; SSOP-16_3.9x4.9mm_P0.635mm; MPN ISO1212DBQ
U12, U13: ISOW1412DFMR; SOIC-20W_7.5x12.8mm_P1.27mm; MPN ISOW1412DFMR
U14: ISOW1044DFMR; SOIC-20W_7.5x12.8mm_P1.27mm; MPN ISOW1044DFMR
Y1: 25MHz 10pF; Crystal_SMD_3215-2Pin_3.2x1.5mm; MPN industrial crystal equivalent
Y2: 32.768kHz 12.5pF; Crystal_SMD_3215-2Pin_3.2x1.5mm; MPN industrial crystal equivalent
Y3: 25MHz 10pF; Crystal_SMD_3215-2Pin_3.2x1.5mm; MPN ABM8-25.000MHZ series

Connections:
3V3: C7.1, C8.1, C15.1, C16.1, C17.1, C18.1, C19.1, C20.1, C21.1, C22.1, C23.1, C30.1, C31.1, C43.1, C46.1, C84.1, C85.1, C90.1, C92.1, C94.1, FB1.1, FB2.1, J2.1, J3.4 (VDD), J5.10, J5.12, J6.1, L3.2, R10.1, R18.1, R20.1, R21.1, R22.1, R27.1, R28.1, R45.1, R48.1, R49.1, R91.1, R93.1, R95.1, SW2.2, U2.5 (FB), U2.14 (VOS), U3.17 (VDD), U3.30 (VDD), U3.39 (VDD), U3.52 (VDD), U3.62 (VDD), U3.72 (VDD), U3.84 (VDD), U3.95 (VDD), U3.106 (VDDUSB), U3.108 (VDD), U3.121 (VDDIO2), U3.131 (VDD), U3.144 (VDD), U4.7 (VDD), U5.8 (VCC), U7.9 (VDDIO), U8.1 (3V3), U9.34 (DVDD), U10.2 (VCC1), U10.3 (EN), U11.2 (VCC1), U11.3 (EN), U12.1 (VIO), U13.1 (VIO), U14.1 (VIO)
3V3_A: C26.1, C27.1, FB1.2, U3.32 (VREF+), U3.33 (VDDA)
3V3_ETH: C44.1, C45.1, FB2.2, J5.4 (TCT), J5.5 (RCT), R41.1, R42.1, R43.1, R44.1, U7.1 (VDD2A), U7.19 (VDD1A)
3V3_MON: R18.2, R19.1, U3.29 (PC3)
3V3_RTC: BT1.1 (+), C28.1, U3.6 (VBAT), U4.6 (VBACKUP)
5V: C4.1, C5.1, C10.1, FB3.1, L2.2, R1.1, R6.1, R16.1, U1.9 (BIAS), U2.10 (VIN), U2.11 (VIN), U2.12 (VIN), U2.13 (EN), U12.9 (VDD), U13.9 (VDD), U14.9 (VDD)
5V_A: C64.1, C65.1, FB3.2, U9.9 (AVDD), U9.30 (AVDD)
5V_MON: R16.2, R17.1, U3.28 (PC2)
ADC_CS: U3.40 (PA4), U9.38 (~CS)
ADC_MISO: U3.42 (PA6), U9.36 (SDO)
ADC_MOSI: U3.135 (PB5), U9.1 (SDI)
ADC_REFCAP: C66.1, U9.7 (REFCAP)
ADC_REFIO: C67.1, U9.5 (REFIO)
ADC_RESET: U3.46 (PB0), U9.2 (~RST/PD)
ADC_SCK: U3.41 (PA5), U9.37 (SCLK)
AGND: C26.2, C27.2, C60.2, C61.2, C62.2, C63.2, C64.2, C65.2, C66.2, C67.2, D10.2 (A2), D11.2 (A2), D12.2 (A2), D13.2 (A2), J10.2, J11.2, J12.2, J13.2, R60.2, R62.2, R64.2, R66.2, R68.1, U3.31 (VSSA), U9.6 (REFGND), U9.8 (AGND), U9.11 (AUX_GND), U9.17 (AIN_0GND), U9.19 (AIN_1GND), U9.20 (AIN_2GND), U9.22 (AIN_3GND), U9.28 (AGND), U9.29 (AGND), U9.31 (AGND), U9.32 (AGND)
AI1_ADC: C60.1, R61.2, U9.16 (AIN_0P)
AI1_FIELD: D10.1 (A1), J10.1, JP1.1 (A), R61.1
AI1_SHUNT: JP1.2 (B), R60.1
AI2_ADC: C61.1, R63.2, U9.18 (AIN_1P)
AI2_FIELD: D11.1 (A1), J11.1, JP2.1 (A), R63.1
AI2_SHUNT: JP2.2 (B), R62.1
AI3_ADC: C62.1, R65.2, U9.21 (AIN_2P)
AI3_FIELD: D12.1 (A1), J12.1, JP3.1 (A), R65.1
AI3_SHUNT: JP3.2 (B), R64.1
AI4_ADC: C63.1, R67.2, U9.23 (AIN_3P)
AI4_FIELD: D13.1 (A1), J13.1, JP4.1 (A), R67.1
AI4_SHUNT: JP4.2 (B), R66.1
BOOT0: R11.1, SW2.1, U3.138 (BOOT0)
BOOT_5V: C3.1, U1.6 (BOOT)
CAN_EN: R95.2, U14.8 (EN/FLT)
CAN_GND: C95.2, D20.3 (common), J17.3, U14.11 (GND2), U14.15 (GISOIN), U14.16 (GISOIN), U14.17 (GISOIN)
CAN_H: D20.1 (A1), J17.1, JP7.1 (A), U14.19 (CANH)
CAN_L: D20.2 (A2), J17.2, R94.2, U14.18 (CANL)
CAN_RX: U3.114 (PD0), U14.5 (RXD)
CAN_STB: U3.117 (PD3), U14.4 (STB)
CAN_TERM: JP7.2 (B), R94.1
CAN_TX: U3.115 (PD1), U14.3 (TXD)
CAN_VISO: C95.1, U14.12 (VISOOUT), U14.13 (VSIN), U14.20 (VISOIN)
CHASSIS: J1.3, J3.10 (SHIELD), J4.S1 (SHIELD), J5.8, J5.SH
DI1: U3.4 (PE5), U10.4 (OUT1)
DI1_FIELD: D14.1 (A1), J14.1, R80.1
DI1_IN: R81.2, U10.15 (IN1)
DI1_SENSE: C80.1, R80.2, R81.1, U10.16 (SENSE1)
DI2: U3.5 (PE6), U10.5 (OUT2)
DI2_FIELD: D15.1 (A1), J14.2, R82.1
DI2_IN: R83.2, U10.10 (IN2)
DI2_SENSE: C81.1, R82.2, R83.1, U10.11 (SENSE2)
DI3: U3.60 (PE9), U11.4 (OUT1)
DI3_FIELD: D16.1 (A1), J14.3, R84.1
DI3_IN: R85.2, U11.15 (IN1)
DI3_SENSE: C82.1, R84.2, R85.1, U11.16 (SENSE1)
DI4: U3.64 (PE11), U11.5 (OUT2)
DI4_FIELD: D17.1 (A1), J14.4, R86.1
DI4_IN: R87.2, U11.10 (IN2)
DI4_SENSE: C83.1, R86.2, R87.1, U11.11 (SENSE2)
DI_FIELD_GND: C80.2, C81.2, C82.2, C83.2, D14.2 (A2), D15.2 (A2), D16.2 (A2), D17.2 (A2), J14.5, U10.9 (FGND2), U10.12 (SUB2), U10.13 (SUB1), U10.14 (FGND1), U11.9 (FGND2), U11.12 (SUB2), U11.13 (SUB1), U11.14 (FGND1)
EN_5V: R3.2, R4.1, U1.18 (EN)
ETH_CRS_DV: U3.43 (PA7), U7.11 (CRS_DV/MODE2)
ETH_LED1: R46.1, U7.3 (LED1/REGOFF)
ETH_LED1_K: J5.11, R46.2
ETH_LED2: R47.1, U7.2 (LED2/~INTSEL)
ETH_LED2_K: J5.9, R47.2
ETH_MDC: U3.27 (PC1), U7.13 (MDC)
ETH_MDIO: U3.36 (PA2), U7.12 (MDIO)
ETH_PHY_RESET: R45.2, U7.15 (~RST)
ETH_RBIAS: R40.1, U7.24 (RBIAS)
ETH_REF_CLK: U3.35 (PA1), U7.14 (~INT/REFCLKO)
ETH_RXD0: U3.44 (PC4), U7.8 (RXD0/MODE0)
ETH_RXD1: U3.45 (PC5), U7.7 (RXD1/MODE1)
ETH_RX_N: J5.6 (RD-), R44.2, U7.22 (RXN)
ETH_RX_P: J5.3 (RD+), R43.2, U7.23 (RXP)
ETH_TXD0: U3.128 (PG13), U7.17 (TXD0)
ETH_TXD1: U3.129 (PG14), U7.18 (TXD1)
ETH_TX_EN: U3.126 (PG11), U7.16 (TXEN)
ETH_TX_N: J5.2 (TD-), R42.2, U7.20 (TXN)
ETH_TX_P: J5.1 (TD+), R41.2, U7.21 (TXP)
ETH_VDDCR: C42.1, U7.6 (VDDCR)
ETH_XTAL_IN: C40.1, U7.5 (XTAL1/CLKIN), Y3.1
ETH_XTAL_OUT: C41.1, U7.4 (XTAL2), Y3.2
EXP_GPIO: J6.7, U3.123 (PD7)
EXP_UART_TX: J6.5, U3.69 (PB10)
FB_5V: R1.2, R2.1, U1.12 (FB)
FLASH_CS: U3.73 (PB12), U5.1 (~CS)
FLASH_HOLD: R28.2, U5.7 (~HOLD/~RESET/IO_{3})
FLASH_MISO: U3.75 (PB14), U5.2 (DO/IO_{1})
FLASH_MOSI: U3.76 (PB15), U5.5 (DI/IO_{0})
FLASH_SCK: U3.74 (PB13), U5.6 (CLK)
FLASH_WP: R27.2, U5.3 (~WP/IO_{2})
GND: BT1.2 (-), C1.2, C2.2, C4.2, C5.2, C6.2, C7.2, C8.2, C9.2, C10.2, C11.2, C12.2, C13.2, C14.2, C15.2, C16.2, C17.2, C18.2, C19.2, C20.2, C21.2, C22.2, C23.2, C24.2, C25.2, C28.2, C29.2, C30.2, C31.2, C32.2, C33.2, C40.2, C41.2, C42.2, C43.2, C44.2, C45.2, C46.2, C84.2, C85.2, C90.2, C92.2, C94.2, D1.2 (A2), D3.2 (A), D4.2 (A), J1.2, J2.3, J2.5, J2.9, J3.6 (VSS), J4.A1 (GND), J4.A12 (GND), J4.B1 (GND), J4.B12 (GND), J6.2, R2.2, R4.2, R5.2, R11.2, R15.2, R17.2, R19.2, R23.2, R24.2, R26.2, R40.2, R68.2, SW1.2, U1.13 (AGND), U1.14 (AGND), U1.15 (AGND), U1.17 (SYNC/MODE), U1.19 (NC_{GND}), U1.24 (PGND), U1.25 (PGND), U1.26 (PGND), U1.27 (NC_{GND}), U1.28 (NC_{GND}), U1.29 (NC_{GND}), U1.30 (NC_{GND}), U1.31 (AGND), U2.6 (GND), U2.7 (FSW), U2.8 (DEF), U2.15 (GND), U2.16 (GND), U2.17 (GND), U3.16 (VSS), U3.38 (VSS), U3.51 (VSS), U3.61 (VSS), U3.71 (VSS), U3.83 (VSS), U3.94 (VSS), U3.107 (VSS), U3.120 (VSS), U3.130 (VSS), U3.143 (VSS), U4.5 (VSS), U4.8 (EVI), U5.4 (GND), U6.2 (GND), U7.25 (VSS), U8.9 (GND), U8.19 (GND), U9.3 (DAISY), U9.4 (~REFSEL), U9.33 (DGND), U10.1 (GND1), U10.8 (GND1), U11.1 (GND1), U11.8 (GND1), U12.6 (GNDIO), U12.10 (GND1), U13.6 (GNDIO), U13.10 (GND1), U14.2 (IN), U14.6 (GNDIO), U14.10 (GND1)
HSE_IN: C11.1, U3.23 (PH0), Y1.1
HSE_OUT: C12.1, U3.24 (PH1), Y1.2
I2C_SCL: J6.3, R20.2, U3.139 (PB8), U4.3 (SCL)
I2C_SDA: J6.4, R21.2, U3.140 (PB9), U4.4 (SDA)
LED_FAULT: R13.1, U3.57 (PG1)
LED_FAULT_A: D4.1 (K), R13.2
LED_RUN: R12.1, U3.56 (PG0)
LED_RUN_A: D3.1 (K), R12.2
LSE_IN: C13.1, U3.8 (PC14), Y2.1
LSE_OUT: C14.1, U3.9 (PC15), Y2.2
NRST: C29.1, J2.10, J6.8, R10.2, SW1.1, U3.25 (NRST)
PGOOD_3V3: U2.4 (PG), U3.87 (PG2)
PGOOD_5V: R6.2, U1.16 (PGOOD), U3.88 (PG3)
RS485A_DIR: U3.118 (PD4), U12.3 (DE), U12.5 (~RE)
RS485A_EN: R91.2, U12.8 (EN/FLT)
RS485A_GND: C91.2, D18.3 (common), J15.3, U12.11 (GND2), U12.13 (MODE), U12.15 (GISOIN)
RS485A_N: D18.2 (A2), J15.2, R90.2, U12.18 (Z), U12.19 (B)
RS485A_P: D18.1 (A1), J15.1, JP5.1 (A), U12.17 (Y), U12.20 (A)
RS485A_RX: U3.122 (PD6), U12.4 (R)
RS485A_TERM: JP5.2 (B), R90.1
RS485A_TX: U3.119 (PD5), U12.2 (D)
RS485A_VISO: C91.1, U12.12 (VISOOUT), U12.16 (VISOIN)
RS485B_DIR: U3.81 (PD12), U13.3 (DE), U13.5 (~RE)
RS485B_EN: R93.2, U13.8 (EN/FLT)
RS485B_GND: C93.2, D19.3 (common), J16.3, U13.11 (GND2), U13.13 (MODE), U13.15 (GISOIN)
RS485B_N: D19.2 (A2), J16.2, R92.2, U13.18 (Z), U13.19 (B)
RS485B_P: D19.1 (A1), J16.1, JP6.1 (A), U13.17 (Y), U13.20 (A)
RS485B_RX: U3.78 (PD9), U13.4 (R)
RS485B_TERM: JP6.2 (B), R92.1
RS485B_TX: U3.77 (PD8), U13.2 (D)
RS485B_VISO: C93.1, U13.12 (VISOOUT), U13.16 (VISOIN)
RTC_INT: U3.10 (PF0), U4.2 (~INT)
RT_5V: R5.1, U1.10 (RT)
SD_CLK: J3.5 (CLK), U3.113 (PC12)
SD_CMD: J3.3 (CMD), U3.116 (PD2)
SD_D0: J3.7 (DAT0), U3.98 (PC8)
SD_D1: J3.8 (DAT1), U3.99 (PC9)
SD_D2: J3.1 (DAT2), U3.111 (PC10)
SD_D3: J3.2 (DAT3/CD), U3.112 (PC11)
SD_DETECT: J3.9 (DET), R22.2
SS_3V3: C9.1, U2.9 (SS/TR)
SS_5V: C6.1, U1.11 (SS/TRK)
SWCLK: J2.4, U3.109 (PA14(JTCK)
SWDIO: J2.2, U3.105 (PA13(JTMS)
SWO: J2.6, U3.133 (PB3(JTDO)
SW_3V3: L3.1, U2.1 (SW), U2.2 (SW), U2.3 (SW)
SW_5V: C3.2, L2.1, U1.1 (SW), U1.2 (SW), U1.3 (SW), U1.4 (SW), U1.5 (SW)
USB_CC1: J4.A5 (CC1), R23.1
USB_CC2: J4.B5 (CC2), R24.1
USB_DM: U3.103 (PA11), U6.6 (I/O1)
USB_DM_RAW: J4.A7 (D-), J4.B7 (D-), U6.1 (I/O1)
USB_DP: U3.104 (PA12), U6.4 (I/O2)
USB_DP_RAW: J4.A6 (D+), J4.B6 (D+), U6.3 (I/O2)
USB_VBUS: J4.A4 (VBUS), J4.A9 (VBUS), J4.B4 (VBUS), J4.B9 (VBUS), R25.1, U6.5 (VBUS)
USB_VBUS_SENSE: C32.1, R25.2, R26.1, U3.101 (PA9)
VCAP1: C24.1, U3.70 (VCAP)
VCAP2: C25.1, U3.142 (VCAP)
VCC_5V: C33.1, U1.8 (VCC)
VIN_FILTERED: C1.1, C2.1, L1.2, R3.1, R14.1, U1.20 (PVIN), U1.21 (PVIN), U1.22 (PVIN)
VIN_FUSED: D1.1 (A1), D2.1 (K), F1.2
VIN_MON: R14.2, R15.1, U3.26 (PC0)
VIN_PROTECTED: D2.2 (A), L1.1
VIN_RAW: F1.1, J1.1
WIFI_BOOT: R49.2, U3.66 (PE13), U8.8 (IO9)
WIFI_EN: R48.2, U3.63 (PE10), U8.2 (EN)
WIFI_UART_RX: J6.6, U3.58 (PE7), U8.12 (IO21/TXD)
WIFI_UART_TX: U3.59 (PE8), U8.11 (IO20/RXD)

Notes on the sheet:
1 — POWER INPUT, PROTECTION AND REGULATION (9–36 VDC)
2 — SECURE CONTROLLER, CLOCKS, DEBUG AND SUPERVISION
3 — RTC, FLASH, MICROSD AND USB-C SERVICE
4 — ETHERNET 10/100 RMII AND OPTIONAL WI-FI COPROCESSOR
5 — FOUR 0–10 V / 4–20 mA ANALOG INPUTS
6 — FOUR ISOLATED IEC 61131-2 TYPE 3 DIGITAL INPUTS
7 — TWO ISOLATED RS-485 PORTS AND ISOLATED CAN-FD
DESIGN LIMITS: monitoring only; no safety outputs; close current-mode jumpers only for 4–20 mA.
Isolation barriers and chassis bonding must be reviewed against the installation category before field deployment.

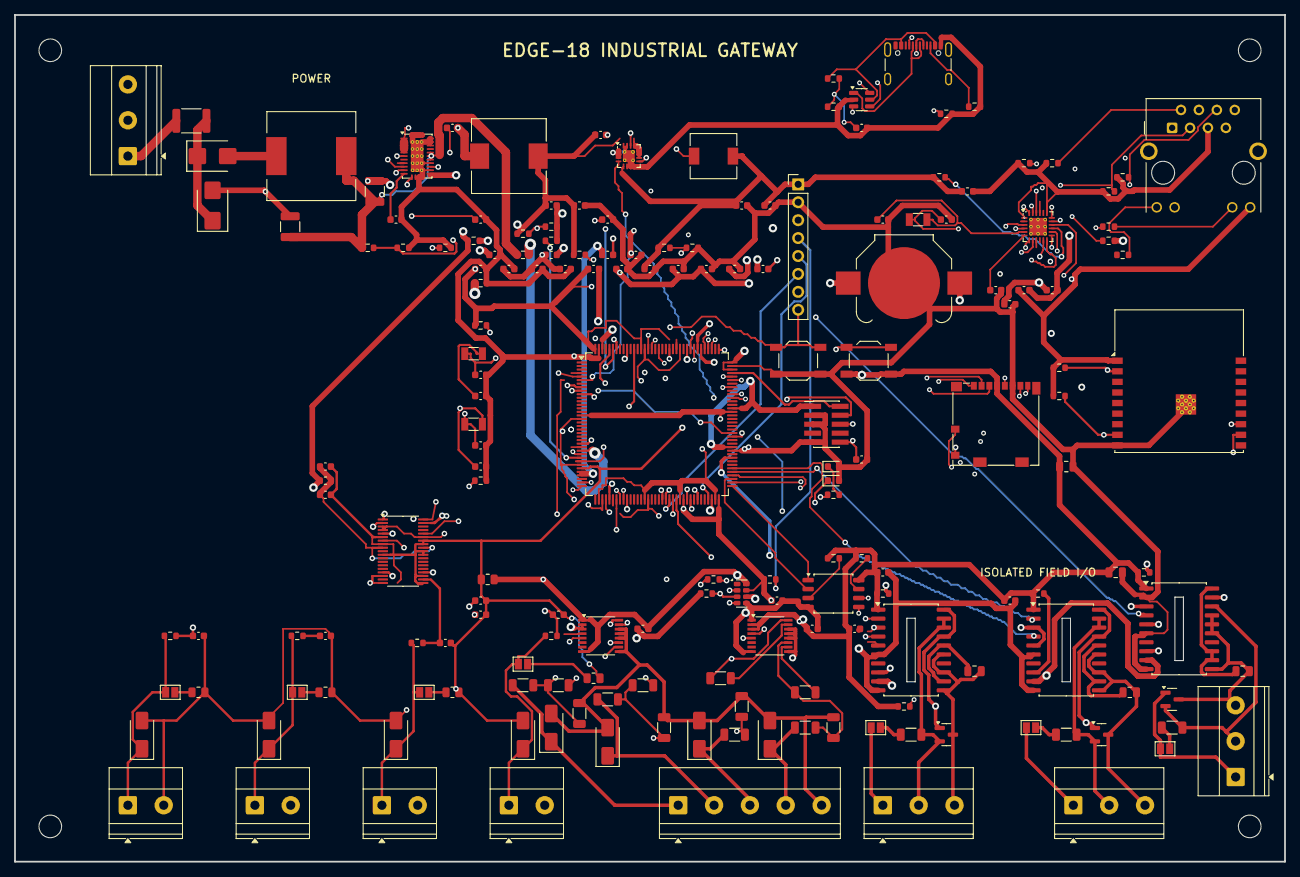
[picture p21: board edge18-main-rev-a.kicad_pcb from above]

Board: 4 copper layers, 180.0 x 120.0 mm, 185 parts (0 on the bottom side), 157 nets.

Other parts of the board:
H1, H3, H4, H6: MountingHole_3.2mm_M3

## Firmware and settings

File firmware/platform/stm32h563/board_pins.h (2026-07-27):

#ifndef EDGE18_STM32H563_BOARD_PINS_H
#define EDGE18_STM32H563_BOARD_PINS_H

/*
 * Single firmware-side source for the Rev. A signal assignment. The net and
 * physical pin are generated in docs/13-pinout-stm32h563-rev-a.md from KiCad;
 * changing this map requires changing and revalidating the native CAD.
 */
#define EDGE18_BOARD_SIGNAL_MAP(X) \
    X(DI1,              E,  5, "TIM/GPIO input") \
    X(DI2,              E,  6, "TIM/GPIO input") \
    X(RTC_INT,          F,  0, "EXTI input") \
    X(VIN_MON,          C,  0, "ADC input") \
    X(ETH_MDC,          C,  1, "ETH MDC") \
    X(MON_5V,           C,  2, "ADC input") \
    X(MON_3V3,          C,  3, "ADC input") \
    X(ETH_REF_CLK,      A,  1, "ETH RMII") \
    X(ETH_MDIO,         A,  2, "ETH MDIO") \
    X(ADC_CS,           A,  4, "GPIO output") \
    X(ADC_SCK,          A,  5, "SPI1 SCK") \
    X(ADC_MISO,         A,  6, "SPI1 MISO") \
    X(ETH_CRS_DV,       A,  7, "ETH RMII") \
    X(ETH_RXD0,         C,  4, "ETH RMII") \
    X(ETH_RXD1,         C,  5, "ETH RMII") \
    X(ADC_RESET,        B,  0, "GPIO output") \
    X(LED_RUN,          G,  0, "GPIO output") \
    X(LED_FAULT,        G,  1, "GPIO output") \
    X(WIFI_UART_RX,     E,  7, "UART7 RX") \
    X(WIFI_UART_TX,     E,  8, "UART7 TX") \
    X(DI3,              E,  9, "TIM/GPIO input") \
    X(WIFI_EN,          E, 10, "GPIO output") \
    X(DI4,              E, 11, "TIM/GPIO input") \
    X(WIFI_BOOT,        E, 13, "GPIO output") \
    X(EXP_UART_TX,      B, 10, "USART3 TX / expansion") \
    X(FLASH_CS,         B, 12, "GPIO output") \
    X(FLASH_SCK,        B, 13, "SPI2 SCK") \
    X(FLASH_MISO,       B, 14, "SPI2 MISO") \
    X(FLASH_MOSI,       B, 15, "SPI2 MOSI") \
    X(RS485B_TX,        D,  8, "USART3 TX") \
    X(RS485B_RX,        D,  9, "USART3 RX") \
    X(RS485B_DIR,       D, 12, "USART3 DE") \
    X(PGOOD_3V3,        G,  2, "EXTI input") \
    X(PGOOD_5V,         G,  3, "EXTI input") \
    X(SD_D0,            C,  8, "SDMMC1 D0") \
    X(SD_D1,            C,  9, "SDMMC1 D1") \
    X(USB_VBUS_SENSE,   A,  9, "USB FS VBUS") \
    X(USB_DM,           A, 11, "USB FS DM") \
    X(USB_DP,           A, 12, "USB FS DP") \
    X(SWDIO,            A, 13, "SWDIO") \
    X(SWCLK,            A, 14, "SWCLK") \
    X(SD_D2,            C, 10, "SDMMC1 D2") \
    X(SD_D3,            C, 11, "SDMMC1 D3") \
    X(SD_CLK,           C, 12, "SDMMC1 CK") \
    X(CAN_RX,           D,  0, "FDCAN1 RX") \
    X(CAN_TX,           D,  1, "FDCAN1 TX") \
    X(SD_CMD,           D,  2, "SDMMC1 CMD") \
    X(CAN_STB,          D,  3, "GPIO output") \
    X(RS485A_DIR,       D,  4, "USART2 DE") \
    X(RS485A_TX,        D,  5, "USART2 TX") \
    X(RS485A_RX,        D,  6, "USART2 RX") \
    X(EXP_GPIO,         D,  7, "GPIO expansion") \
    X(ETH_TX_EN,        G, 11, "ETH RMII") \
    X(ETH_TXD0,         G, 13, "ETH RMII") \
    X(ETH_TXD1,         G, 14, "ETH RMII") \
    X(SWO,              B,  3, "SWO") \
    X(ADC_MOSI,         B,  5, "SPI1 MOSI") \
    X(I2C_SCL,          B,  8, "I2C1 SCL") \
    X(I2C_SDA,          B,  9, "I2C1 SDA")

#define EDGE18_HSE_HZ 25000000UL
#define EDGE18_LSE_HZ 32768UL
#define EDGE18_SYSTEM_CLOCK_HZ 250000000UL
#define EDGE18_WATCHDOG_WINDOW_MS 2000UL

#endif

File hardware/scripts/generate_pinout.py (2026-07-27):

#!/usr/bin/env python3
"""Generate the revision-controlled STM32H563 pin table from native CAD."""

from __future__ import annotations

import os
from pathlib import Path
import sys

ROOT = Path(__file__).resolve().parents[2]
TOOL_ROOT = Path(
    os.environ.get(
        "EDGE18_TOOL_ROOT",
        "/mnt/eftx-data/cache/antenna-coupler-tools",
    )
)
KICAD_ROOT = TOOL_ROOT / "kicad/root"
EDA_SITE = TOOL_ROOT / "python-eda/lib/python3.13/site-packages"
sys.path.insert(0, str(EDA_SITE))
sys.path.insert(0, str(KICAD_ROOT / "usr/lib/python3/dist-packages"))

import pcbnew
from kiutils.symbol import SymbolLib


BOARD = ROOT / "hardware/edge18-main/edge18-main-rev-a.kicad_pcb"
SYMBOLS = (
    ROOT / "hardware/libraries/frozen/MCU_ST_STM32H5.kicad_sym"
)
OUTPUT = ROOT / "docs/13-pinout-stm32h563-rev-a.md"


def domain(net: str) -> str:
    if net == "RESERVADO":
        return "RESERVADO"
    if net in {
        "GND",
        "AGND",
        "3V3",
        "3V3_A",
        "3V3_RTC",
        "VCAP1",
        "VCAP2",
    }:
        return "ALIMENTAÇÃO"
    prefixes = (
        ("ETH_", "ETHERNET"),
        ("RS485A_", "RS-485 A"),
        ("RS485B_", "RS-485 B"),
        ("ADC_", "ADC"),
        ("AI", "ANALÓGICO"),
        ("DI", "DIGITAL"),
        ("SD_", "MICROSD"),
        ("FLASH_", "FLASH"),
        ("USB_", "USB"),
        ("WIFI_", "WI-FI"),
        ("CAN_", "CAN"),
        ("SW", "DEBUG"),
        ("HSE_", "CLOCK"),
        ("LSE_", "CLOCK"),
        ("RTC_", "RTC"),
        ("PGOOD_", "SUPERVISÃO"),
        ("VIN_", "SUPERVISÃO"),
        ("5V_", "SUPERVISÃO"),
        ("3V3_", "SUPERVISÃO"),
        ("LED_", "STATUS"),
        ("EXP_", "EXPANSÃO"),
    )
    for prefix, name in prefixes:
        if net.startswith(prefix):
            return name
    if net in {"NRST", "BOOT0"}:
        return "DEBUG"
    if net.startswith("I2C_"):
        return "I²C"
    return "CONTROLE"


def main() -> int:
    board = pcbnew.LoadBoard(str(BOARD))
    footprint = board.FindFootprintByReference("U3")
    if footprint is None:
        raise RuntimeError("U3 not found in board")
    nets = {
        str(pad.GetNumber()): pad.GetNetname() or "RESERVADO"
        for pad in footprint.Pads()
    }

    library = SymbolLib().from_file(str(SYMBOLS))
    symbol = library.symbols[0]
    names = {
        pin.number: pin.name
        for unit in symbol.units
        for pin in unit.pins
    }

    lines = [
        "# Pinout STM32H563ZIT6 — EDGE-18 Rev. A",
        "",
        "Tabela gerada diretamente do símbolo congelado e do PCB nativo. "
        "`RESERVADO` significa pad sem net nesta revisão; não autoriza uso "
        "sem atualizar esquemático, PCB, firmware e análise de conflitos.",
        "",
        "| Pino | Nome físico | Net Rev. A | Domínio |",
        "|---:|---|---|---|",
    ]
    for number in range(1, 145):
        key = str(number)
        net = nets.get(key, "RESERVADO")
        lines.append(
            f"| {number} | `{names.get(key, 'N/D')}` | "
            f"`{net}` | {domain(net)} |"
        )
    assigned = sum(net != "RESERVADO" for net in nets.values())
    lines.extend(
        (
            "",
            "## Controle",
            "",
            "- encapsulamento: LQFP-144, passo 0,50 mm;",
            f"- pads com net atribuída: {assigned};",
            f"- pads reservados: {144 - assigned};",
            "- RMII, SWD e alimentação têm prioridade sobre expansões;",
            "- as funções alternativas devem ser reproduzidas no projeto "
            "STM32Cube/HAL e conferidas no build do alvo;",
            "- a fonte normativa elétrica continua sendo o esquemático e o "
            "PCB da Rev. A.",
            "",
        )
    )
    OUTPUT.write_text("\n".join(lines), encoding="utf-8")
    print(f"Generated {OUTPUT.relative_to(ROOT)}")
    return 0


if __name__ == "__main__":
    raise SystemExit(main())

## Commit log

2026-07-27 Start EDGE-18 parent platform development
    [edge18-p0-assembly.FCStd, edge18-p0-assembly.step, edge18-p0-enclosure-base.step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]
2026-07-27 Complete frozen EDGE-18 Rev A engineering review
    [edge18-main-rev-a-source.csv, edge18-main-rev-a.kicad_pcb, edge18-main-rev-a.kicad_sch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]
